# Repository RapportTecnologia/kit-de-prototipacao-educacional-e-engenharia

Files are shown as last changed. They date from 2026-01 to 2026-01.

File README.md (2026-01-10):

# Kit Educacional e Prototipação Rapport


Visits (https://hits.sh/github.com/RapportTecnologia/kit-de-prototipacao-educacional-e-engenharia/)





* **Versão atual:** 0.6

---

## Visão geral

Este repositório contém o projeto do **Kit Educacional e de Prototipação** da Rapport (Kit Educacional e Prototipação Rapport - KEPR), incluindo a documentação do barramento/modularidade (UCE) e os arquivos de CAD eletrônico em KiCad.

O KEPR é um ecossistema de hardware para **prototipação e aprendizagem** em sistemas embarcados e IoT: uma base modular que permite trocar o microcontrolador sem “quebrar” o restante do projeto, além de integrar **módulos de rede e wireless** (WiFi, Bluetooth e outros) quando essas interfaces não estão disponíveis nativamente no módulo principal.

A proposta é reduzir atrito no desenvolvimento (e no estudo) de firmware e hardware, organizando um padrão de conexão e expansão para acelerar testes, validações e iterações. O projeto busca compatibilidade com famílias como **STM32**, **ESP32**, **AVR (ATtiny/ATmega)** e outros fabricantes.

Este projeto nasce inicialmente com fins **educacionais** (estudos e evolução técnica de Carlos Delfino) e **pode vir a se tornar comercial** no futuro. Ainda assim, o projeto permanece sob a mesma licença para que outras pessoas e empresas possam **usar, adaptar e redistribuir** da forma que desejarem.

**Licença:** Creative Commons **CC BY 4.0** (atribuição). Se você quer colaborar, você pode:

- propor melhorias na arquitetura do barramento e dos módulos;
- revisar esquemáticos/footprints e sugerir boas práticas de layout;
- abrir issues com dúvidas, críticas e ideias;
- enviar PRs com correções, melhorias e novos módulos.

---

## Documentação

- **UCE (placa / barramento):** `UCE_BOARD.md`
- **Changelog:** `CHANGELOG.md`

---

## Projeto KiCad

O projeto principal atualmente está em:

- `kicad/KEPR/`

---

## Repositório Git (origem)

- `git@github.com:RapportTecnologia/kit-de-prototipacao-educacional-e-engenharia.git`

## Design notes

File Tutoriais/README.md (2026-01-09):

# Tutoriais


Visits (https://hits.sh/github.com/RapportTecnologia/kit-de-prototipacao-educacional-e-engenharia_Tutoriais_README)

 Esta pasta reúne tutoriais e anotações técnicas para **relembrar** (e padronizar) conceitos de eletrônica usados no desenvolvimento do projeto.
 Como o objetivo do KEPR é educacional, estes textos também servem como material de apoio para quem estiver estudando, montando, depurando ou evoluindo o hardware/firmware.

## Como usar estes tutoriais

- Leia os arquivos na ordem sugerida quando fizer sentido (ex.: alimentação antes de instrumentação).
- Sempre que um tutorial citar referências do repositório (ex.: esquemático, `.ioc` do CubeMX, firmware), use-o como ponto de partida para encontrar a “fonte de verdade” das configurações.
- Quando algo for alterado no hardware/firmware, atualize também o tutorial correspondente para manter a documentação coerente.

## Índice de conteúdos

- **Alimentação e barramentos (Power Rails)**
  - [`POWER.md`](./POWER.md): visão geral dos rails do KEPR, função de cada tensão e boas práticas de uso externo.
- **Medição de corrente com shunt + OPAMP + ADC no STM32G4**
  - [`OPAMPS.md`](./OPAMPS.md): mapeamento de pinos, relação ADC→tensão→corrente, parâmetros de calibração e exemplo numérico.
- **Proteção elétrica (tensão reversa e sobretensão)**
  - [`PROTECAO_TENSAO_REVERSA_E_SOBRETENSAO.md`](./PROTECAO_TENSAO_REVERSA_E_SOBRETENSAO.md): topologias de proteção para rails expostos ao usuário (incluindo bloqueio de backfeed e OVP).

## Objetivo do material

- **Didático**: explicar “por que” e “como” cada bloco do sistema funciona.
- **Prático**: registrar decisões de projeto e facilitar manutenção (debug, troca de componentes, mudanças no CubeMX, etc.).
- **Reutilizável**: permitir que partes do projeto (power, proteção, instrumentação) sejam reaproveitadas em outros designs.

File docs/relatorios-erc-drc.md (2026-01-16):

---
layout: page
title: "Relatórios ERC e DRC"
subtitle: "Saídas do KiCad (ERC/DRC)"
permalink: /relatorios-erc-drc/
---

Esta página é gerada automaticamente pelo CI a partir dos relatórios do KiCad.

## Resumo

### ERC (Electrical Rules Check)

- Gerado em: `2026-01-16T01:00:54+0000`
- Erros: **118**
- Avisos: **153**

### DRC (Design Rules Check)

- Gerado em: `2026-01-16T01:00:56+0000`
- Violações DRC: **177**
- Pads desconectados: **117**
- Erros: **126**
- Avisos: **173**

## Relatórios completos

- [Abrir `erc.rpt`](https://github.com/RapportTecnologia/kit-de-prototipacao-educacional-e-engenharia/blob/main/kicad/KEPR/reports/erc.rpt)
- [Abrir `drc.rpt`](https://github.com/RapportTecnologia/kit-de-prototipacao-educacional-e-engenharia/blob/main/kicad/KEPR/reports/drc.rpt)

## Principais ocorrências (amostra)

### ERC

- `[lib_symbol_issues]: The current configuration does not include the symbol library '10141995-005RLF'`
- `[global_label_dangling]: Global label not connected anywhere else in the schematic`
- `[lib_symbol_issues]: The current configuration does not include the symbol library 'Connector_Generic'`
- `[unconnected_wire_endpoint]: Unconnected wire endpoint`
- `[lib_symbol_issues]: The current configuration does not include the symbol library 'Connector_Generic'`
- `[lib_symbol_issues]: The current configuration does not include the symbol library 'power'`
- `[lib_symbol_issues]: The current configuration does not include the symbol library 'power'`
- `[lib_symbol_issues]: The current configuration does not include the symbol library 'Connector_Generic'`
- `[lib_symbol_issues]: The current configuration does not include the symbol library 'PCM_SL_Pin_Headers'`
- `[lib_symbol_issues]: The current configuration does not include the symbol library 'power'`

### DRC

- `[track_dangling]: Track has unconnected end`
- `[track_dangling]: Track has unconnected end`
- `[track_dangling]: Track has unconnected end`
- `[track_dangling]: Track has unconnected end`
- `[track_dangling]: Track has unconnected end`
- `[track_dangling]: Track has unconnected end`
- `[via_dangling]: Via is not connected or connected on only one layer`
- `[via_dangling]: Via is not connected or connected on only one layer`
- `[via_dangling]: Via is not connected or connected on only one layer`
- `[via_dangling]: Via is not connected or connected on only one layer`

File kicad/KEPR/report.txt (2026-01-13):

Informação: Processando o símbolo 'J24:Connector_PinHeader_2.54mm:PinHeader_2x02_P2.54mm_Vertical'.
Informação: Processando o símbolo 'J8:'.
Informação: Processando o símbolo 'Brd1:SSD1306:128x64OLED'.
Informação: Processando o símbolo 'J10:Connector_PinHeader_2.54mm:PinHeader_2x40_P2.54mm_Vertical'.
Informação: Processando o símbolo 'J11:Connector_PCBEdge:SODIMM-260_DDR4_H4.0-5.2_OrientationStd_Socket'.
Informação: Processando o símbolo 'J12:Connector_PinHeader_2.54mm:PinHeader_1x20_P2.54mm_Vertical'.
Informação: Processando o símbolo 'J13:Connector_PinHeader_2.54mm:PinHeader_2x02_P2.54mm_Vertical'.
Informação: Processando o símbolo 'J16:Connector_PinHeader_2.54mm:PinHeader_1x10_P2.54mm_Vertical'.
Informação: Processando o símbolo 'J17:Connector_PinHeader_2.54mm:PinHeader_1x20_P2.54mm_Vertical'.
Informação: Processando o símbolo 'J19:Connector_PinHeader_2.54mm:PinHeader_1x20_P2.54mm_Vertical'.
Informação: Processando o símbolo 'J22:Barrel Jack:BarrelJack_Horizontal'.
Informação: Processando o símbolo 'J23:Connector_PinHeader_2.54mm:PinHeader_1x10_P2.54mm_Vertical'.
Informação: Processando o símbolo 'J9:Connector_PinHeader_2.54mm:PinHeader_2x40_P2.54mm_Vertical'.
Informação: Processando o símbolo 'J26:Connector_PinHeader_2.54mm:PinHeader_2x03_P2.54mm_Vertical'.
Informação: Processando o símbolo 'J30:Connector_PinHeader_2.54mm:PinHeader_2x02_P2.54mm_Vertical'.
Informação: Processando o símbolo 'PS1:TDN 5WISM Series, 5 Watt:CONV_TDN5-2411WISM'.
Informação: Processando o símbolo 'PS2:TDN 5WISM Series, 5 Watt:CONV_TDN5-2411WISM'.
Informação: Processando o símbolo 'PS3:TDN 5WISM Series, 5 Watt:CONV_TDN5-2411WISM'.
Informação: Processando o símbolo 'U1:REF193:SOIC127P600X175-8N'.
Informação: Processando o símbolo 'U2:Package_QFP:LQFP-48_7x7mm_P0.5mm'.
Informação: Processando o símbolo 'U3:Package_TO_SOT_SMD:SOT-223-3_TabPin2'.
Informação: Processando o símbolo 'U4:Package_TO_SOT_SMD:SOT-223-3_TabPin2'.
Informação: Total de avisos: 5, erros: 2.
Informação: Processando o símbolo 'J4:Connector_IDC:IDC-Header_2x15-1MP_P2.54mm_Latch_Vertical'.
Informação: Processando o símbolo 'IC1:APS12628LLHALTBAP'.
Informação: Processando o símbolo 'IC2:APS12628LLHALTBAP'.
Informação: Processando o símbolo 'C5:Capacitor:C_0805_2012Metric'.
Informação: Processando o símbolo 'IC3:APS12628LLHALTBAP'.
Informação: Processando o símbolo 'C4:Capacitor:C_0805_2012Metric'.
Informação: Processando o símbolo 'C3:Capacitor:C_0805_2012Metric'.
Informação: Processando o símbolo 'J1:Connector_PinHeader_2.54mm:PinHeader_1x20_P2.54mm_Vertical'.
Informação: Processando o símbolo 'J3:Connector_IDC:IDC-Header_2x12_P2.54mm_Latch9.5mm_Vertical'.
Informação: Processando o símbolo 'C2:Capacitor:C_0805_2012Metric'.
Informação: Processando o símbolo 'C1:Capacitor:C_0805_2012Metric'.
Informação: Processando o símbolo 'BT1:Battery:BatteryHolder_Multicomp_BC-2001_1x2032'.
Informação: Processando o símbolo 'J5:Connector_IDC:IDC-Header_2x08_P2.54mm_Latch12.0mm_Vertical'.
Informação: Processando o símbolo 'J6:Connector_PinHeader_2.54mm:PinHeader_2x20_P2.54mm_Vertical'.
Informação: Processando o símbolo 'J7:'.
Adiciona Brd1 (footprint 'SSD1306:128x64OLED').

Troca o footprint IC1 de 'ACS37041:APS12628LLHALTBAP' para 'APS12628LLHALTBAP'.
Troca o footprint IC2 de 'ACS37041:APS12628LLHALTBAP' para 'APS12628LLHALTBAP'.
Troca o footprint IC3 de 'ACS37041:APS12628LLHALTBAP' para 'APS12628LLHALTBAP'.
Atenção: Nenhuma rede foi encontrada para o componente J22 ilha 3 (nenhum pino 3 no símbolo).
Atenção: Nenhuma rede foi encontrada para o componente J4 ilha MP (nenhum pino MP no símbolo).
Atenção: Nenhuma rede foi encontrada para o componente J4 ilha MP (nenhum pino MP no símbolo).
Atenção: Nenhuma rede foi encontrada para o componente J11 ilha MP (nenhum pino MP no símbolo).
Atenção: Nenhuma rede foi encontrada para o componente J11 ilha MP (nenhum pino MP no símbolo).
Erro: Não é possível adicionar J8 (nenhum footprint associado).
Erro: Não é possível adicionar J7 (nenhum footprint associado).

Informação: Total de avisos: 5, erros: 2.

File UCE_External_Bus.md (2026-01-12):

# UCE – External Bus (UCE_External_Bus)

* **Versão:** 0.6
* **Fonte:** `kicad/KEPR/UCE_External_Bus.kicad_sch` e `UCE_BOARD.md`

---

## 1. Objetivo

Este documento descreve o **barramento externo** da arquitetura **UCE (Universal Carrier Ecosystem)**, isto é, o conjunto de sinais expostos pela Carrier/Baseboard para conexão com:

- Periféricos externos (sensores, atuadores, módulos)
- Placas de expansão
- Cabeamento/painel/IO externo

A intenção é padronizar um **contrato elétrico e funcional** para que diferentes módulos MCU/SoC possam ser trocados sem alterar a base, conforme definido em `UCE_BOARD.md`.

---

## 2. Convenções e Domínios Elétricos

### 2.1 Domínios de alimentação

Os seguintes domínios aparecem na especificação do UCE e são utilizados/propagados no barramento:

- `VCC_12V`
- `VCC_5V`
- `VCC_3V3`
- `VCC_1V8`
- `GND`

### 2.2 Referência e níveis lógicos

- `VREF_IO`: referência de IO (associada ao domínio lógico exposto).
- `PWR_GOOD`: sinal de “power good” do sistema.

### 2.3 Direção dos sinais

Neste documento:

- **`MCU → EXT`** significa sinal dirigido do módulo MCU para o conector externo.
- **`EXT → MCU`** significa sinal dirigido do conector externo para o módulo MCU.
- **`Bidirecional`** significa que a direção depende da aplicação (ex.: I²C) ou é intrinsecamente bidirecional.

> Observação: no esquemático KiCad, os `global_label` não carregam semântica de direção; portanto, as direções abaixo seguem a convenção típica de cada barramento.

---

## 3. Conectores presentes no esquemático

No `UCE_External_Bus.kicad_sch` aparecem, no mínimo, os seguintes conectores:

- **J1**: `Conn_02x20_Odd_Even` (2x20)
- **J3**: `Conn_02x40_Odd_Even` (2x40)
- **J4**: `Conn_02x40_Odd_Even` (2x40)

> Importante: a **pinagem (pino ↔ sinal)** não fica diretamente disponível como texto simples no `.kicad_sch` (a conectividade é definida por geometrias/UUIDs). Para gerar uma tabela 100% fiel automaticamente, o caminho mais robusto é exportar **netlist/BOM** via KiCad ou gerar um relatório de conectividade. Se você quiser, eu consigo completar a pinagem com base em um export (ex.: netlist IPC-2581/CSV/pos/relatório do KiCad) que você me fornecer.

---

## 4. Catálogo de sinais do Barramento Externo

Abaixo está o catálogo dos sinais observados no esquemático (principalmente via `global_label`) e alinhados à nomenclatura da UCE.

### 4.1 Alimentação e controle

| Sinal | Tipo | Direção  | Observação |
| --- | --- | --- | --- |
| `VCC_12V` | Power | — | Alimentação 12 V |
| `VCC_5V` | Power | — | Alimentação 5 V |
| `VCC_3V3` | Power | — | Alimentação 3,3 V |
| `VCC_1V8` | Power | — | Alimentação 1,8 V |
| `GND` | Power | — | Terra |
| `VREF_IO` | Referência  | — | Referência para IO/level shifting |
| `PWR_GOOD`  | Status | MCU → EXT | Indica tensões estáveis (ou habilitação do domínio) |

### 4.2 Sinais de boot/reset/enable

| Sinal | Tipo | Direção  | Observação |
| --- | --- | --- | --- |
| `MCU_EN` | Controle | EXT → MCU | Enable do módulo/MCU (conforme arquitetura) |
| `MCU_BOOT0` | Controle | EXT → MCU | Seleção de boot/perfil (dependente do MCU) |

### 4.3 I²C

| Sinal | Tipo | Direção | Observação |
| --- | ---- | --- | --- |
| `I2C0_SDA` | I²C | Bidirecional (open-drain) | Data I²C0  |
| `I2C0_SCL` | I²C | Bidirecional (open-drain) | Clock I²C0  |
| `I2C1_SDA` | I²C | Bidirecional (open-drain) | Data I²C1  |
| `I2C1_SCL` | I²C | Bidirecional (open-drain) | Clock I²C1  |
| `I2C2_SDA` | I²C | Bidirecional (open-drain) | Data I²C2 |
| `I2C2_SCL` | I²C | Bidirecional (open-drain) | Clock I²C2  |

> Nota: o esquemático listado aqui inclui alguns sinais I²C pontuais; a UCE prevê pares `SCL/SDA` por barramento.

### 4.4 SPI

#### SPI0

| Sinal | Tipo | Direção  | Observação |
| --- | ---- | --- | --- |
| `SPI0_SCK`  | SPI  | MCU → EXT | Clock |
| `SPI0_MOSI` | SPI  | MCU → EXT | Master Out / Slave In |
| `SPI0_MISO` | SPI  | EXT → MCU | Master In / Slave Out |
| `SPI0_CS0`  | SPI  | MCU → EXT | Chip Select 0 |
| `SPI0_CS1`  | SPI  | MCU → EXT | Chip Select 1 |

#### SPI1

| Sinal | Tipo | Direção  | Observação  |
| --- | ---- | --- | --- |
| `SPI1_CS0` | SPI  | MCU → EXT | Chip Select 0 |
| `SPI1_SCK` | SPI  | MCU → EXT | Clock |
| `SPI1_MOSI` | SPI  | MCU → EXT | Master Out / Slave In |
| `SPI1_MISO` | SPI  | EXT → MCU | Master In / Slave Out |

### 4.5 UART

| Sinal | Tipo | Direção  | Observação |
| --- | ---- | --- | --- |
| `UART0_TX` | UART | MCU → EXT | Transmit |
| `UART0_RX` | UART | EXT → MCU | Receive |
| `UART1_TX` | UART | MCU → EXT | Transmit |
| `UART1_RX` | UART | EXT → MCU | Receive |
| `UART2_TX` | UART | MCU → EXT | Transmit |
| `UART2_RX` | UART | EXT → MCU | Receive |

> Nota: a UCE define `UART0..UART3` e, no caso da `UART0`, sinais de controle adicionais. Nem todos aparecem explicitamente neste sheet do barramento externo.

### 4.6 GPIO e PWM

| Sinal | Tipo | Direção | Observação |
| --- | ---- | --- | --- |
| `GPIO1` | GPIO | Bidirecional | Uso geral |
| `GPIO3` | GPIO | Bidirecional | Uso geral |
| `GPIO6` | GPIO | Bidirecional | Uso geral |
| `GPIO7` | GPIO | Bidirecional | Uso geral |
| `GPIO8` | GPIO | Bidirecional | Uso geral |
| `GPIO9` | GPIO | Bidirecional | Uso geral |
| `PWM1`  | PWM  | MCU → EXT | Saída PWM |
| `PWM3`  | PWM  | MCU → EXT | Saída PWM |
| `PWM6`  | PWM  | MCU → EXT | Saída PWM |

### 4.7 IR

| Sinal | Tipo | Direção  | Observação |
| --- | ---- | --- | --- |
| `IR_TX_OUT` | IR | MCU → EXT | Transmissão IR |

### 4.8 Analógicos (ADC/DAC)

| Sinal | Tipo | Direção  | Observação |
| --- | --- | --- | --- |
| `AIN3`  | Analógico | EXT → MCU | Entrada analógica |
| `AOUT1` | Analógico | MCU → EXT | Saída analógica  |

### 4.9 Áudio (I²S)

| Sinal | Tipo | Direção  | Observação |
| --- | ---- | --- | --- |
| `I2S_BCLK` | I²S | MCU → EXT | Bit clock |
| `I2S_LRC` | I²S | MCU → EXT | Left/Right clock |
| `I2S_SD` | I²S | MCU → EXT | Serial data |

### 4.10 SDIO

| Sinal | Tipo | Direção | Observação |
| --- | ---- | --- | --- |
| `SDIO_D0` | SDIO | Bidirecional | Data 0 |
| `SDIO_D2` | SDIO | Bidirecional | Data 2 |

### 4.11 Debug

| Sinal | Tipo | Direção | Observação |
| --- | --- | --- | --- |
| `DBG_VREF` | Debug ref | — | Referência do domínio de debug |

### 4.12 Reservados

O esquemático contém múltiplos sinais rotulados como `RESERVED`. Estes pinos/sinais estão reservados para expansão futura, uso específico de variantes, ou compatibilidade.

---

## 5. Recomendações de uso

- **Respeite `VIO_BANKx`**: ao conectar periféricos, considere o banco de IO associado e o nível lógico esperado (3V3/5V/1V8).
- **I²C (open-drain)**: use pull-ups coerentes com `VIO_BANKx`/`VREF_IO` e com o perfil do módulo.
- **SPI**: mantenha `SCK/MOSI/MISO/CSx` curtos em cabo/placa de expansão, e considere GND adjacente quando disponível.
- **Analógico**: trate `AINx/AOUTx` como sinais sensíveis (roteamento/filtragem/impedância de fonte).

---

## 6. Como completar a pinagem (pino ↔ sinal)

Se você quiser que eu gere tabelas de pinagem do tipo “J3 pino 1 = …”, preciso de uma fonte de conectividade exportada pelo KiCad, por exemplo:

- Export de netlist/relatório de conectividade
- Print/CSV de “Pin assignments” do conector
- Ou um PDF do esquemático (para leitura visual)

Com isso, eu atualizo este arquivo adicionando:

- Tabela por conector (J1/J3/J4)
- Mapa por função (Power/IO/Bus) indicando exatamente onde cada sinal está.

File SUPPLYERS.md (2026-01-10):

Neste arquivo reuno sites que são referência em componentes, distribuidores e fontes de Simbolos, Footprints e modelos 3D (principalmente para KiCad), além de fabricantes de PCBs.

## Fornecedores (componentes eletrônicos)

### Distribuidores globais

* <https://www.mouser.com/>
* <https://www.digikey.com/>
* <https://www.arrow.com/>
* <https://www.farnell.com/> (element14 / Newark)
* <https://www.rs-online.com/>
* <https://www.tme.eu/>
* <https://lcsc.com/> (muito usado junto ao ecossistema JLCPCB)

### Marketplaces / varejo

* <https://www.aliexpress.com/>
* <https://www.amazon.com/> (varia por região)
* <https://www.ebay.com/>

### Brasil (exemplos)

* <https://www.baudaeletronica.com.br/>
* <https://www.filipeflop.com/>
* <https://www.usinainfo.com.br/>
* <https://www.multcomercial.com.br/> (Multi Comercial)
* <https://www.mercadolivre.com.br/>

## Símbolos / Footprints / Modelos 3D (KiCad)

### Bibliotecas oficiais / base

* <https://www.kicad.org/libraries/> (bibliotecas oficiais do KiCad)
* <https://gitlab.com/kicad/libraries> (repositórios oficiais: símbolos, footprints e 3D)
* <https://gitlab.com/kicad/libraries/kicad-footprints>

### Bibliotecas e geradores comunitários

* <https://www.snapeda.com/> (símbolos/footprints e alguns modelos 3D)
* <https://www.samacsys.com/> (Library Loader; exporta para KiCad)
* <https://www.ultralibrarian.com/> (CAD + símbolos/footprints)
* <https://componentsearchengine.com/>

### Modelos 3D (STEP/WRL)

* <https://grabcad.com/library>
* <https://www.traceparts.com/>
* <https://www.3dcontentcentral.com/>
* <https://www.partcommunity.com/>

### Plugins / ferramentas úteis (KiCad)

* <https://www.kicad.org/external-tools/> (ecossistema de ferramentas e integrações)
* <https://github.com/easyw/kicad-stepup> (KiCad <-> FreeCAD: STEP, posicionamento e ajustes 3D)

## Fabricantes de PCB / PCBA

* <https://jlcpcb.com/> (PCB e montagem/PCBA)
* <https://www.pcbway.com/> (PCB e montagem/PCBA)
* <https://www.seeedstudio.com/fusion_pcb.html> (Seeed Fusion)
* <https://www.elecrow.com/pcb-manufacturing.html> (Elecrow)
* <https://oshpark.com/> (ótimo para protótipos pequenos; foco EUA)
* <https://aisler.net/> (foco UE; boa experiência para prototipagem)
* <https://www.allpcb.com/>

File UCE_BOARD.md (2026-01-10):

# UCE – Universal Carrier Ecosystem

* **Versão:** 0.6
  **Status:** Draft de Arquitetura
  **Autor:** Carlos Delfino
  **Objetivo:** Plataforma universal modular para microcontroladores e SoCs para prototipação e aprendizado IoT e Embarcado

---

## 1. Visão Geral

O **UCE – Universal Carrier Ecosystem** é uma arquitetura modular de hardware projetada para permitir a substituição transparente de:

- Microcontroladores (ATtiny, ATmega, ESP32, STM32, NXP, etc.)
- SoCs com maior capacidade (ex.: Cortex-A)
- Módulos de rede (SPI Ethernet, RMII, RGMII/Switch)
- Módulos de gravação e depuração (J-Link, J-ICE, CMSIS-DAP, AVR-ISP, etc.)

sem a necessidade de alterar a **placa base (Carrier)**.

A proposta é criar um **contrato elétrico e funcional** entre módulos, inspirado em padrões industriais como SMARC e COM Express, porém adaptado ao universo de MCUs.

---

## 2. Arquitetura do Sistema

O ecossistema é composto por quatro blocos principais:

- **Carrier/Baseboard (fixa)**Fornece alimentação, conectores externos, level shifting por bancos, proteção e roteamento.
- **MCU Module (trocável)**Contém o microcontrolador/SoC, clock, boot, debug e opcionalmente ADC/DAC externos acoplados.
- **Network Module (trocável)**Implementa Ethernet conforme capacidade do MCU:

  - SPI: W5500 / ENC28J60
  - RMII: PHY dedicado
  - RGMII: Switch KSZ9893 ou similar
- **Debug/Program Module (trocável)**
  Implementa SWD, JTAG, ISP, UPDI, Serial Boot, USB-Debug, etc.

---

## 3. Princípios de Projeto

- A **base não conhece o MCU**, apenas o contrato UCE
- ADC e DAC pertencem ao **MCU Module**
- Ethernet é **sempre modular**
- Debug/Gravação é **sempre modular**
- Todos os sinais externos passam por **level shifting por bancos**
- O **módulo informa suas capacidades e níveis elétricos**

---

## 4. Domínios de Tensão e Level Shifting

- Domínio externo padrão: **3,3 V**
- Suporte a módulos **5 V** e **1,8 V**
- Bancos independentes com seleção:
  - OFF / 3V3 / 5V
- O módulo MCU informa:
  - VIO por banco
  - Capacidades elétricas
- A base protege contra seleções inválidas
- Pinos de alimentação e referência são disponibilizados em três regiões do conector (bordas e miolo), incluindo **VCC_5V**, **VCC_3V3**, **VCC_1V8**, **VREF_IO**, **VIO_BANKx** e **PWR_GOOD**, com múltiplos **GND** adjacentes para facilitar roteamento e level shifting

---

## 5. Clock

- O módulo MCU fornece o clock principal
- Pinos CLOCK_0 e CLOCK_1 disponíveis para a UCE como referência
- Suporte a múltiplos cristais e osciladores definidos pelo módulo
- Frequências variáveis conforme necessidade do módulo
- Pinos CLOCK_0 e CLOCK_1 podem ser usados para sincronização entre módulos
- A UCE pode configurar o clock conforme necessário
- Informações sobre o Clock podem ser obtidas na eeprom de identificação.

## 5. ADC, DAC e Áudio (I²S)

### ADC / DAC

- Entradas analógicas (`AINx`) e saídas (`AOUTx`) são roteadas até o MCU Module
- O módulo pode:
  - Usar ADC/DAC internos do MCU
  - Implementar ADC/DAC externos via SPI, I²C ou I²S
- A base apenas condiciona e externaliza os sinais

### I²S

Externalização direta para uso com:

- Microfones digitais
- Codecs de áudio
- DACs I²S

Sinais reservados:

- BCLK, LRCLK, DIN, DOUT, MCLK (opcional)

---

## 6. Identificação do Módulo (ID)

Cada MCU Module deve possuir um dispositivo de identificação (EEPROM I²C), informando:

- Família do MCU
- Níveis elétricos por banco
- Presença de ADC, DAC, I²S
- Perfil de debug
- Perfil de rede suportado

Isso permite:

- Uso assistido da plataforma
- Redução de erros elétricos
- Escalabilidade do ecossistema

---

## 7. Mapa de Pinos – Conector MCU Module (SO-DIMM 200 pinos)

### Convenção

- **Coluna 1:** Pinos ímpares (1 → 199) — lado esquerdo
- **Coluna 2:** Descrição pinos ímpares
- **Coluna 3:** Descrição pinos pares
- **Coluna 4:** Pinos pares (2 → 200) — lado direito

---

### Tabela de Pinagem (Resumo Funcional)

| Ímpar | Descrição (Ímpar) | Descrição (Par) | Par |
| -----: | --- | --- | :--- |
| 1 | GND | GND | 2 |
| 3 | GND | GND | 4 |
| 5 | VCC_5V | VCC_5V | 6 |
| 7 | VCC_3V3 | VCC_3V3 | 8 |
| 9 | VCC_1V8 | VCC_1V8 | 10  |
| 11 | VREF_IO | VREF_IO | 12  |
| 13 | VIO_BANK0 | VIO_BANK1 | 14  |
| 15 | VIO_BANK2 | VIO_BANK3 | 16  |
| 17 | PWR_GOOD | PWR_GOOD | 18  |
| 19 | GND | GND | 20  |
| 21 | GND | GND | 22  |
| 23 | VCC_IN | GND | 24  |
| 25 | MCU_RESET_N | MCU_EN | 26  |
| 27 | MCU_BOOT0 | MCU_BOOT1 | 28  |
| 29 | I2C0_SCL | I2C0_SDA | 30  |
| 31 | I2C1_SCL | I2C1_SDA | 32  |
| 33 | I2C2_SCL | I2C2_SDA | 34  |
| 35 | UART0_TX | UART0_RX | 36  |
| 37 | UART1_TX | UART1_RX | 38  |
| 39 | UART2_TX | UART2_RX | 40  |
| 41 | UART3_TX | UART3_RX | 42  |
| 43 | UART0_CTS | UART0_RTS | 44  |
| 45 | UART0_DSR | UART0_DCD | 46  |
| 47 | UART0_RI | GND | 48  |
| 49 | SPI0_SCK | SPI0_MOSI | 50  |
| 51 | SPI0_MISO | SPI0_CS0 | 52  |
| 53 | SPI0_CS1 | SPI0_CS2 | 54  |
| 55 | SPI1_SCK | SPI1_MOSI | 56  |
| 57 | SPI1_MISO | SPI1_CS0 | 58  |
| 59 | SPI1_CS1 | SPI1_CS2 | 60  |
| 61 | GPIO0 | GPIO8 | 62  |
| 63 | GPIO1 | GPIO9 | 64  |
| 65 | GPIO2 | GPIO10 | 66  |
| 67 | GPIO3 | GPIO11 | 68  |
| 69 | GPIO4 | GPIO12 | 70  |
| 71 | GPIO5 | GPIO13 | 72  |
| 73 | GPIO6 | GPIO14 | 74  |
| 75 | GPIO7 | GPIO15 | 76  |
| 77 | PWM0 | PWM4 | 78  |
| 79 | PWM1 | PWM5 | 80  |
| 81 | PWM2 | PWM6 | 82  |
| 83 | PWM3 | PWM7 | 84  |
| 85 | IR_RX_IN | IR_TX_OUT | 86  |
| 87 | AIN0 | AIN4 | 88  |
| 89 | AIN1 | AIN5 | 90  |
| 91 | AIN2 | AIN6 | 92  |
| 93 | AIN3 | AIN7 | 94  |
| 95 | AOUT0 | AOUT1 | 96  |
| 97 | I2S_BCLK | I2S_LRCLK | 98  |
| 99 | I2S_DOUT | I2S_DIN | 100 |
| 101 | I2S_MCLK | GND | 102 |
| 103 | NET_SPI_SCK | NET_SPI_MOSI | 104 |
| 105 | NET_SPI_MISO | NET_SPI_CS | 106 |
| 107 | NET_INT_N | NET_RST_N | 108 |
| 109 | RMII_TXD0 | RMII_TXD1 | 110 |
| 111 | RMII_RXD0 | RMII_RXD1 | 112 |
| 113 | RMII_TXEN | RMII_CRS_DV | 114 |
| 115 | RMII_REFCLK | sMDC | 116 |
| 117 | MDIO | PHY_RST_N | 118 |
| 119 | SDIO_CLK | SDIO_CMD | 120 |
| 121 | SDIO_D0 | SDIO_D1 | 122 |
| 123 | SDIO_D2 | SDIO_D3 | 124 |
| 125 | Reservado / Futuro | Reservado / Futuro | 126 |
| 127 | GND | GND | 128 |
| 129 | GND | GND | 130 |
| 131 | VCC_5V | VCC_5V | 132 |
| 133 | VCC_3V3 | VCC_3V3 | 134 |
| 135 | VCC_1V8 | VCC_1V8 | 136 |
| 137 | VREF_IO | VREF_IO | 138 |
| 139 | VIO_BANK0 | VIO_BANK1 | 140 |
| 141 | VIO_BANK2 | VIO_BANK3 | 142 |
| 143 | PWR_GOOD | PWR_GOOD | 144 |
| 145 | GND | GND | 146 |
| 147 | GND | GND | 148 |
| 149 | CLOCK_0 | CLOCK_1 | 150 |
| 151–163 | Reservado / Futuro | Reservado / Futuro | 150–164 |
| 165 | DBG_SWDIO | DBG_SWCLK | 166 |
| 167 | DBG_TCK | DBG_TMS | 168 |
| 169 | DBG_TDI | DBG_TDO | 170 |
| 171 | DBG_RESET_N | DBG_VREF | 172 |
| 173 | DBG_UART_TX | DBG_UART_RX | 174 |
| 175 | MOD_PRESENT_N | MOD_TYPE0 | 176 |
| 177 | MOD_TYPE1 | MOD_TYPE2 | 178 |
| 179 | GND | GND | 180 |
| 181 | GND | GND | 182 |
| 183 | VCC_5V | VCC_5V | 184 |
| 185 | VCC_3V3 | VCC_3V3 | 186 |
| 187 | VCC_1V8 | VCC_1V8 | 188 |
| 189 | VREF_IO | VREF_IO | 190 |
| 191 | VIO_BANK0 | VIO_BANK1 | 192 |
| 193 | VIO_BANK2 | VIO_BANK3 | 194 |
| 195 | PWR_GOOD | PWR_GOOD | 196 |
| 197 | GND | GND | 198 |
| 199 | GND | GND | 200 |

---

### UART/USART (Portas Seriais)

- **UART0 (Serial0)** é a porta serial principal e inclui sinais de modem/controle além de `TX/RX`:
  - `UART0_TX`, `UART0_RX`, `UART0_CTS`, `UART0_RTS`, `UART0_DSR`, `UART0_DCD`, `UART0_RI`
- **UART1–UART3 (Serial1–Serial3)** expõem apenas `TX/RX`.
- **Compartilhamento de sinais de controle**: se a aplicação não utilizar os sinais de controle da `UART0` (ex.: `CTS/RTS/DSR/DCD/RI`), estes pinos podem ser reaproveitados como sinais auxiliares/controle para as demais UARTs na Carrier, desde que o firmware e o roteamento definam claramente essa multiplexação.

## 8. Conclusão

O **UCE** cria um ecossistema coerente, escalável e didático, permitindo:

- Desenvolvimento educacional
- Prototipagem rápida
- Produtos semi-industriais
- Evolução contínua sem obsolescência da base

A arquitetura separa claramente:

- **processamento**
- **conectividade**
- **depuração**
- **interfaces externas**

tornando o sistema sustentável a longo prazo.

---

## 9. Próximos Passos (v0.4)

- Diagrama de blocos completo
- Especificação elétrica por banco
- Regras de roteamento PCB
- Exemplos de módulos (AVR, STM32, ESP32)
- Guia de firmware de inicialização por perfil

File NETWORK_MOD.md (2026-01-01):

# NETWORK_MOD – Módulo de Rede Cabeada (Header genérico 2x10)

## 1. Objetivo

O **NETWORK_MOD** é um módulo encaixável na Carrier cuja função é prover **conectividade Ethernet cabeada** sem alterar a placa base.

A arquitetura do UCE prevê que Ethernet seja sempre modular, suportando diferentes perfis conforme capacidade do MCU/SoC, por exemplo:

- SPI Ethernet (ex.: W5500 / ENC28J60)
- RMII (PHY dedicado)
- RGMII (switch/PHYs) *(fora do escopo deste conector 2x10; ver seção 6)*

## 2. Conector do módulo

- **Tipo:** Header genérico **2x10 (fêmea)**
- **Total de vias:** 20

### 2.1 Numeração física (padrão 2xN)

- Pino **1** no canto com a marcação (chanfro/triângulo) do conector
- **Ímpares** em uma coluna (1,3,5,7,9,11,13,15)
- **Pares** na outra coluna (2,4,6,8,10,12,14,16)

## 3. Perfis suportados pelo NETWORK_MOD

Este conector suporta dois perfis principais. A Carrier e o MCU Module devem selecionar **um perfil por vez**:

- **Perfil A (RMII + MDIO/MDC)**: indicado quando o MCU expõe RMII.
- **Perfil B (SPI Ethernet)**: indicado para MCUs sem MAC Ethernet, usando controladores SPI.

Os pinos do conector são nomeados de forma a permitir reutilização por perfil.

## 4. Pinagem do NETWORK_MOD

| Pino | Nome canônico no conector | Perfil A (RMII) | PINO | Perfil B (SPI Ethernet) |
| ---: | --- | --- | --- | ---|
|  1 | `GND` | `GND` |  2 | GND |
|  3 | `VCC_3V3` | `VCC_3V3` |  4 | VCC_3V3 |
|  5 | `NET_CLK` | `RMII_REFCLK` |  6 | NET_SPI_CLK  |
|  7 | `NET_CMD` | `MDIO` |  8 | RESERVADO |
|  9 | `NET_D0` | `RMII_TXD0` | 10 | NET_SPI_MOSI |
| 11 | `NET_D1` | `RMII_TXD1` | 12 | RESERVADO |
| 13 | `NET_D2` | `RMII_RXD0` | 14 | NET_SPI_MISO |
| 15 | `NET_D3` | `RMII_RXD1` | 16 | RESERVADO |
| 17 | `NET_CTL0`  | `RMII_TXEN` | 18 | NET_SPI_CS |
| 19 | `NET_CTL1`  | `RMII_CRS_DV` | 20 | NET_INT_N |
| 21 | `NET_CTL2`  | `sMDC` | 22 | RESERVADO |
| 23 | `NET_RST_N` | `PHY_RST_N` | 24 | NET_RST_N |

## 5. Regras elétricas e de integração

- O módulo deve operar em **3,3 V** no lado lógico do barramento do UCE, salvo quando explicitamente definido pela Carrier.
- Para **RMII**, manter atenção ao **clock** (`RMII_REFCLK`) e retorno de corrente: preferir planos de GND e pares adjacentes onde possível.
- Para **MDIO/MDC**, observar pull-ups e nível lógico; idealmente o módulo deve ser tolerante ao nível informado pelo sistema (quando aplicável).
- Sinais `*_RST_N` e `*_INT_N` são **ativos em nível baixo**.

## 6. Observações sobre RGMII/Switch

RGMII e/ou switch Ethernet tipicamente exige mais sinais do que cabem neste conector 2x8 (ex.: múltiplos TX/RX data, clocks adicionais e controles). Para estes casos, recomenda-se:

- Um conector dedicado com mais vias, ou
- Um perfil alternativo que utilize outro barramento/slot na Carrier.

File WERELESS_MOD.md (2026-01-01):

# WIRELESS_MOD – Módulo Wireless para WiFI e Bluetooth Classico e LE (Header genérico 2x8)

## 1. Objetivo

O **WIRELESS_MOD** é um módulo encaixável na Carrier cuja função é prover **conectividade Wi‑Fi e Blueetoh** por meio de módulos baseados em:

- ESP32 (ex.: ESP32-WROOM / ESP32-C3/S3 em variantes com interface externa)
- NRF (ex.: nRF7002 para Wi‑Fi, ou módulos combo conforme fornecedor)
- STM (ex.: módulos/solutions com Wi‑Fi controlado por host)

O objetivo é permitir trocar o “módulo de rádio” sem alterar a placa base, mantendo um contrato de sinais estável.

## 2. Conector do módulo

- **Tipo:** Header genérico **2x8**
- **Total de vias:** 16

### 2.1 Numeração física (padrão 2xN)

- Pino **1** no canto com a marcação (chanfro/triângulo) do conector
- **Ímpares** em uma coluna (1,3,5,7,9,11,13,15)
- **Pares** na outra coluna (2,4,6,8,10,12,14,16)

## 3. Barramentos suportados

O WIFI_MOD pode ser implementado com diferentes interfaces de host, dependendo do módulo adotado:

- **SDIO (recomendado quando disponível)**: maior throughput, adequado para Wi‑Fi.
- **SPI**: comum em módulos mais simples ou em bridges.
- **UART**: útil para AT firmware/bridge, provisioning e debug; throughput limitado para tráfego.

Este documento padroniza o conector com foco em **SDIO**, mas prevendo fallback.

## 4. Pinagem do WIRELESS_MOD

Os pinos são nomeados para suportar **SDIO** como perfil principal. Quando um módulo não suportar SDIO, os pinos podem ser reinterpretados conforme a seção 5.

| Pino | Nome canônico no conector | Função principal (SDIO) |
| ---: | --- | --- |
| 1 | `GND` | `GND` |
| 2 | `VCC_3V3` | `VCC_3V3` |
| 3 | `SDIO_CLK` | `SDIO_CLK` |
| 4 | `SDIO_CMD` | `SDIO_CMD` |
| 5 | `SDIO_D0` | `SDIO_D0` |
| 6 | `SDIO_D1` | `SDIO_D1` |
| 7 | `SDIO_D2` | `SDIO_D2` |
| 8 | `SDIO_D3` | `SDIO_D3` |
| 9 | `WIFI_EN` | Enable do módulo (se aplicável) |
| 10 | `WIFI_RST_N` | Reset do módulo (ativo baixo) |
| 11 | `WIFI_INT_N` | Interrupt/Host wake (ativo baixo) |
| 12 | `UART0_TX` | Canal UART auxiliar (TX do host)  |
| 13 | `RESERVADO` | `RESERVADO` |
| 14 | `UART0_RX` | Canal UART auxiliar (RX do host)  |
| 15 | `RESERVADO` | `RESERVADO` |
| 16 | GND | GND |

## 5. Mapeamentos alternativos (quando não houver SDIO)

Quando o módulo adotado **não** suportar SDIO, recomenda-se um destes perfis alternativos:

### 5.1 Perfil SPI (módulo Wireless via SPI)

Reaproveitar as linhas SDIO como SPI:

- `SDIO_CLK`  -> `SPI_SCK`
- `SDIO_CMD`  -> `SPI_MOSI`
- `SDIO_D0`   -> `SPI_MISO`
- `SDIO_D1`   -> `SPI_CS`
- `SDIO_D2`   -> `RESERVADO` (ou `SPI_CS2` se necessário)
- `SDIO_D3`   -> `RESERVADO`

E manter:

- `WIFI_INT_N`, `WIFI_RST_N`, `WIFI_EN` conforme disponível.

### 5.2 Perfil UART (módulo/bridge AT)

Usar:

- `UART0_TX`, `UART0_RX` como interface principal
- `WIFI_EN` / `WIFI_RST_N` para controle

As linhas `SDIO_*` permanecem `RESERVADO`.

## 6. Regras elétricas e de integração

- **Alimentação:** o conector fornece `VCC_3V3`.
- **Nível lógico:** idealmente 3,3 V, mas o módulo deve ser escolhido de forma compatível com o domínio de IO do host/Carrier.
- **Sinais ativos baixo:** `WIFI_RST_N` e `WIFI_INT_N`.
- **RF:** antena (U.FL/IPEX ou PCB) e keep-out são responsabilidade do WIFI_MOD; a Carrier não deve rotear RF.

## 7. Observações por família de módulos

- **ESP32:** muitas variações expõem SPI/UART; SDIO depende do módulo/solução. Quando o ESP32 for o “host” (MCU+Wi‑Fi no mesmo chip), este documento serve mais para módulos “coprocessor”/bridge.
- **NRF:** para Wi‑Fi, considerar soluções como nRF7002 (tipicamente SDIO/SPI conforme integração).
- **STM:** soluções de Wi‑Fi podem usar SDIO/SPI/UART dependendo do módulo e stack.

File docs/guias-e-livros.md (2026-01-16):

---
layout: page
title: "Guias e Livros"
subtitle: "Materiais de referência usados no projeto"
permalink: /guias-e-livros/
is_category: true
---

Os materiais de referência ficam na pasta `Guias e Livros/` no repositório.

## Geral

| Capa | Título | Autor | Idioma | Data | Assunto | Arquivo |
| --- | --- | --- | --- | --- | --- | --- |
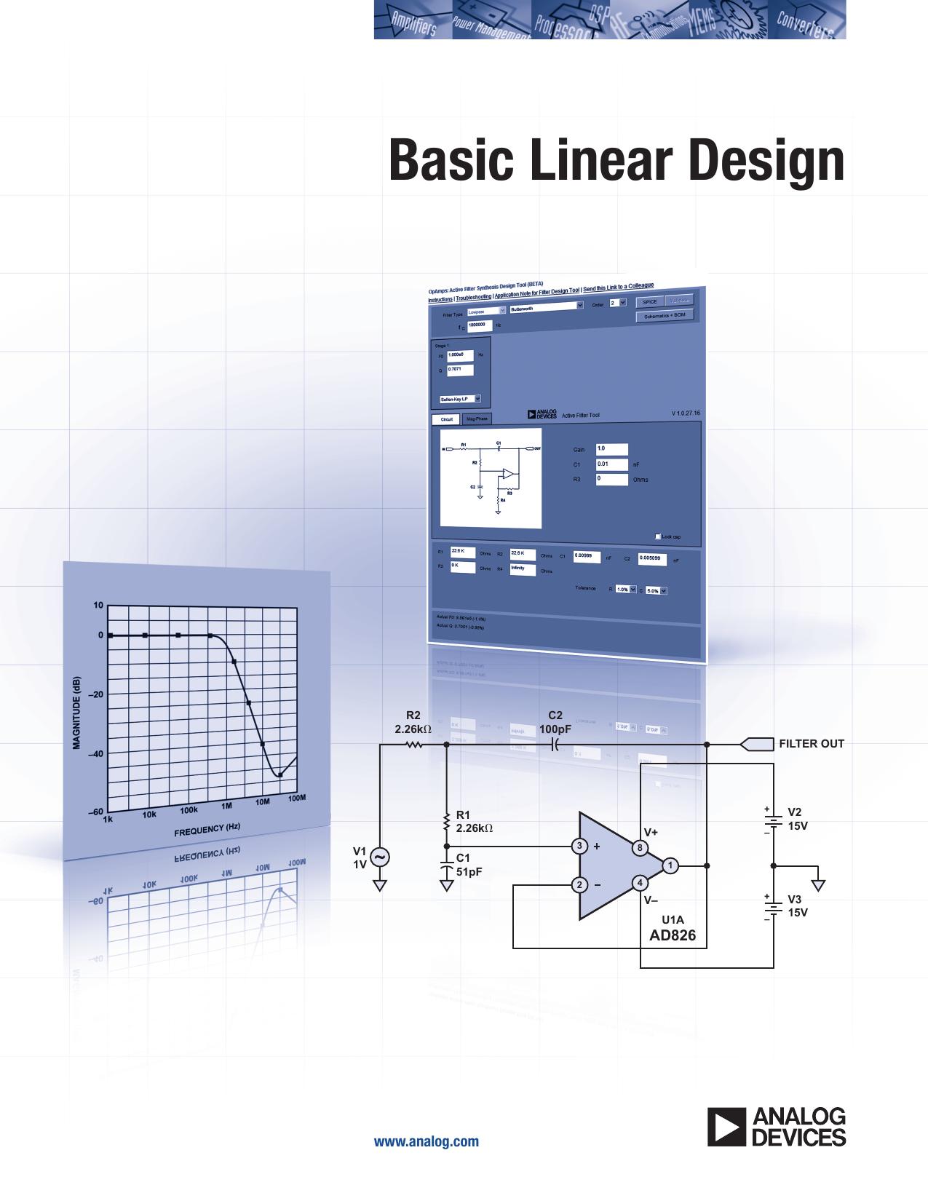
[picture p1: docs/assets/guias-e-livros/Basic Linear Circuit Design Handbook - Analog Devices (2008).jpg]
|  | [Basic Linear Circuit Design Handbook](https://github.com/RapportTecnologia/kit-de-prototipacao-educacional-e-engenharia/blob/main/Guias%20e%20Livros/Basic%20Linear%20Circuit%20Design%20Handbook%20-%20Ana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) | Analog Devices (2008) | pt | 2021-07-22 | pcb | [PDF](https://github.com/RapportTecnologia/kit-de-prototipacao-educacional-e-engenharia/blob/main/Guias%20e%20Livros/Basic%20Linear%20Circuit%20Design%20Handbook%20-%20Ana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) |
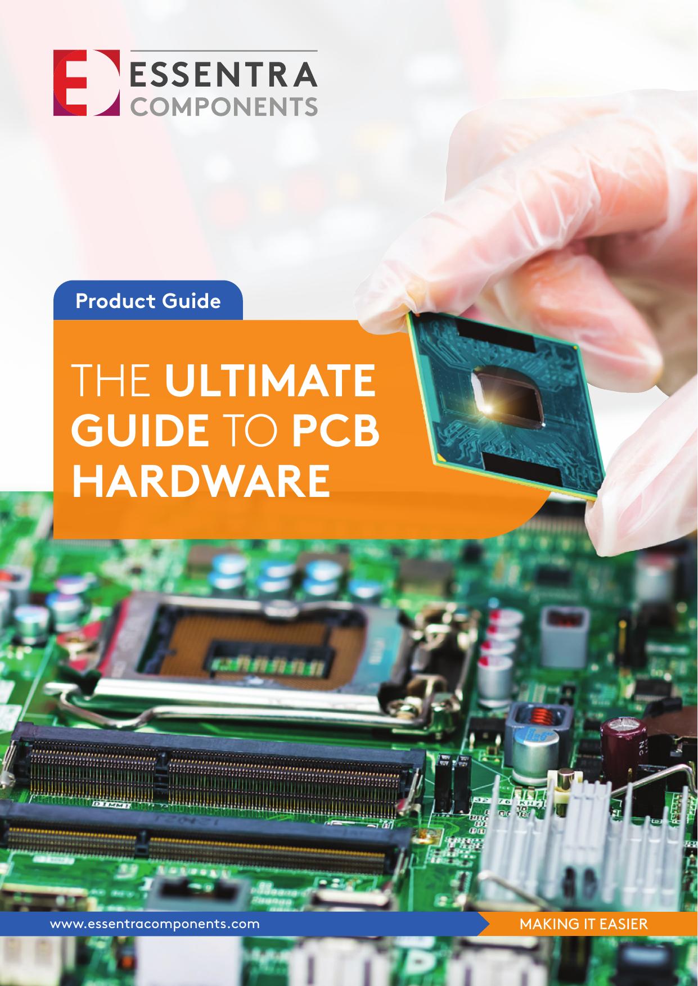
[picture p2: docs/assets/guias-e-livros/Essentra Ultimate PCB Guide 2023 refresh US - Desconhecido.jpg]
|  | [Essentra Ultimate PCB Guide 2023 refresh US](https://github.com/RapportTecnologia/kit-de-prototipacao-educacional-e-engenharia/blob/main/Guias%20e%20Livros/Essentra%20Ultimate%20PCB%20Guide%202023%20refresh%20U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) | Desconhecido | pt | 2020-03-11 | pcb | [PDF](https://github.com/RapportTecnologia/kit-de-prototipacao-educacional-e-engenharia/blob/main/Guias%20e%20Livros/Essentra%20Ultimate%20PCB%20Guide%202023%20refresh%20U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) |
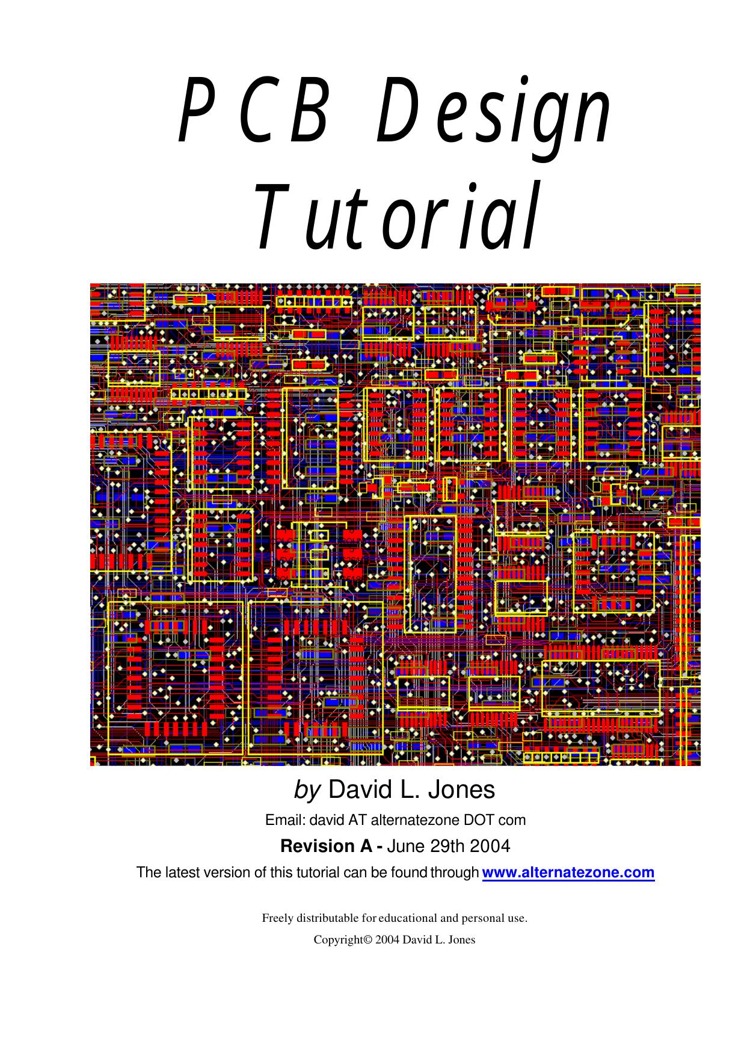
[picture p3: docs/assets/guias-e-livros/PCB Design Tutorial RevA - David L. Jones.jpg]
|  | [PCB Design Tutorial RevA](https://github.com/RapportTecnologia/kit-de-prototipacao-educacional-e-engenharia/blob/main/Guias%20e%20Livros/PCB%20Design%20Tutorial%20RevA%20-%20David%20L.%20Jone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) | David L. Jones | pt |  | pcb | [PDF](https://github.com/RapportTecnologia/kit-de-prototipacao-educacional-e-engenharia/blob/main/Guias%20e%20Livros/PCB%20Design%20Tutorial%20RevA%20-%20David%20L.%20Jone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) |

## IPC

| Capa | Título | Autor | Idioma | Data | Assunto | Arquivo |
| --- | --- | --- | --- | --- | --- | --- |
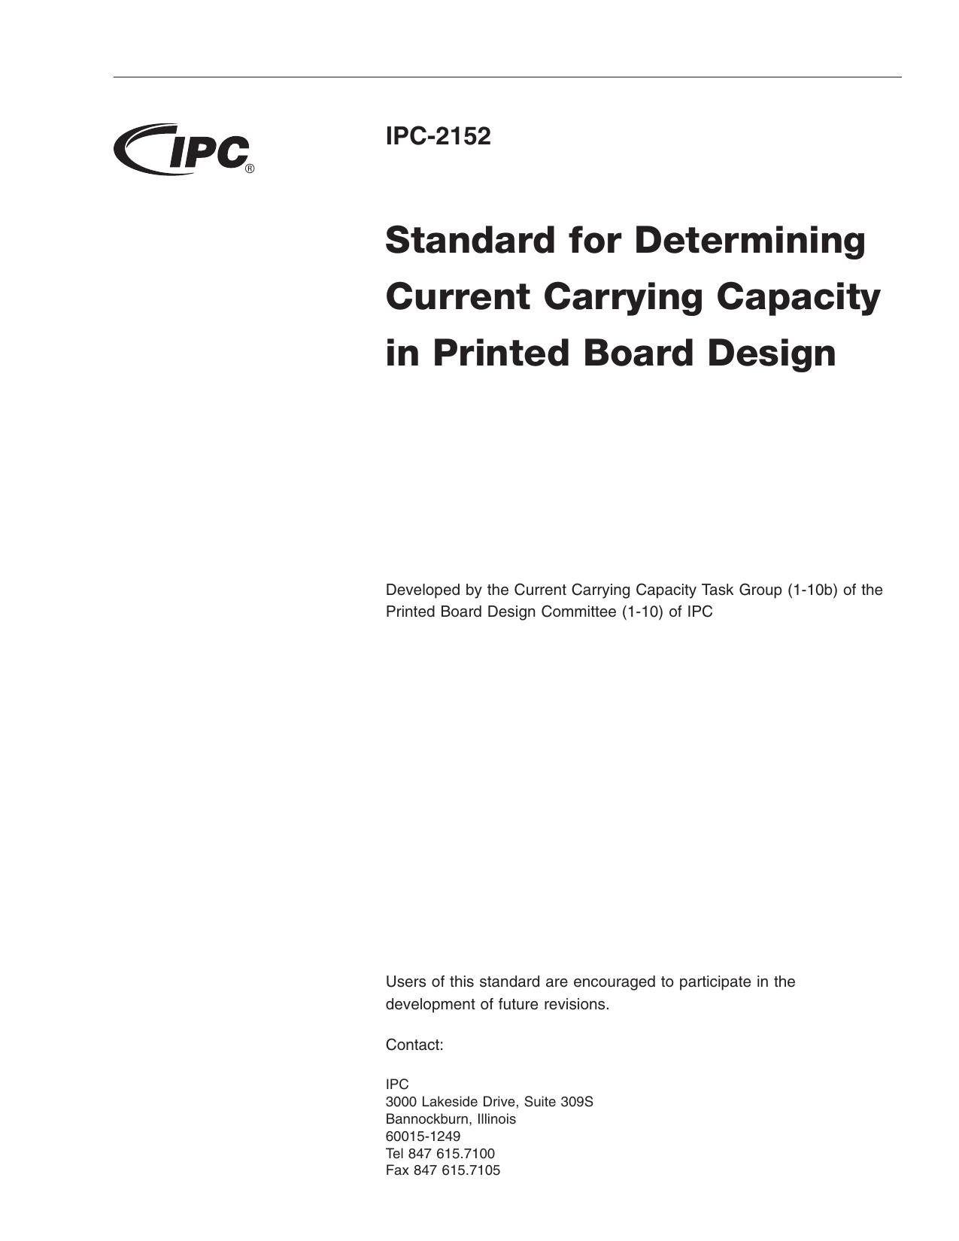
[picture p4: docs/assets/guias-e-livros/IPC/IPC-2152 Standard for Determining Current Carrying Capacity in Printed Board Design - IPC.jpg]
capa
|  | [IPC-2152 Standard for Determining Current Carrying Capacity in Printed Board Design](https://github.com/RapportTecnologia/kit-de-prototipacao-educacional-e-engenharia/blob/main/Guias%20e%20Livros/IPC/IPC-2152%20Standard%20for%20Determining%20Current%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) | IPC | pt | 2009-08-19 | CURRENT CARRYING CAPACITY | [PDF](https://github.com/RapportTecnologia/kit-de-prototipacao-educacional-e-engenharia/blob/main/Guias%20e%20Livros/IPC/IPC-2152%20Standard%20for%20Determining%20Current%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) |
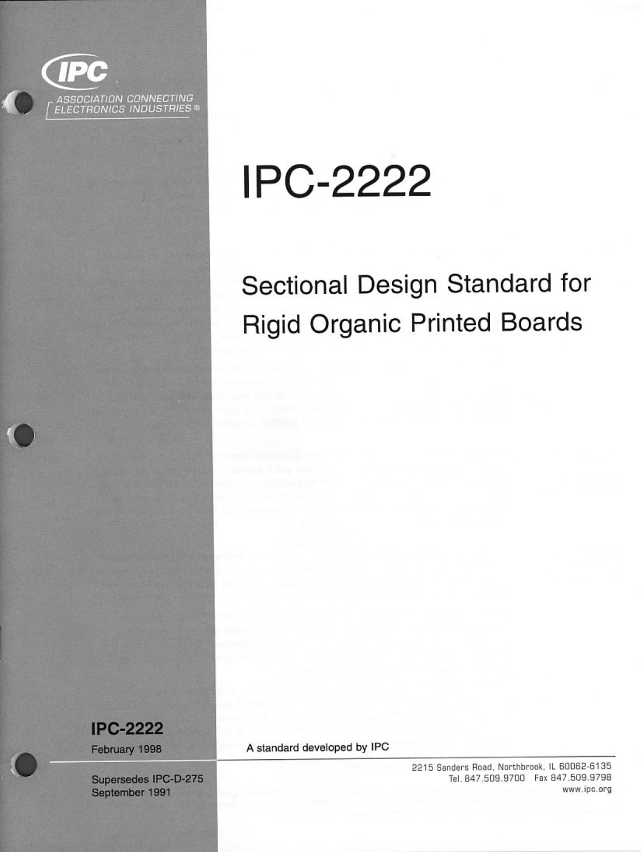
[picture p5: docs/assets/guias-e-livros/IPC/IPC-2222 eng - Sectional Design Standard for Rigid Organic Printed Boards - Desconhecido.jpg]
|  | [IPC-2222 eng - Sectional Design Standard for Rigid Organic Printed Boards](https://github.com/RapportTecnologia/kit-de-prototipacao-educacional-e-engenharia/blob/main/Guias%20e%20Livros/IPC/IPC-2222%20eng%20-%20Sectional%20Design%20Standard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) | Desconhecido | pt | 2011-09-10 | PCI | [PDF](https://github.com/RapportTecnologia/kit-de-prototipacao-educacional-e-engenharia/blob/main/Guias%20e%20Livros/IPC/IPC-2222%20eng%20-%20Sectional%20Design%20Standard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) |
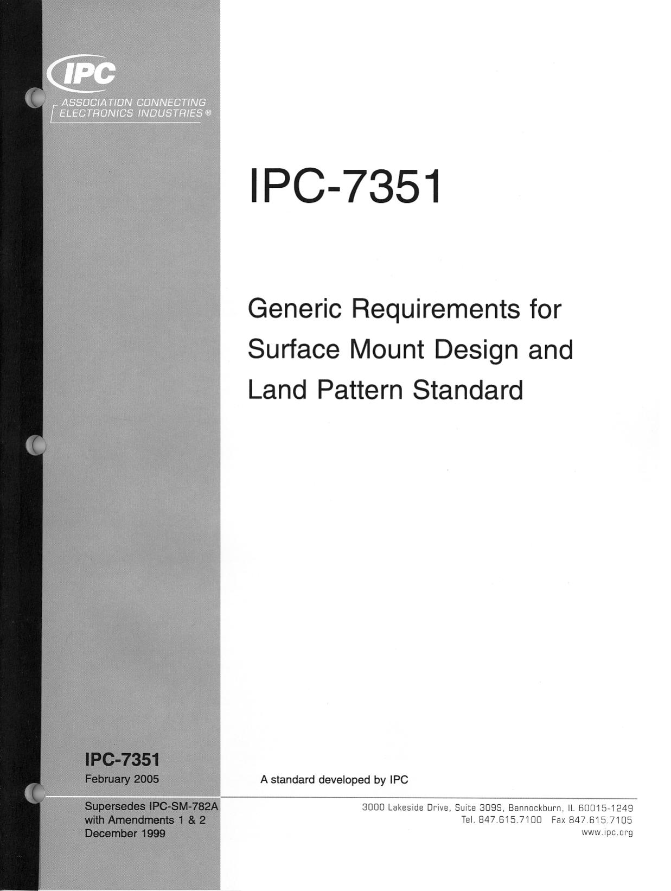
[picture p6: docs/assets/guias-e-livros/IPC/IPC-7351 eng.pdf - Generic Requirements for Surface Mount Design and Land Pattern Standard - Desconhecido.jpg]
|  | [IPC-7351 eng.pdf - Generic Requirements for Surface Mount Design and Land Pattern Standard](https://github.com/RapportTecnologia/kit-de-prototipacao-educacional-e-engenharia/blob/main/Guias%20e%20Livros/IPC/IPC-7351%20eng.pdf%20-%20Generic%20Requirements%20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) | Desconhecido | pt | 2011-09-10 | PCI | [PDF](https://github.com/RapportTecnologia/kit-de-prototipacao-educacional-e-engenharia/blob/main/Guias%20e%20Livros/IPC/IPC-7351%20eng.pdf%20-%20Generic%20Requirements%20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) |
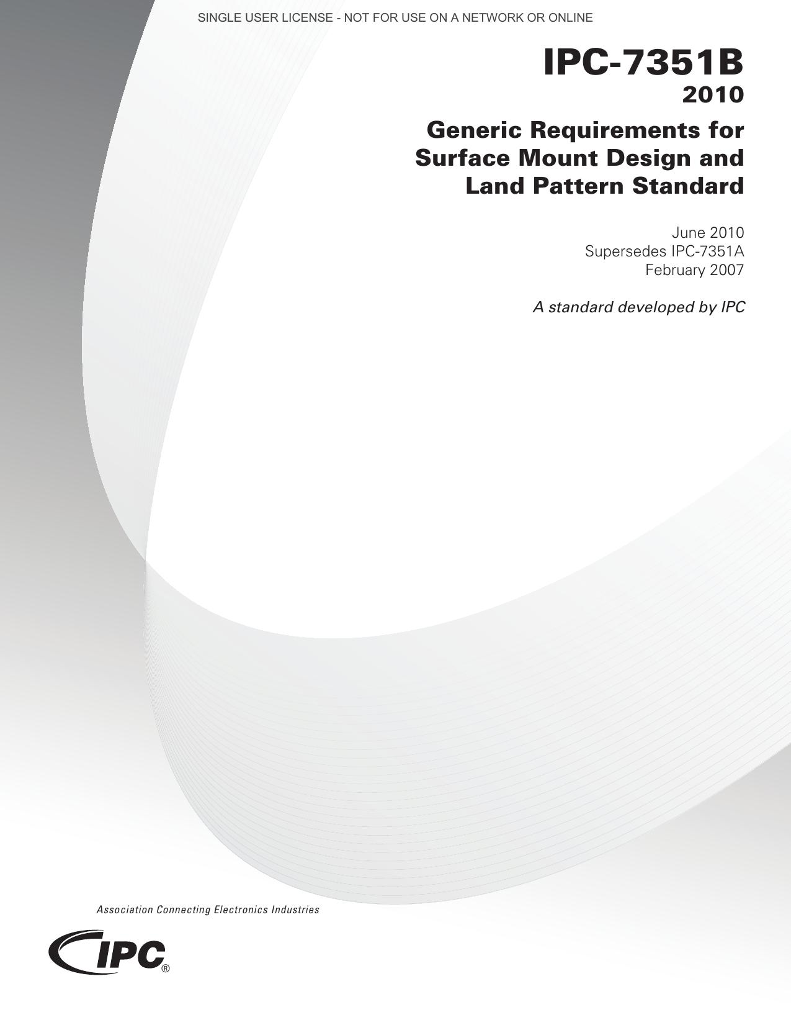
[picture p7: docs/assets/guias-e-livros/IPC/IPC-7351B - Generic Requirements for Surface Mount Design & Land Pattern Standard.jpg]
|  | [IPC-7351B](https://github.com/RapportTecnologia/kit-de-prototipacao-educacional-e-engenharia/blob/main/Guias%20e%20Livros/IPC/IPC-7351B%20-%20Generic%20Requirements%20for%20Sur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) | Generic Requirements for Surface Mount Design, Land Pattern Standard | pt | 2010-06-17 |  | [PDF](https://github.com/RapportTecnologia/kit-de-prototipacao-educacional-e-engenharia/blob/main/Guias%20e%20Livros/IPC/IPC-7351B%20-%20Generic%20Requirements%20for%20Sur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) |
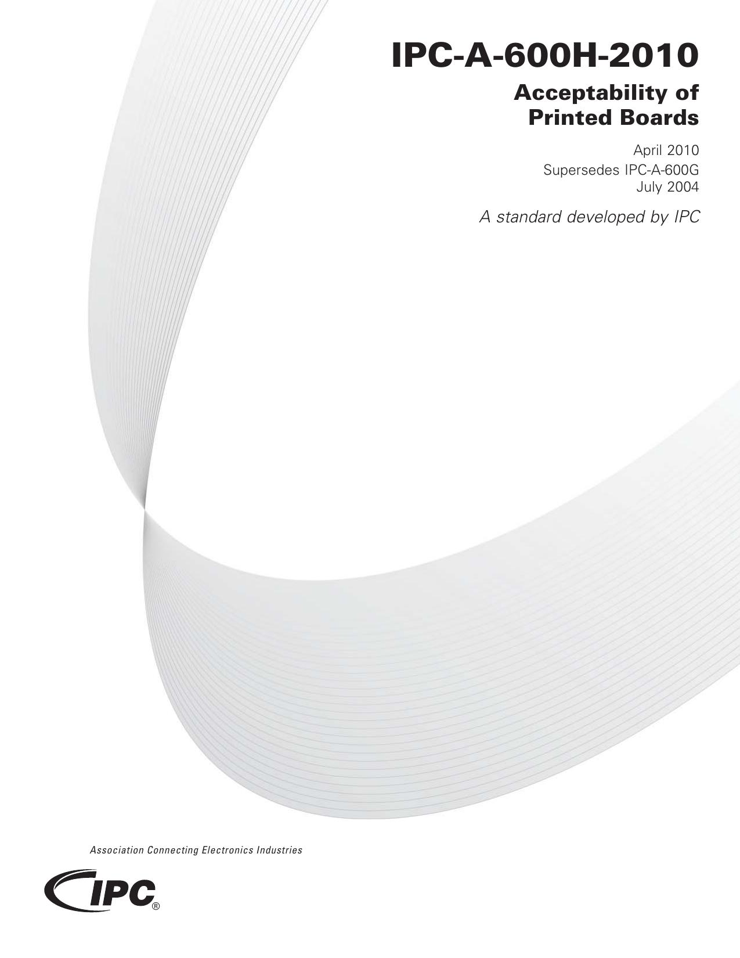
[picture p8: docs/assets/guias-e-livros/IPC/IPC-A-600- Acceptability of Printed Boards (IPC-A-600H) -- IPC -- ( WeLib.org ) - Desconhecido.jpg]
|  | [IPC-A-600- Acceptability of Printed Boards (IPC-A-600H) -- IPC -- ( WeLib.org )](https://github.com/RapportTecnologia/kit-de-prototipacao-educacional-e-engenharia/blob/main/Guias%20e%20Livros/IPC/IPC-A-600-%20Acceptability%20of%20Printed%20Boards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) | Desconhecido | pt |  | PCI | [PDF](https://github.com/RapportTecnologia/kit-de-prototipacao-educacional-e-engenharia/blob/main/Guias%20e%20Livros/IPC/IPC-A-600-%20Acceptability%20of%20Printed%20Boards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) |
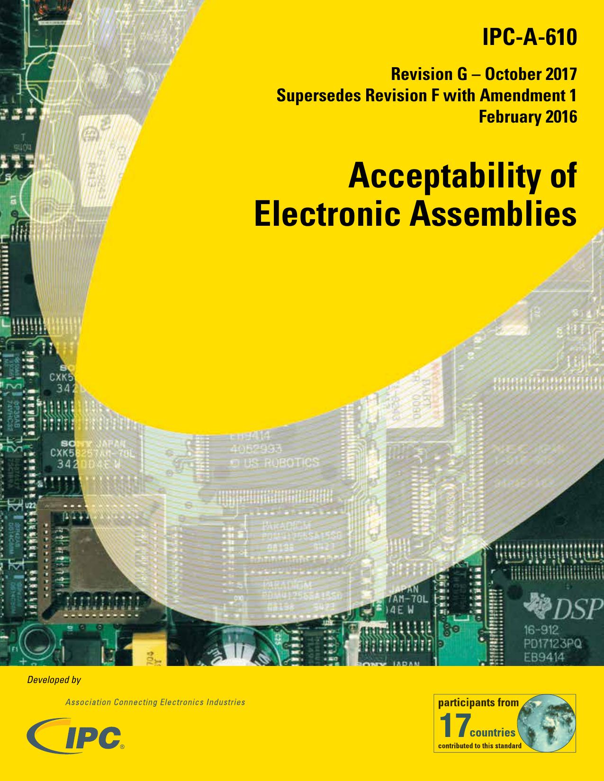
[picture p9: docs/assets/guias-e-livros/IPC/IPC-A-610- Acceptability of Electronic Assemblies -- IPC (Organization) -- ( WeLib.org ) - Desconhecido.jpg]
|  | [IPC-A-610- Acceptability of Electronic Assemblies -- IPC (Organization) -- ( WeLib.org )](https://github.com/RapportTecnologia/kit-de-prototipacao-educacional-e-engenharia/blob/main/Guias%20e%20Livros/IPC/IPC-A-610-%20Acceptability%20of%20Electronic%20Ass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) | Desconhecido | pt |  | PCI | [PDF](https://github.com/RapportTecnologia/kit-de-prototipacao-educacional-e-engenharia/blob/main/Guias%20e%20Livros/IPC/IPC-A-610-%20Acceptability%20of%20Electronic%20Ass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) |

## KiCAD

| Capa | Título | Autor | Idioma | Data | Assunto | Arquivo |
| --- | --- | --- | --- | --- | --- | --- |
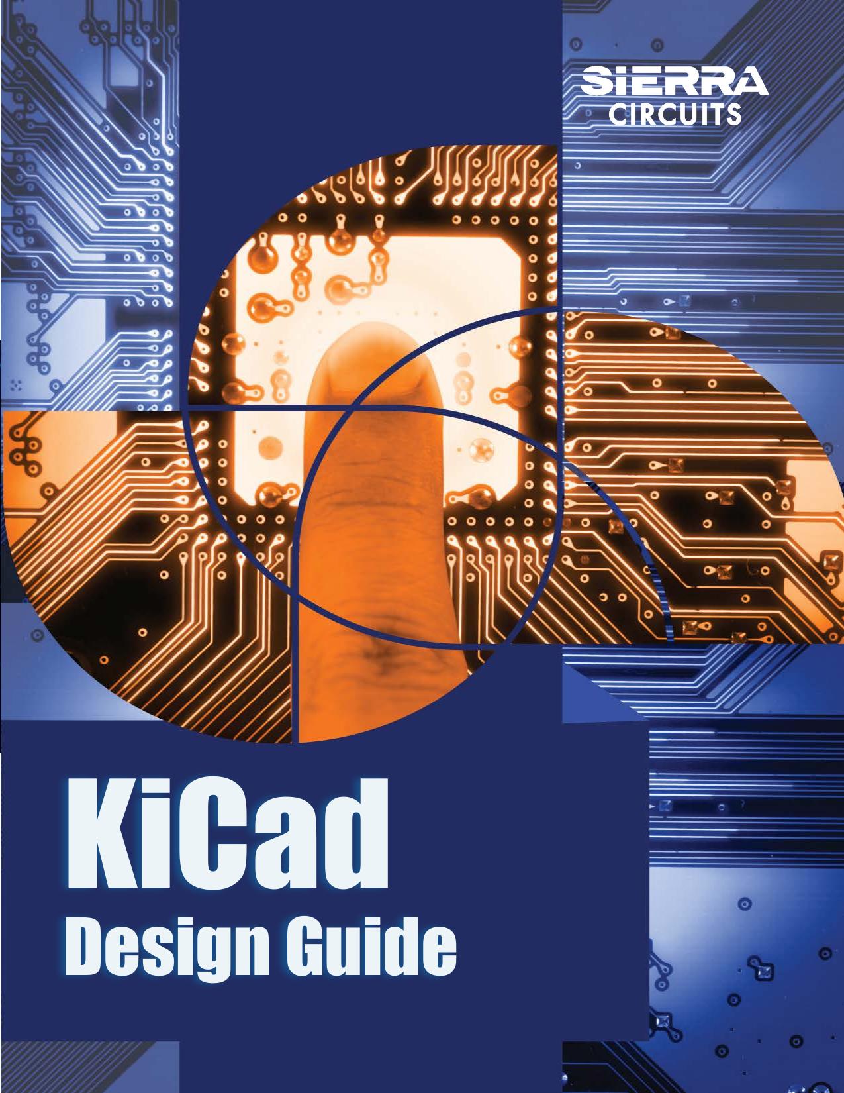
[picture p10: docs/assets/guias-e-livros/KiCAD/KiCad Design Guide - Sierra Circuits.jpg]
|  | [KiCad Design Guide](https://github.com/RapportTecnologia/kit-de-prototipacao-educacional-e-engenharia/blob/main/Guias%20e%20Livros/KiCAD/KiCad%20Design%20Guide%20-%20Sierra%20Circuits.p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) | Sierra Circuits | pt | 2024-09-11 | pcb | [PDF](https://github.com/RapportTecnologia/kit-de-prototipacao-educacional-e-engenharia/blob/main/Guias%20e%20Livros/KiCAD/KiCad%20Design%20Guide%20-%20Sierra%20Circuits.p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) |
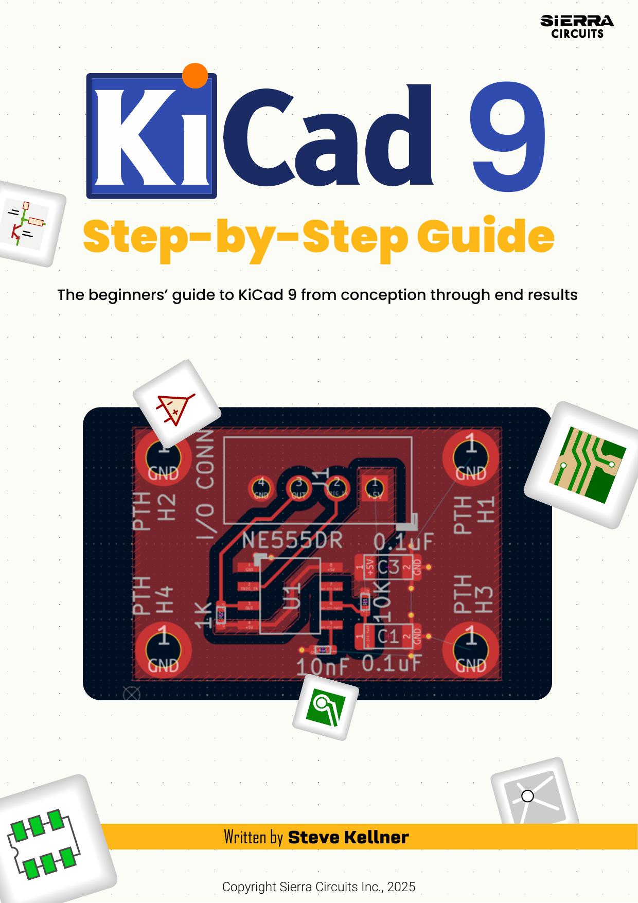
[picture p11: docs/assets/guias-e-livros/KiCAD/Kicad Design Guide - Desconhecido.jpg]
|  | [Kicad Design Guide](https://github.com/RapportTecnologia/kit-de-prototipacao-educacional-e-engenharia/blob/main/Guias%20e%20Livros/KiCAD/Kicad%20Design%20Guide%20-%20Desconhecido.pdf) | Desconhecido | pt | 2025-07-04 | pcb | [PDF](https://github.com/RapportTecnologia/kit-de-prototipacao-educacional-e-engenharia/blob/main/Guias%20e%20Livros/KiCAD/Kicad%20Design%20Guide%20-%20Desconhecido.pdf) |

## Sierra Circuits

| Capa | Título | Autor | Idioma | Data | Assunto | Arquivo |
| --- | --- | --- | --- | --- | --- | --- |
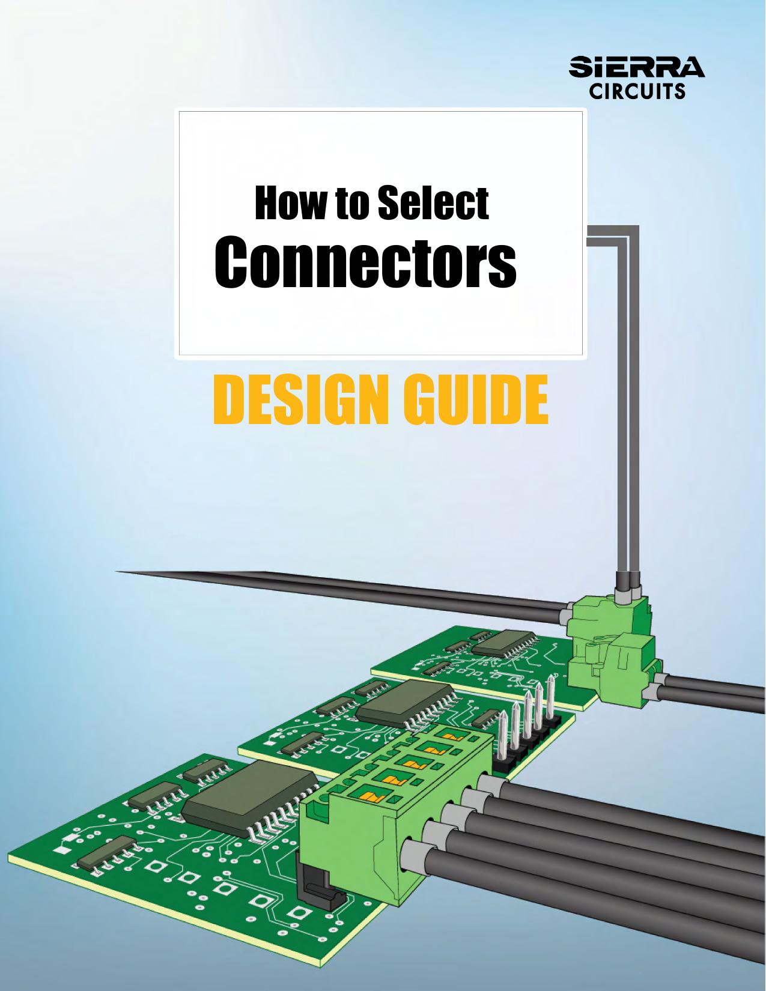
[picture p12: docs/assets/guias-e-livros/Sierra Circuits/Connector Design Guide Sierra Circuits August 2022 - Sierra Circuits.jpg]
|  | [Connector Design Guide Sierra Circuits August 2022](https://github.com/RapportTecnologia/kit-de-prototipacao-educacional-e-engenharia/blob/main/Guias%20e%20Livros/Sierra%20Circuits/Connector%20Design%20Guide%20Sierra%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) | Sierra Circuits | pt | 2021-08-26 | PCB | [PDF](https://github.com/RapportTecnologia/kit-de-prototipacao-educacional-e-engenharia/blob/main/Guias%20e%20Livros/Sierra%20Circuits/Connector%20Design%20Guide%20Sierra%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) |
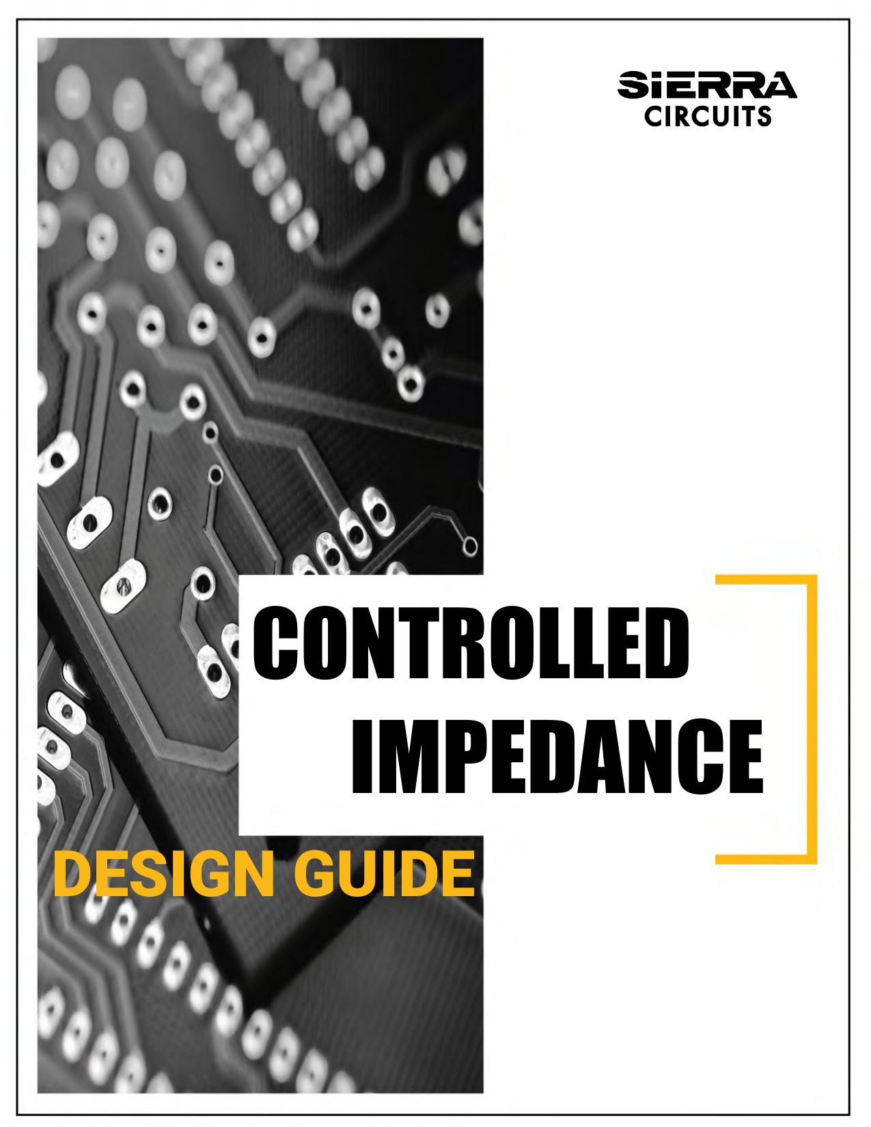
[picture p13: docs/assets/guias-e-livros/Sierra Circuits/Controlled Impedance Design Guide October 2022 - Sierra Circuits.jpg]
|  | [Controlled Impedance Design Guide October 2022](https://github.com/RapportTecnologia/kit-de-prototipacao-educacional-e-engenharia/blob/main/Guias%20e%20Livros/Sierra%20Circuits/Controlled%20Impedance%20Design%20Gu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) | Sierra Circuits | pt | 2021-04-01 | PCB | [PDF](https://github.com/RapportTecnologia/kit-de-prototipacao-educacional-e-engenharia/blob/main/Guias%20e%20Livros/Sierra%20Circuits/Controlled%20Impedance%20Design%20Gu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) |
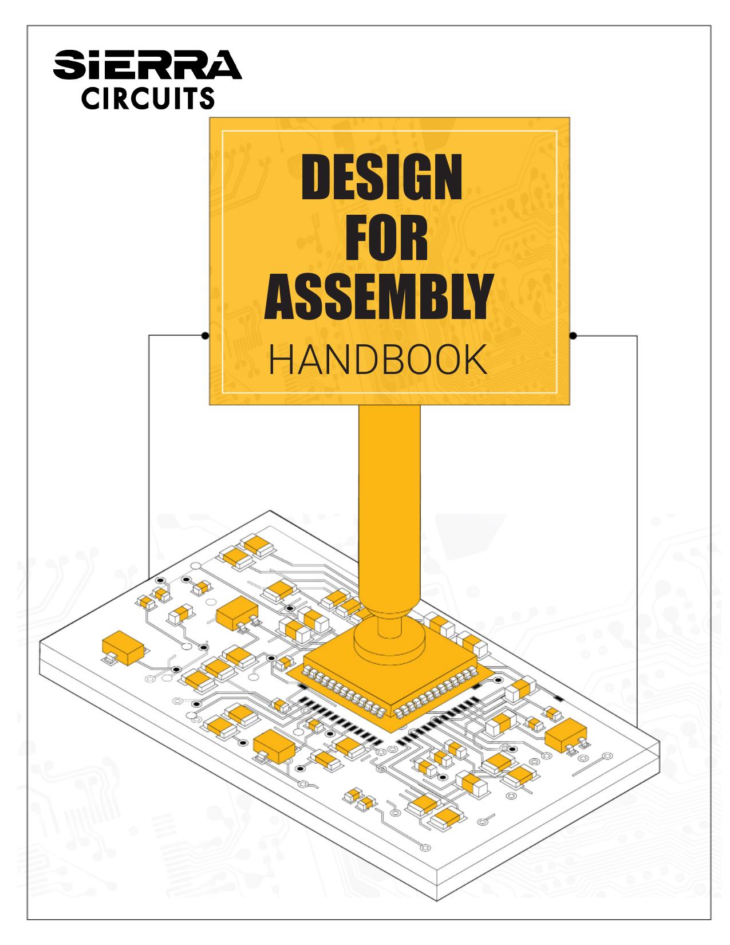
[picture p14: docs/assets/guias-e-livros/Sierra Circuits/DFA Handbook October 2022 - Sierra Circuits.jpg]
|  | [DFA Handbook October 2022](https://github.com/RapportTecnologia/kit-de-prototipacao-educacional-e-engenharia/blob/main/Guias%20e%20Livros/Sierra%20Circuits/DFA%20Handbook%20October%202022%20-%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) | Sierra Circuits | pt | 2022-09-08 | PCB | [PDF](https://github.com/RapportTecnologia/kit-de-prototipacao-educacional-e-engenharia/blob/main/Guias%20e%20Livros/Sierra%20Circuits/DFA%20Handbook%20October%202022%20-%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) |
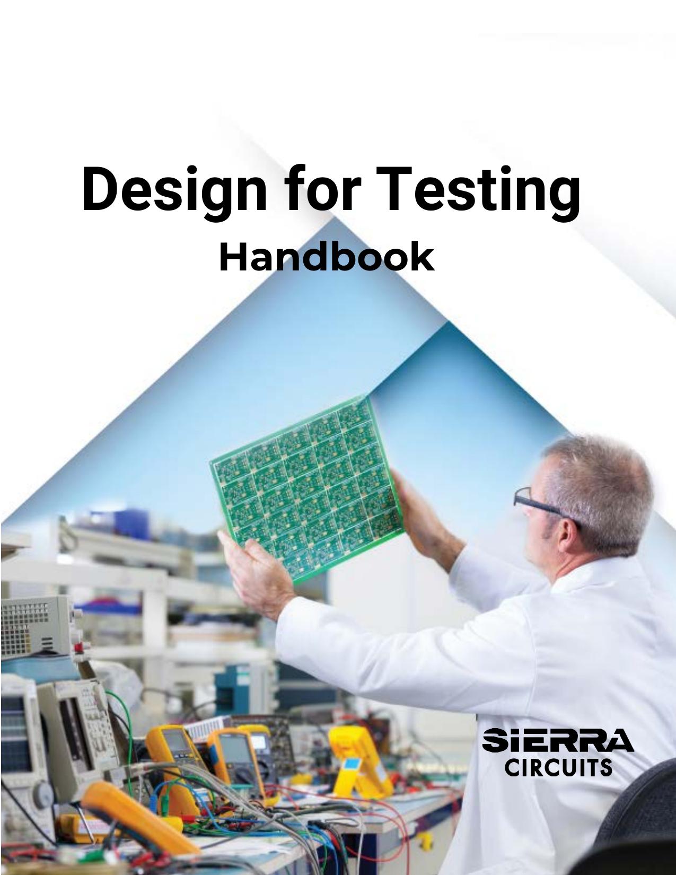
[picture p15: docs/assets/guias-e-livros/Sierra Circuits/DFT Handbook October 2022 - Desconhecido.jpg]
|  | [DFT Handbook October 2022](https://github.com/RapportTecnologia/kit-de-prototipacao-educacional-e-engenharia/blob/main/Guias%20e%20Livros/Sierra%20Circuits/DFT%20Handbook%20October%202022%20-%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) | Desconhecido | pt | 2022-12-30 | pcb | [PDF](https://github.com/RapportTecnologia/kit-de-prototipacao-educacional-e-engenharia/blob/main/Guias%20e%20Livros/Sierra%20Circuits/DFT%20Handbook%20October%202022%20-%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) |
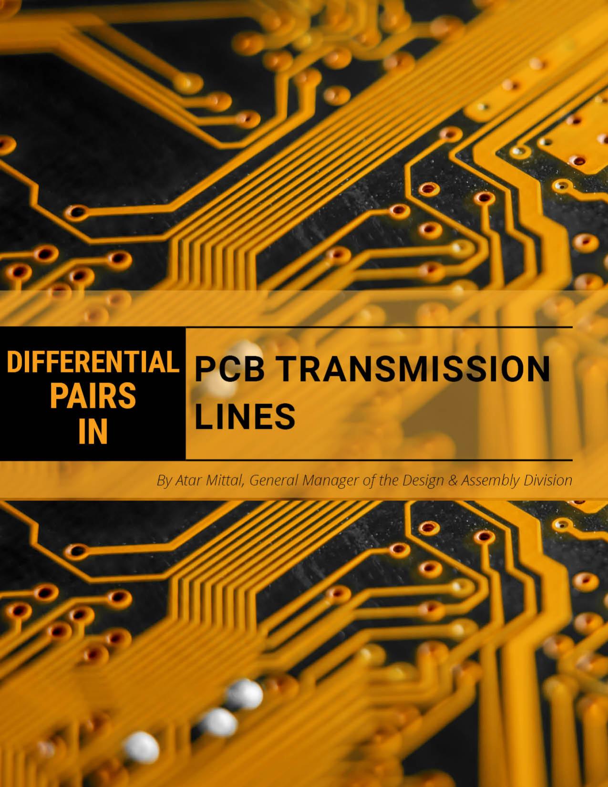
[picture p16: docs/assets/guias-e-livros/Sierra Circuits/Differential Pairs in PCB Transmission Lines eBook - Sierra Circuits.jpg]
|  | [Differential Pairs in PCB Transmission Lines eBook](https://github.com/RapportTecnologia/kit-de-prototipacao-educacional-e-engenharia/blob/main/Guias%20e%20Livros/Sierra%20Circuits/Differential%20Pairs%20in%20PCB%20Tr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) | Sierra Circuits | pt | 2019-11-13 | PCB | [PDF](https://github.com/RapportTecnologia/kit-de-prototipacao-educacional-e-engenharia/blob/main/Guias%20e%20Livros/Sierra%20Circuits/Differential%20Pairs%20in%20PCB%20Tr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) |
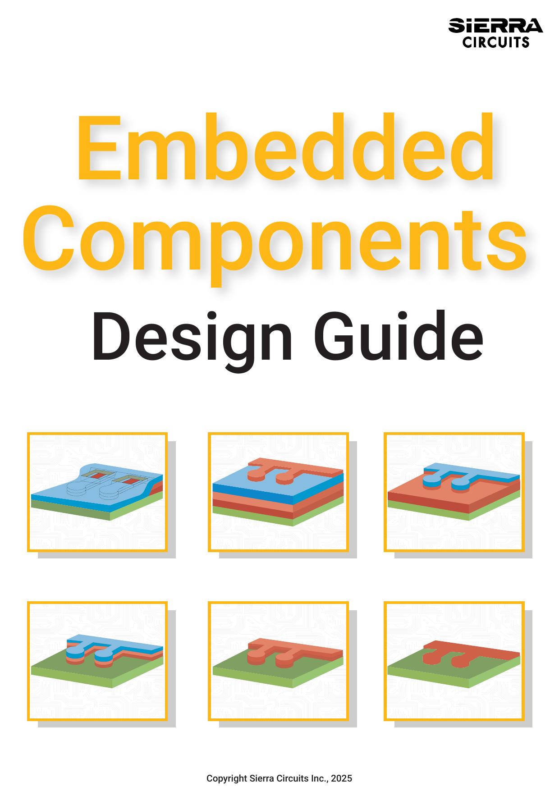
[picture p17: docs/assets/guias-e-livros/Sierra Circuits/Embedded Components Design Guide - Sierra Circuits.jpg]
|  | [Embedded Components Design Guide](https://github.com/RapportTecnologia/kit-de-prototipacao-educacional-e-engenharia/blob/main/Guias%20e%20Livros/Sierra%20Circuits/Embedded%20Components%20Design%20Gui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) | Sierra Circuits | pt | 2025-10-27 | PCB | [PDF](https://github.com/RapportTecnologia/kit-de-prototipacao-educacional-e-engenharia/blob/main/Guias%20e%20Livros/Sierra%20Circuits/Embedded%20Components%20Design%20Gui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) |
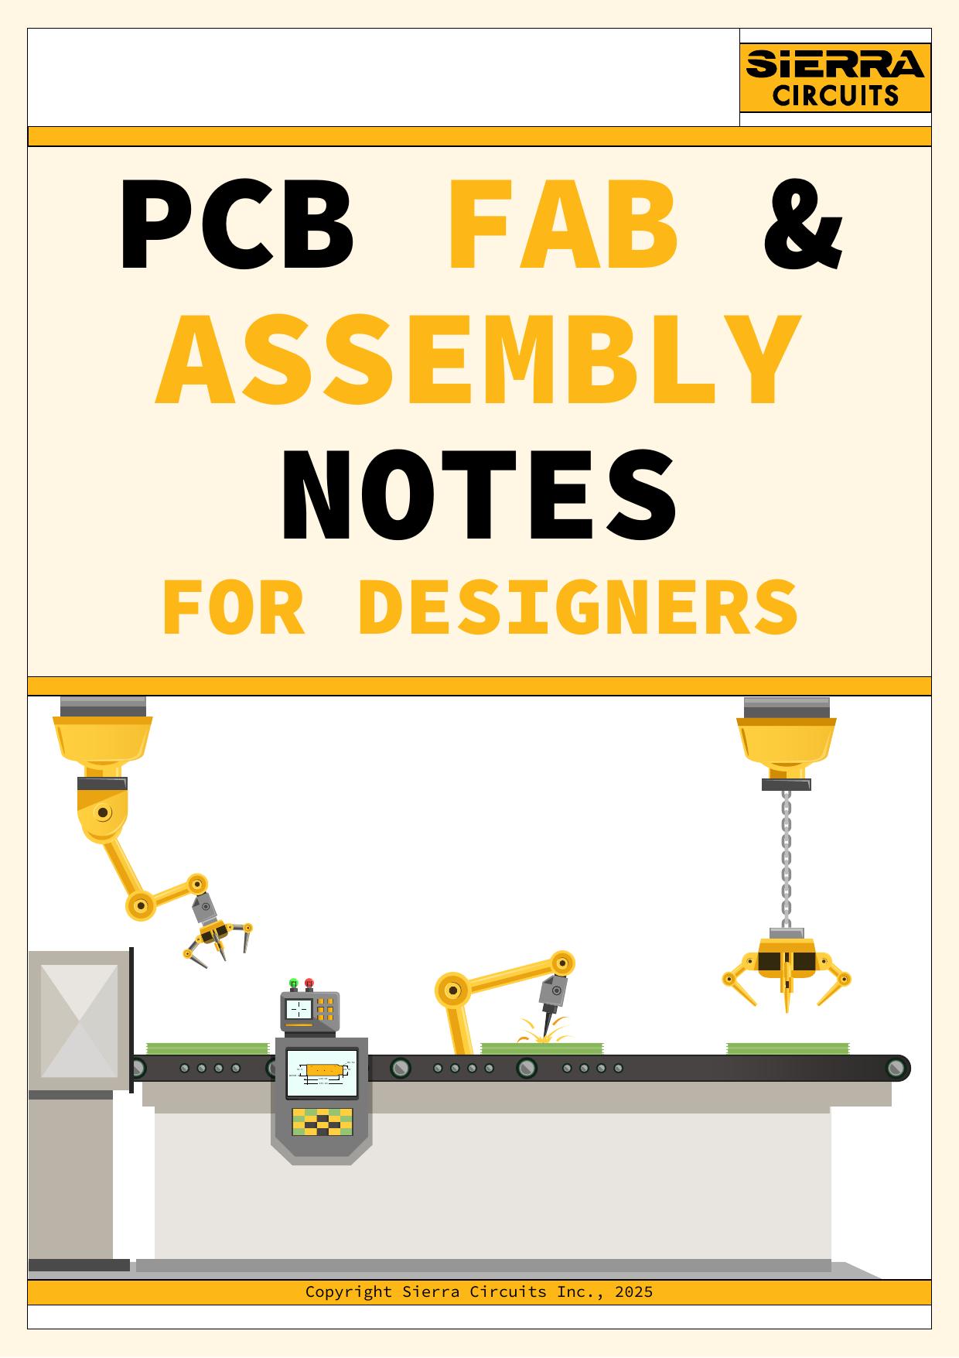
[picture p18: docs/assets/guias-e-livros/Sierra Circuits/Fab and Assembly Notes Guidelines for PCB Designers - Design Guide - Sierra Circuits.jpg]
|  | [Fab and Assembly Notes Guidelines for PCB Designers - Design Guide](https://github.com/RapportTecnologia/kit-de-prototipacao-educacional-e-engenharia/blob/main/Guias%20e%20Livros/Sierra%20Circuits/Fab%20and%20Assembly%20Notes%20Guide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) | Sierra Circuits | pt | 2025-08-13 | PCB | [PDF](https://github.com/RapportTecnologia/kit-de-prototipacao-educacional-e-engenharia/blob/main/Guias%20e%20Livros/Sierra%20Circuits/Fab%20and%20Assembly%20Notes%20Guide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) |
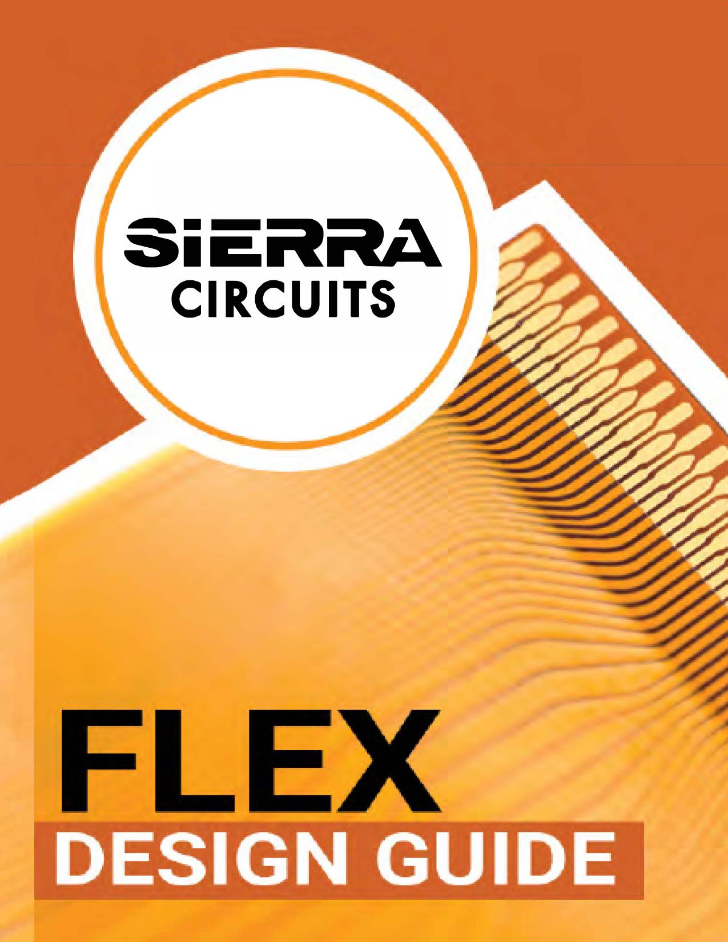
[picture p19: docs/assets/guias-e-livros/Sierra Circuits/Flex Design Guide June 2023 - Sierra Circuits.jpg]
|  | [Flex Design Guide June 2023](https://github.com/RapportTecnologia/kit-de-prototipacao-educacional-e-engenharia/blob/main/Guias%20e%20Livros/Sierra%20Circuits/Flex%20Design%20Guide%20June%202023%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) | Sierra Circuits | pt | 2021-06-25 | PCB | [PDF](https://github.com/RapportTecnologia/kit-de-prototipacao-educacional-e-engenharia/blob/main/Guias%20e%20Livros/Sierra%20Circuits/Flex%20Design%20Guide%20June%202023%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) |
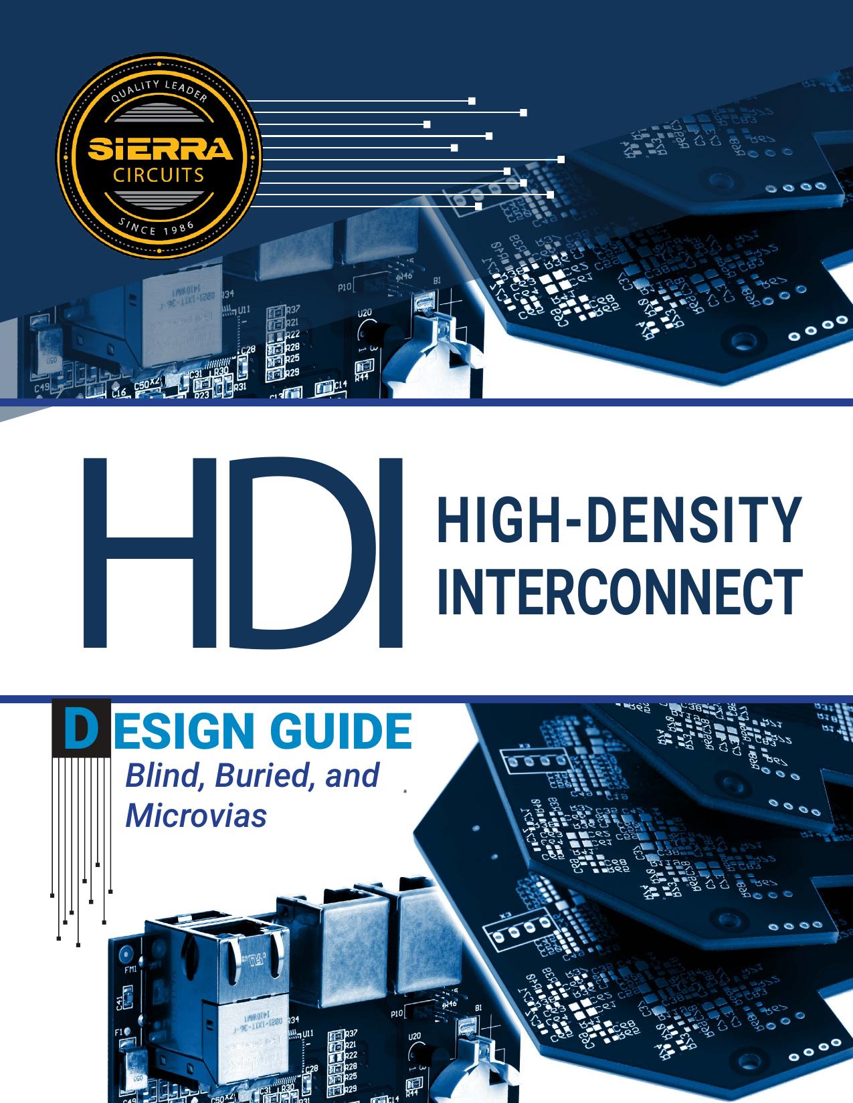
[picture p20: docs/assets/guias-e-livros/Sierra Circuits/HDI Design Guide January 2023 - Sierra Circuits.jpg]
|  | [HDI Design Guide January 2023](https://github.com/RapportTecnologia/kit-de-prototipacao-educacional-e-engenharia/blob/main/Guias%20e%20Livros/Sierra%20Circuits/HDI%20Design%20Guide%20January%20202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) | Sierra Circuits | pt | 2022-11-21 | PCB | [PDF](https://github.com/RapportTecnologia/kit-de-prototipacao-educacional-e-engenharia/blob/main/Guias%20e%20Livros/Sierra%20Circuits/HDI%20Design%20Guide%20January%20202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) |
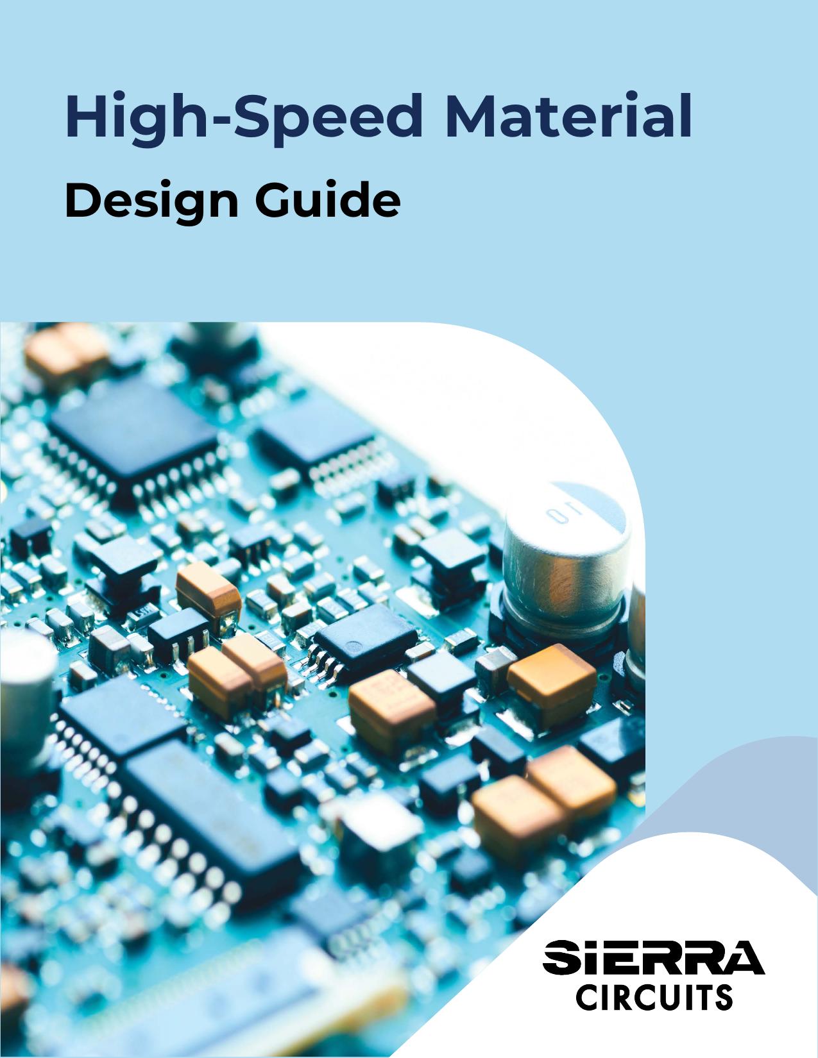
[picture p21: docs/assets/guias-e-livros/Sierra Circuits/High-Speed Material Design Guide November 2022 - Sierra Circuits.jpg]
|  | [High-Speed Material Design Guide November 2022](https://github.com/RapportTecnologia/kit-de-prototipacao-educacional-e-engenharia/blob/main/Guias%20e%20Livros/Sierra%20Circuits/High-Speed%20Material%20Design%20Gui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) | Sierra Circuits | pt | 2022-11-01 | PCB | [PDF](https://github.com/RapportTecnologia/kit-de-prototipacao-educacional-e-engenharia/blob/main/Guias%20e%20Livros/Sierra%20Circuits/High-Speed%20Material%20Design%20Gui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) |
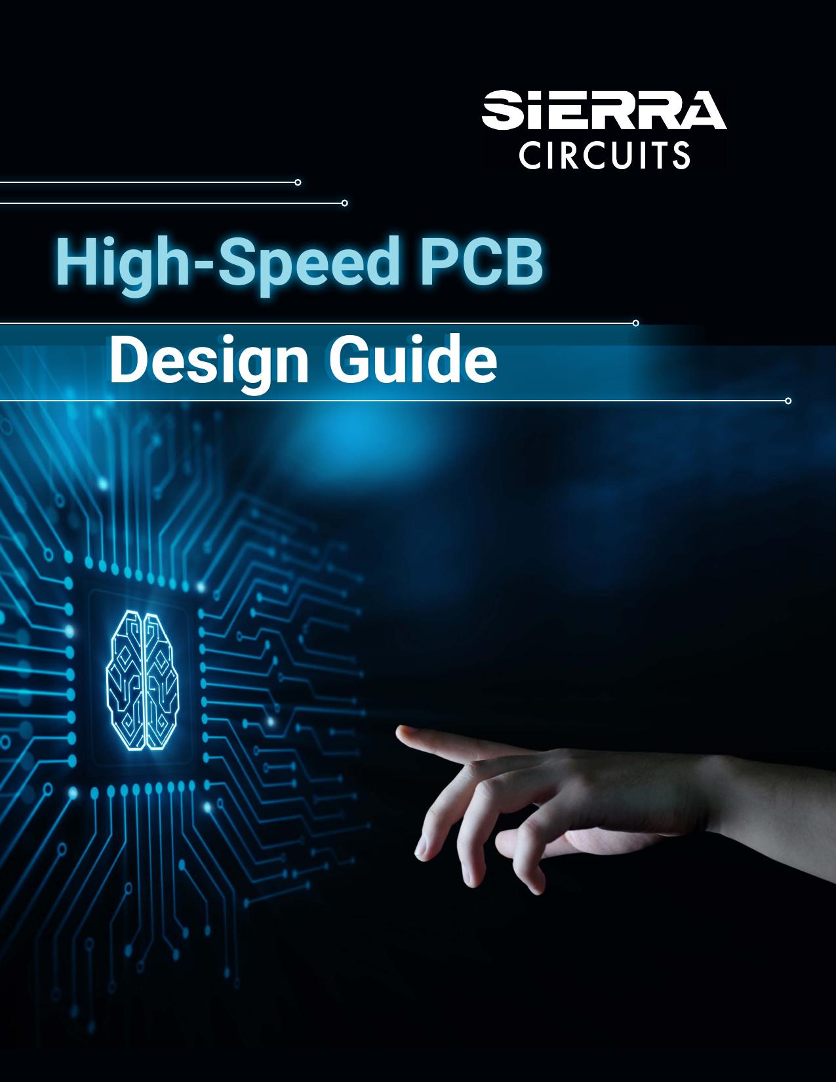
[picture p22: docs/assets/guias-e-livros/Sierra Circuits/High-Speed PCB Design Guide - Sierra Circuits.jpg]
|  | [High-Speed PCB Design Guide](https://github.com/RapportTecnologia/kit-de-prototipacao-educacional-e-engenharia/blob/main/Guias%20e%20Livros/Sierra%20Circuits/High-Speed%20PCB%20Design%20Guide%20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) | Sierra Circuits | pt | 2020-11-03 |  | [PDF](https://github.com/RapportTecnologia/kit-de-prototipacao-educacional-e-engenharia/blob/main/Guias%20e%20Livros/Sierra%20Circuits/High-Speed%20PCB%20Design%20Guide%20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) |
| capa | [High-Speed PCB Design Guide January 2023](https://github.com/RapportTecnologia/kit-de-prototipacao-educacional-e-engenharia/blob/main/Guias%20e%20Livros/Sierra%20Circuits/High-Speed%20PCB%20Design%20Guide%20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) | Sierra Circuits | pt | 2020-11-03 | PCB | [PDF](https://github.com/RapportTecnologia/kit-de-prototipacao-educacional-e-engenharia/blob/main/Guias%20e%20Livros/Sierra%20Circuits/High-Speed%20PCB%20Design%20Guide%20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) |
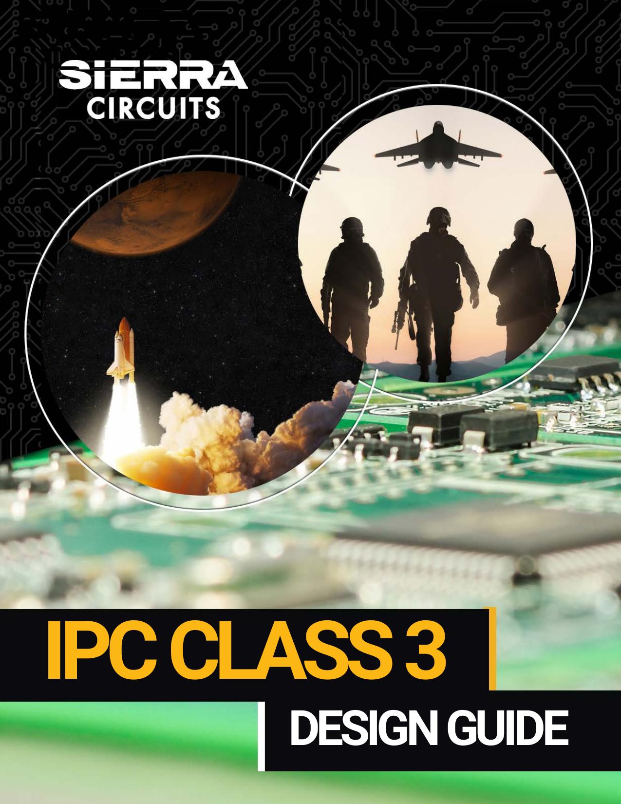
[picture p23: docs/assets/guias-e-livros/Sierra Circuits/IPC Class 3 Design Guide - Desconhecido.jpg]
|  | [IPC Class 3 Design Guide](https://github.com/RapportTecnologia/kit-de-prototipacao-educacional-e-engenharia/blob/main/Guias%20e%20Livros/Sierra%20Circuits/IPC%20Class%203%20Design%20Guide%20-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) | Desconhecido | pt | 2020-07-15 | pcb | [PDF](https://github.com/RapportTecnologia/kit-de-prototipacao-educacional-e-engenharia/blob/main/Guias%20e%20Livros/Sierra%20Circuits/IPC%20Class%203%20Design%20Guide%20-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) |
| capa | [IPC Class 3 Design Guide](https://github.com/RapportTecnologia/kit-de-prototipacao-educacional-e-engenharia/blob/main/Guias%20e%20Livros/Sierra%20Circuits/IPC%20Class%203%20Design%20Guide%20-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) | Sierra Circuits | pt | 2020-07-15 | PCB | [PDF](https://github.com/RapportTecnologia/kit-de-prototipacao-educacional-e-engenharia/blob/main/Guias%20e%20Livros/Sierra%20Circuits/IPC%20Class%203%20Design%20Guide%20-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) |
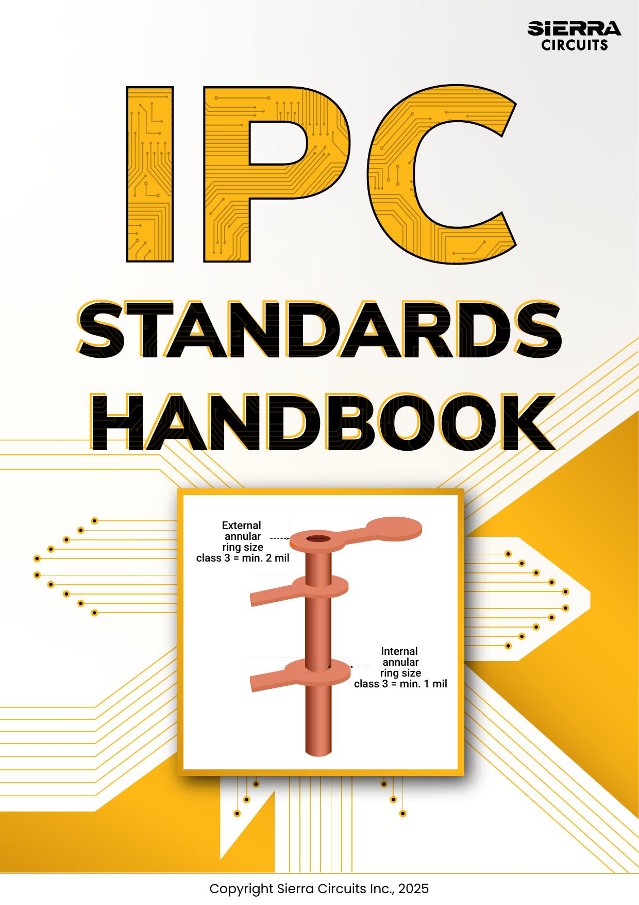
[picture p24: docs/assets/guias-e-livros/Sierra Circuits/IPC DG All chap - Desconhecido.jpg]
|  | [IPC DG All chap](https://github.com/RapportTecnologia/kit-de-prototipacao-educacional-e-engenharia/blob/main/Guias%20e%20Livros/Sierra%20Circuits/IPC%20DG%20All%20chap%20-%20Desconhe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) | Desconhecido | pt | 2025-07-25 | pcb | [PDF](https://github.com/RapportTecnologia/kit-de-prototipacao-educacional-e-engenharia/blob/main/Guias%20e%20Livros/Sierra%20Circuits/IPC%20DG%20All%20chap%20-%20Desconhe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) |
| capa | [IPC DG All chap](https://github.com/RapportTecnologia/kit-de-prototipacao-educacional-e-engenharia/blob/main/Guias%20e%20Livros/Sierra%20Circuits/IPC%20DG%20All%20chap%20-%20Sierra%2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) | Sierra Circuits | pt | 2025-07-25 | PCB | [PDF](https://github.com/RapportTecnologia/kit-de-prototipacao-educacional-e-engenharia/blob/main/Guias%20e%20Livros/Sierra%20Circuits/IPC%20DG%20All%20chap%20-%20Sierra%2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) |
| capa | [KiCad Design Guide](https://github.com/RapportTecnologia/kit-de-prototipacao-educacional-e-engenharia/blob/main/Guias%20e%20Livros/Sierra%20Circuits/KiCad%20Design%20Guide%20-%20Sierra%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) | Sierra Circuits | pt | 2024-09-11 | PCB | [PDF](https://github.com/RapportTecnologia/kit-de-prototipacao-educacional-e-engenharia/blob/main/Guias%20e%20Livros/Sierra%20Circuits/KiCad%20Design%20Guide%20-%20Sierra%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) |
| capa | [PCB Interfaces & Communication Protocols Handbook Sierra Circuits](https://github.com/RapportTecnologia/kit-de-prototipacao-educacional-e-engenharia/blob/main/Guias%20e%20Livros/Sierra%20Circuits/PCB%20Interfaces%20%26%20Communicati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) | Sierra Circuits | pt | 2025-07-30 | PCB | [PDF](https://github.com/RapportTecnologia/kit-de-prototipacao-educacional-e-engenharia/blob/main/Guias%20e%20Livros/Sierra%20Circuits/PCB%20Interfaces%20%26%20Communicati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) |
| capa | [PCB Material Design Guide Sierra Circuits January 2021](https://github.com/RapportTecnologia/kit-de-prototipacao-educacional-e-engenharia/blob/main/Guias%20e%20Livros/Sierra%20Circuits/PCB%20Material%20Design%20Guide%20Si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) | Sierra Circuits | pt | 2021-01-29 | PCB | [PDF](https://github.com/RapportTecnologia/kit-de-prototipacao-educacional-e-engenharia/blob/main/Guias%20e%20Livros/Sierra%20Circuits/PCB%20Material%20Design%20Guide%20Si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) |
| capa | [PCB Trace and Space Handbook](https://github.com/RapportTecnologia/kit-de-prototipacao-educacional-e-engenharia/blob/main/Guias%20e%20Livros/Sierra%20Circuits/PCB%20Trace%20and%20Space%20Handbook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) | Sierra Circuits | pt | 2025-10-27 | PCB | [PDF](https://github.com/RapportTecnologia/kit-de-prototipacao-educacional-e-engenharia/blob/main/Guias%20e%20Livros/Sierra%20Circuits/PCB%20Trace%20and%20Space%20Handbook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) |
| capa | [PCB Transmission Line eBook](https://github.com/RapportTecnologia/kit-de-prototipacao-educacional-e-engenharia/blob/main/Guias%20e%20Livros/Sierra%20Circuits/PCB%20Transmission%20Line%20eBook%20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) | Sierra Circuits | pt | 2019-03-26 | PCB | [PDF](https://github.com/RapportTecnologia/kit-de-prototipacao-educacional-e-engenharia/blob/main/Guias%20e%20Livros/Sierra%20Circuits/PCB%20Transmission%20Line%20eBook%20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) |
| capa | [PCB Via Design Guide Sierra Circuits](https://github.com/RapportTecnologia/kit-de-prototipacao-educacional-e-engenharia/blob/main/Guias%20e%20Livros/Sierra%20Circuits/PCB%20Via%20Design%20Guide%20Sierra%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) | Sierra Circuits | pt | 2025-07-18 | PCB | [PDF](https://github.com/RapportTecnologia/kit-de-prototipacao-educacional-e-engenharia/blob/main/Guias%20e%20Livros/Sierra%20Circuits/PCB%20Via%20Design%20Guide%20Sierra%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) |
| capa | [RF & Microwave Design Guide Sierra Circuits](https://github.com/RapportTecnologia/kit-de-prototipacao-educacional-e-engenharia/blob/main/Guias%20e%20Livros/Sierra%20Circuits/RF%20%26%20Microwave%20Design%20Guid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) | Sierra Circuits | pt | 2021-10-28 | PCB | [PDF](https://github.com/RapportTecnologia/kit-de-prototipacao-educacional-e-engenharia/blob/main/Guias%20e%20Livros/Sierra%20Circuits/RF%20%26%20Microwave%20Design%20Guid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) |
| capa | [Signal Integrity eBook April 2023](https://github.com/RapportTecnologia/kit-de-prototipacao-educacional-e-engenharia/blob/main/Guias%20e%20Livros/Sierra%20Circuits/Signal%20Integrity%20eBook%20April%2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) | Sierra Circuits | pt | 2023-03-19 | PCB | [PDF](https://github.com/RapportTecnologia/kit-de-prototipacao-educacional-e-engenharia/blob/main/Guias%20e%20Livros/Sierra%20Circuits/Signal%20Integrity%20eBook%20April%2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) |
| capa | [Soldering Flux eBook by Jim Smith December 2022](https://github.com/RapportTecnologia/kit-de-prototipacao-educacional-e-engenharia/blob/main/Guias%20e%20Livros/Sierra%20Circuits/Soldering%20Flux%20eBook%20by%20Jim%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) | Sierra Circuits | pt | 2022-12-20 | PCB | [PDF](https://github.com/RapportTecnologia/kit-de-prototipacao-educacional-e-engenharia/blob/main/Guias%20e%20Livros/Sierra%20Circuits/Soldering%20Flux%20eBook%20by%20Jim%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) |
| capa | [The Designer's HANDBOOK for DFM](https://github.com/RapportTecnologia/kit-de-prototipacao-educacional-e-engenharia/blob/main/Guias%20e%20Livros/Sierra%20Circuits/The%20Designer%27s%20HANDBOOK%20for%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) | Sierra Circuits | pt |  | PCB | [PDF](https://github.com/RapportTecnologia/kit-de-prototipacao-educacional-e-engenharia/blob/main/Guias%20e%20Livros/Sierra%20Circuits/The%20Designer%27s%20HANDBOOK%20for%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) |

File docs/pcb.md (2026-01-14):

---
layout: page
title: "PCB"
subtitle: "Imagens geradas automaticamente a partir do KiCad"
permalink: /pcb/
is_category: true
---

## Lista de PCBs

- <a href="#pcb-kepr">KEPR</a>
- <a href="#pcb-mcu-board-stm32n6">MCU_Board_STM32N6</a>

## KEPR

### Visão 2D (SVG)

<div style="max-width: 1100px; margin: 0 auto;">
  KEPR (SVG)
</div>

### Render 3D (PNG)

<div style="max-width: 1100px; margin: 0 auto;">
  KEPR Top (3D)
</div>

<div style="max-width: 1100px; margin: 0 auto;">
  KEPR Bottom (3D)
</div>

## MCU_Board_STM32N6

### Visão 2D (SVG)

<div style="max-width: 1100px; margin: 0 auto;">
  MCU_Board_STM32N6 (SVG)
</div>

### Render 3D (PNG)

<div style="max-width: 1100px; margin: 0 auto;">
  MCU_Board_STM32N6 Top (3D)
</div>

<div style="max-width: 1100px; margin: 0 auto;">
  MCU_Board_STM32N6 Bottom (3D)
</div>

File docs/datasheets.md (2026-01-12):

---
layout: page
title: "Datasheets"
subtitle: "Documentos técnicos por componente/categoria"
permalink: /datasheets/
is_category: true
---

Os datasheets ficam na pasta `datasheets/` no repositório.

## Connectors

- [DDR4 SODIMM 260pin SMT, 8.0H, STANDARD VERSION, Right  Angle](https://github.com/RapportTecnologia/kit-de-prototipacao-educacional-e-engenharia/blob/main/datasheets/Connectors/DDR4%20SODIMM%20260pin%20SMT%2C%208.0H%2C%20STANDAR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)

## Current Sensors

- [01332b](https://github.com/RapportTecnologia/kit-de-prototipacao-educacional-e-engenharia/blob/main/datasheets/Current%20Sensors/01332b.pdf)
- [ACS758-Datasheet](https://github.com/RapportTecnologia/kit-de-prototipacao-educacional-e-engenharia/blob/main/datasheets/Current%20Sensors/ACS758-Datasheet.pdf)
- [ACS772-Datasheet](https://github.com/RapportTecnologia/kit-de-prototipacao-educacional-e-engenharia/blob/main/datasheets/Current%20Sensors/ACS772-Datasheet.pdf)
- [ACS773-Datasheet](https://github.com/RapportTecnologia/kit-de-prototipacao-educacional-e-engenharia/blob/main/datasheets/Current%20Sensors/ACS773-Datasheet.pdf)
- [ina219](https://github.com/RapportTecnologia/kit-de-prototipacao-educacional-e-engenharia/blob/main/datasheets/Current%20Sensors/ina219.pdf)
- [slyy154b](https://github.com/RapportTecnologia/kit-de-prototipacao-educacional-e-engenharia/blob/main/datasheets/Current%20Sensors/slyy154b.pdf)

## Geral

- [an5215-how-to-implement-advanced-power-management-on-stm32h747757-mcus-stmicroelectronics](https://github.com/RapportTecnologia/kit-de-prototipacao-educacional-e-engenharia/blob/main/datasheets/an5215-how-to-implement-advanced-power-management-on-stm32h747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)
- [power-management-guide](https://github.com/RapportTecnologia/kit-de-prototipacao-educacional-e-engenharia/blob/main/datasheets/power-management-guide.pdf)
- [System-Level ESD Protection Guide (Rev. E) - Texas Instruments, Incorporated [SSZB130,E](https://github.com/RapportTecnologia/kit-de-prototipacao-educacional-e-engenharia/blob/main/datasheets/System-Level%20ESD%20Protection%20Guide%20%28Rev.%20E%29%20-%2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)
- [TXS0108E 8-Bit Bi-Directional, Level-Shifting, Voltage Translator for Open-Drain and Push-Pull Applications - txs0108e](https://github.com/RapportTecnologia/kit-de-prototipacao-educacional-e-engenharia/blob/main/datasheets/TXS0108E%208-Bit%20Bi-Directional%2C%20Level-Shifting%2C%20Vol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)

## MCU

- [an2629-stm32f101xx-stm32f102xx-and-stm32f103xx-lowpower-modes-stmicroelectronics](https://github.com/RapportTecnologia/kit-de-prototipacao-educacional-e-engenharia/blob/main/datasheets/MCU/STM32F103c8/an2629-stm32f101xx-stm32f102xx-and-stm32f103xx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)
- [an2867-guidelines-for-oscillator-design-on-stm8afals-and-stm32-mcusmpus-stmicroelectronics](https://github.com/RapportTecnologia/kit-de-prototipacao-educacional-e-engenharia/blob/main/datasheets/MCU/an2867-guidelines-for-oscillator-design-on-stm8afals-and-s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)
- [an4488-getting-started-with-stm32f4xxxx-mcu-hardware-development-stmicroelectronics](https://github.com/RapportTecnologia/kit-de-prototipacao-educacional-e-engenharia/blob/main/datasheets/MCU/an4488-getting-started-with-stm32f4xxxx-mcu-hardware-devel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)
- [an4538-power-consumption-optimization-with-stm32f3xx-microcontrollers-stmicroelectronics](https://github.com/RapportTecnologia/kit-de-prototipacao-educacional-e-engenharia/blob/main/datasheets/MCU/an4538-power-consumption-optimization-with-stm32f3xx-micro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)
- [an4938-getting-started-with-stm32h74xig-and-stm32h75xig-mcu-hardware-development-stmicroelectronics](https://github.com/RapportTecnologia/kit-de-prototipacao-educacional-e-engenharia/blob/main/datasheets/MCU/an4938-getting-started-with-stm32h74xig-and-stm32h75xig-mc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)
- [an5306-operational-amplifier-opamp-usage-in-stm32g4-series-stmicroelectronics](https://github.com/RapportTecnologia/kit-de-prototipacao-educacional-e-engenharia/blob/main/datasheets/MCU/an5306-operational-amplifier-opamp-usage-in-stm32g4-series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)
- [an5307-getting-started-with-stm32h7a37b3-line-and-stm32h7b0-value-line-microcontroller-hardware-development-stmicroelectronics](https://github.com/RapportTecnologia/kit-de-prototipacao-educacional-e-engenharia/blob/main/datasheets/MCU/an5307-getting-started-with-stm32h7a37b3-line-and-stm32h7b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)
- [an5612-esd-protection-of-stm32-mcus-and-mpus-stmicroelectronics](https://github.com/RapportTecnologia/kit-de-prototipacao-educacional-e-engenharia/blob/main/datasheets/MCU/an5612-esd-protection-of-stm32-mcus-and-mpus-stmicroelectr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)
- [dm00337873-getting-started-with-stm32h74xig-and-stm32h75xig-hardware-development-stmicroelectronics](https://github.com/RapportTecnologia/kit-de-prototipacao-educacional-e-engenharia/blob/main/datasheets/MCU/dm00337873-getting-started-with-stm32h74xig-and-stm32h75xi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)
- [DS12712](https://github.com/RapportTecnologia/kit-de-prototipacao-educacional-e-engenharia/blob/main/datasheets/MCU/STM32G473xx/DS12712.pdf)
- [DS9895](https://github.com/RapportTecnologia/kit-de-prototipacao-educacional-e-engenharia/blob/main/datasheets/MCU/STM32F301C8T6/DS9895.pdf)
- [stm32f103c8](https://github.com/RapportTecnologia/kit-de-prototipacao-educacional-e-engenharia/blob/main/datasheets/MCU/STM32F103c8/stm32f103c8.pdf)
- [stm32g484ce](https://github.com/RapportTecnologia/kit-de-prototipacao-educacional-e-engenharia/blob/main/datasheets/MCU/STM32G484CxE/stm32g484ce.pdf)

## MosFETs

- [BSS138 - N-Channel Logic Level Enhancement Mode Field Effect Transistor - onsemi](https://github.com/RapportTecnologia/kit-de-prototipacao-educacional-e-engenharia/blob/main/datasheets/MosFETs/BSS138%20-%20N-Channel%20Logic%20Level%20Enhancement%2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)

## Power Rail

- [ADMSS00087-1](https://github.com/RapportTecnologia/kit-de-prototipacao-educacional-e-engenharia/blob/main/datasheets/Power%20Rail/ADMSS00087-1.pdf)
- [lm1117](https://github.com/RapportTecnologia/kit-de-prototipacao-educacional-e-engenharia/blob/main/datasheets/Power%20Rail/lm1117.pdf)
- [REF19xSeries](https://github.com/RapportTecnologia/kit-de-prototipacao-educacional-e-engenharia/blob/main/datasheets/Power%20Rail/REF19xSeries.pdf)
- [tdn1wism datasheet](https://github.com/RapportTecnologia/kit-de-prototipacao-educacional-e-engenharia/blob/main/datasheets/Power%20Rail/tdn1wism_datasheet.pdf)

## Resistors

- [816258685 TE Connectivity](https://github.com/RapportTecnologia/kit-de-prototipacao-educacional-e-engenharia/blob/main/datasheets/Resistors/816258685_TE_Connectivity.pdf)
- [CRCW0805100RFKEAC Vishay Dale](https://github.com/RapportTecnologia/kit-de-prototipacao-educacional-e-engenharia/blob/main/datasheets/Resistors/CRCW0805100RFKEAC_Vishay_Dale.pdf)
- [CRT0805-BY-5001EAS Bourns](https://github.com/RapportTecnologia/kit-de-prototipacao-educacional-e-engenharia/blob/main/datasheets/Resistors/CRT0805-BY-5001EAS_Bourns.pdf)
- [ERA6ARW472V Panasonic](https://github.com/RapportTecnologia/kit-de-prototipacao-educacional-e-engenharia/blob/main/datasheets/Resistors/ERA6ARW472V_Panasonic.pdf)
- [MCU08050C2203FP500 Vishay](https://github.com/RapportTecnologia/kit-de-prototipacao-educacional-e-engenharia/blob/main/datasheets/Resistors/MCU08050C2203FP500_Vishay.pdf)
- [RC0805FR-07330RL Yageo](https://github.com/RapportTecnologia/kit-de-prototipacao-educacional-e-engenharia/blob/main/datasheets/Resistors/RC0805FR-07330RL_Yageo.pdf)

## Shunt

- [gmr-e](https://github.com/RapportTecnologia/kit-de-prototipacao-educacional-e-engenharia/blob/main/datasheets/Shunt/gmr-e.pdf)

## Zener

- [Diodes Inc.-1N4733A-T-datasheet](https://github.com/RapportTecnologia/kit-de-prototipacao-educacional-e-engenharia/blob/main/datasheets/Zener/Diodes_Inc.-1N4733A-T-datasheet.pdf)

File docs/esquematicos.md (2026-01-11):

---
title: "Esquemáticos"
permalink: /esquematicos/
is_category: true
---

<div class="callout">
  <p>Imagens exportadas automaticamente a partir dos esquemáticos do projeto.</p>
</div>

## Mapa

- <a href="#sch-buses">BUSes</a>
- <a href="#sch-debug-mod-bus">DEBUG_MOD_Bus</a>
- <a href="#sch-external-power-rails">External_Power_Rails</a>
- <a href="#sch-kepr">KEPR</a>
- <a href="#sch-mcu-board-stm32n6">MCU_Board_STM32N6</a>
- <a href="#sch-mcu-board-stm32n6-bus">MCU_Board_STM32N6_Bus</a>
- <a href="#sch-mcu-boards">MCU_Boards</a>
- <a href="#sch-network-mod-bus">NETWORK_MOD_Bus</a>
- <a href="#sch-power-rails">POWER_Rails</a>
- <a href="#sch-uce-bus">UCE_Bus</a>
- <a href="#sch-uce-external-bus">UCE_External_Bus</a>
- <a href="#sch-uce-board">UCE_board</a>
- <a href="#sch-wireless-mod-bus">WIRELESS_MOD_Bus</a>

## Esquemáticos

### BUSes

BUSes

### DEBUG_MOD_Bus

DEBUG_MOD_Bus

### External_Power_Rails

External_Power_Rails

### KEPR

<div style="position: relative; width: 100%;">
KEPR

</div>

### MCU_Board_STM32N6

MCU_Board_STM32N6

### MCU_Board_STM32N6_Bus

MCU_Board_STM32N6_Bus

### MCU_Boards

MCU_Boards

### NETWORK_MOD_Bus

NETWORK_MOD_Bus

### POWER_Rails

POWER_Rails

### UCE_Bus

UCE_Bus

### UCE_External_Bus

UCE_External_Bus

### UCE_board

UCE_board

### WIRELESS_MOD_Bus

WIRELESS_MOD_Bus

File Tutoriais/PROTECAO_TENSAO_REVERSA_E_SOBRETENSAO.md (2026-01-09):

# Proteção contra tensão reversa e sobretensão (3.3 V a 12 V)

Este tutorial descreve como projetar um estágio de proteção para um **power rail/barramento DC** na faixa de **3.3 V a 12 V**, para reduzir o risco de dano quando:

- a alimentação é conectada com **polaridade invertida**;
- o usuário aplica uma **tensão maior do que a permitida** no barramento (ex.: injetar 12 V em um rail de 3.3 V);
- existe risco de **injeção de tensão** por outro caminho (ex.: cabo externo, periféricos, pinos de expansão, ESD, etc.).

A ideia geral é separar o problema em 2 funções:

- **1) bloquear corrente no sentido errado** (reverse polarity / backfeed)
- **2) limitar/desconectar em caso de sobretensão** (OVP)

A solução “certa” depende do que você quer proteger:

- **Barramento como entrada de energia** (um conector recebe alimentação externa)
- **Barramento como distribuição interna** (gerado na placa e exposto ao usuário)

Em projetos educacionais (onde o usuário pode errar), normalmente vale a pena usar uma proteção mais robusta, mesmo que custe mais.

## 0) Premissas deste projeto

- Os rails (3.3 V, 5 V, 12 V) são **somente saída**.
- Cada rail deve suportar até **1 A**.

Consequência importante:

- A proteção deve **impedir que o usuário alimente o rail por fora** (backfeed). Ou seja, além de proteger contra polaridade reversa/sobretensão, o estágio deve ter **bloqueio de corrente reversa** (de `VOUT` para `VIN`).

## 1) Cenários de falha típicos

### 1.1) Polaridade reversa

Exemplos:

- fonte DC com conector 2 vias invertido;
- jacaré/banana invertidos;
- cabo de alimentação montado errado.

Efeito:

- sem proteção, componentes podem conduzir pela junção PN e queimar rapidamente.

### 1.2) Sobretensão (o caso “12 V no rail de 3.3 V”)

Exemplos:

- o usuário conecta o rail errado no conector (mistura 3.3 V/5 V/12 V);
- um módulo externo injeta 12 V por engano em um pino que deveria ser 3.3 V.

Efeito:

- 3.3 V é excedido rapidamente, e geralmente o dano ocorre em:
  - MCU/SoC (pinos e VDD)
  - sensores
  - LDOs/bucks (se estiverem “no caminho reverso”)

### 1.3) Backfeed (injeção por carga)

Mesmo se você protege o “input principal”, ainda pode existir injeção por:

- sinais de IO com diodos internos (clamp ESD nos pinos do MCU)
- periféricos conectados
- outra fonte conectada em paralelo

Para esse caso, quase sempre você precisa de **isolamento por caminho de alimentação** (série com MOSFET/eFuse) e de regras de interface (resistores, proteção de IO, etc.).

## 2) Requisitos práticos (o que definir antes)

Defina, para cada rail que será exposto ao usuário (3.3 V, 5 V, 12 V):

- **Vnom**: tensão nominal (3.3/5/12)
- **Imax**: corrente máxima esperada
- **Vrev**: quanto tempo/nível você quer sobreviver com polaridade invertida (idealmente indefinido)
- **Vov_trip**: tensão em que deve desligar (ex.: 3.6–4.0 V para rail 3.3 V)
- **Energia de surtos/ESD**: se o conector for “externo”, você precisa de TVS

Também defina se o rail pode ser **entrada OU saída** (bidirecional). Em rails “educacionais”, muitas vezes o rail é exposto como saída, mas o usuário pode tentar usar como entrada.

- Se você quer **impedir que o rail seja alimentado por fora**, você precisa bloquear backfeed.

Nesta placa, como os rails são **somente saída**, o bloqueio de backfeed não é opcional.

## 3) Topologia A (simples, barata): fusível + MOSFET de polaridade + TVS

Esta topologia é boa para:

- polaridade reversa;
- surtos/ESD;
- curto na saída (dependendo do fusível);

Mas **não é a melhor** para “12 V aplicado em rail 3.3 V”, porque o TVS pode ter que absorver muita energia e o fusível pode demorar a atuar.

### 3.1) Bloco do circuito

```
VIN ---- F1 ---- Q1 (MOSFET ideal diode) ---- VOUT ---- COUT ---- carga
                         |
                         +---- DTVS para GND (opcional, recomendado em conector)
```

- **F1**: polyfuse (PTC) ou fusível normal.
- **Q1**: MOSFET canal P no high-side (ou N com controlador ideal diode). Configurado para atuar como “diodo ideal” (baixa queda) e bloquear reverso.
- **DTVS**: TVS para proteger contra ESD e transientes rápidos (não para “segurar 12 V indefinidamente”).

Notas de dimensionamento (para até 1 A):

- Para não perder muita tensão, você quer **Rds(on) baixo**. Exemplo de ordem de grandeza:
  - alvo `Rds(on) <= 50 mΩ` (em condições realistas de `VGS`)
  - queda a 1 A: `V = I*R = 1A*0.05Ω = 50 mV`
  - dissipação a 1 A: `P = I²*R = 1²*0.05 = 50 mW`
- Se usar PTC como F1, escolha um modelo com:
  - `Ihold` maior que sua corrente nominal contínua (ex.: 1 A)
  - `Itrip` coerente com sua fonte/corrente de curto
  - atenção: PTC pode demorar para atuar e deixa a placa aquecida durante falha.

### 3.2) Como o MOSFET bloqueia reverso (visão rápida)

- Com polaridade correta, você puxa o gate do MOSFET de forma que `VGS` fique negativo e o MOSFET conduza.
- Com polaridade invertida, o diodo de corpo fica reversamente polarizado e o MOSFET desliga, bloqueando corrente.

### 3.3) Limitações desta topologia

- **Sobretensão contínua** (ex.: 12 V em rail 3.3 V) só é “resolvida” se:
  - o TVS entrar em avalanche e o **fusível abrir/limitar** rápido o suficiente;
  - e a energia térmica for aceitável.

Em um produto educacional, isso pode funcionar como “último recurso”, mas não é uma proteção elegante.

## 4) Topologia B (recomendada): eFuse/hot-swap com reverse + OVP cutoff

Para evitar dano quando o usuário aplica a tensão errada, o ideal é **desconectar o rail automaticamente** quando `VOUT` ou `VIN` passar do limite.

A forma mais prática e robusta é usar um **eFuse / load switch com proteção**.

### 4.1) Bloco do circuito

```
VIN ---- (TVS) ---- eFuse/LoadSwitch (reverse + OVP + ILIM) ---- VOUT ---- carga
```

Esse CI geralmente fornece:

- **Reverse input protection** (bloqueia polaridade invertida)
- **Reverse current blocking** (impede backfeed do VOUT para VIN)
- **Overvoltage protection (OVP)**: desliga acima de um threshold
- **Current limit / short protection**: limita corrente em falha
- **Thermal shutdown**

### 4.2) Como aplicar na faixa 3.3 V a 12 V

Em um sistema com múltiplos rails expostos (3.3/5/12), a prática recomendada é:

- Ter **um eFuse por rail exposto**, com limiar de OVP adequado:
  - rail 3.3 V: trip ~3.6–4.0 V
  - rail 5 V: trip ~5.6–6.5 V
  - rail 12 V: trip ~13.0–15 V (dependendo do que seus componentes suportam)

Assim, se o usuário aplicar 12 V no rail 3.3 V, o eFuse do rail 3.3 V **abre** e isola o barramento rapidamente.

Para o requisito de 1 A:

- Selecione eFuse/load switch com `ILIM` programável ou fixo que suporte:
  - corrente contínua >= 1 A
  - eventos de curto (foldback/limite/thermal)
- Verifique a queda de tensão no caminho:
  - `Vdrop ≈ I * Ron` (para load switches com resistência de condução)
  - quanto menor `Ron`, melhor para manter 3.3 V dentro da tolerância com 1 A.

### 4.3) Componentes típicos ao redor do eFuse

- Capacitores de entrada/saída (para estabilidade e resposta a transientes)
- Resistor/programação de limite de corrente (se aplicável)
- Pino `EN` e/ou `FAULT` para o MCU sinalizar e registrar falhas

### 4.4) Vantagens

- Atua rápido e de forma repetível.
- Dissipa menos que uma proteção “crowbar+fusível” em erros comuns.
- Ajuda muito no caso de **injeção** e **backfeed**.

### 4.5) Observações importantes

- Verifique a **faixa de operação do CI** (tensão máxima absoluta e tensão operacional).
- Confirme se ele bloqueia **reverse current** (muitos load switches simples não bloqueiam).

## 5) Alternativa clássica para OVP: “crowbar” + fusível (quando faz sentido)

Outra técnica é forçar um curto controlado quando `VOUT` excede o limite, fazendo o fusível atuar:

- Comparador/referência detecta sobretensão.
- Um SCR/triac/MOSFET é acionado, “derrubando” o rail.

Essa abordagem pode ser útil quando:

- você quer uma proteção de sobretensão muito “agressiva”;
- a fonte que alimenta o rail é limitada;
- você aceita trocar fusível (ou deixar o PTC aquecer e limitar).

Mas em rails educacionais (onde o usuário pode errar várias vezes), eFuse costuma ser melhor UX.

## 6) Checklist de implementação (o que não esquecer)

- **Proteção precisa estar o mais perto possível do conector** onde o erro pode acontecer.
- Use **TVS** em entradas expostas para ESD/transientes.
- Garanta **bloqueio de corrente reversa** (backfeed) quando o rail pode ser alimentado externamente.
- Considere também a **proteção dos sinais (IO)**: se o usuário injeta tensão por um pino de sinal, o rail pode subir via diodos internos.
- Se houver conversores DC-DC/LDO, verifique se precisam de:
  - diodo de bypass (proteção contra corrente reversa)
  - ou se o próprio eFuse resolve o backfeed

## 7) Recomendação direta para este caso (rails somente saída, até 1 A)

- Use **um estágio com bloqueio de corrente reversa + OVP por rail exposto**.
- Para o rail **3.3 V**, priorize uma solução que realmente **desconecte** em sobretensão (Topologia B), porque:
  - “12 V no 3.3 V” não é transiente rápido, é erro de conexão;
  - depender só de TVS/Zener vira dissipação e pode falhar.
- Para os rails **5 V** e **12 V**, a mesma lógica se aplica: OVP + reverse-current blocking melhora muito a sobrevivência do kit.

## 8) Recomendações práticas (para um kit educacional)

- Se o rail **3.3 V** for exposto ao usuário: use **eFuse com OVP ajustada** (Topologia B).
- Se o rail **12 V** for exposto ao usuário: use eFuse com **limite de corrente** e **TVS**.
- Evite depender apenas de Zener/TVS para “aguentar 12 V no 3.3 V”: isso vira dissipação térmica e pode falhar.

Observação sobre TVS:

- TVS é excelente para **ESD/transientes curtos**.
- Para erro contínuo de ligação (ex.: conectar 12 V fixo no conector do rail 3.3 V), o elemento que “resolve” deve ser a **desconexão** (eFuse/load switch) e não o TVS.

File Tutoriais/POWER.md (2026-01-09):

# Alimentação (POWER) e Power Rails do KEPR

## Referências

- https://wiki.st.com/stm32mcu/wiki/Basics_of_power_supply_design_for_MCU
- https://www.youtube.com/watch?v=a64UIK1dFXA

## O que são “Power Rails” no KEPR

 No KEPR, “Power Rails” são os **barramentos de tensão** distribuídos por toda a placa.
 Eles têm duas funções principais:

- **Alimentar os circuitos internos** (microcontrolador, periféricos e blocos de interface).
- **Serem externalizados para o usuário (aluno)**, permitindo alimentar circuitos externos (protoboard, módulos, sensores) com tensões padronizadas.

 Esses rails são gerados a partir de **conversores DC-DC chaveados**, o que permite boa eficiência e disponibilidade de diferentes níveis de tensão.

## Rails principais

### Entrada: `+24V`

- **Papel no sistema:** barramento de entrada/primário.
- **Origem:** alimentação externa (entrada de energia do kit).
- **Uso:** serve como “fonte base” para os conversores que geram as demais tensões.

### Rail: `+12V`

- **Papel no sistema:** barramento para cargas e experimentos que necessitam de 12 V.
- **Origem:** gerado por conversão a partir do rail de entrada.
- **Uso:** pode alimentar circuitos internos específicos e também é disponibilizado externamente.

### Rail: `+5V`

- **Papel no sistema:** barramento de uso geral para periféricos, módulos e experimentos.
- **Origem:** gerado por conversor DC-DC.
- **Uso:** distribuição interna e disponibilização ao aluno para protótipos e módulos 5 V.

### Rail: `+3.3V`

- **Papel no sistema:** principal barramento lógico do sistema (MCU e sensores digitais).
- **Origem:** gerado por conversor DC-DC.
- **Uso:** distribuição interna e disponibilização ao aluno para circuitos 3,3 V.

## Instrumentação (Shunt) e controle de rails

 Em alguns pontos do projeto aparecem nets do tipo:

- `+3v3 Shunt` / `+3.3v Shunt Out`
- `+5v Shunt` / `+5v Shunt Out`
- `+12v Shunt`

 A ideia é que o rail passe por um **shunt (resistor de baixa resistência)** para permitir **medição/monitoramento de corrente** (didático e útil para diagnóstico).
 Em termos práticos:

- **`<rail> Shunt`**: lado “antes” do shunt.
- **`<rail> Shunt Out`**: lado “depois” do shunt, já pronto para distribuição.

## Como o aluno usa os Power Rails externamente

 O KEPR disponibiliza os rails em conectores/headers no conjunto de “External Power Rails”, tipicamente incluindo:

- `GND` (referência comum)
- `+3.3V`
- `+5V`
- `+12V`

 Assim, o aluno pode:

- Alimentar protoboard e módulos diretamente com `+3.3V` ou `+5V`.
- Usar `+12V` quando o experimento exigir (motores/atuadores específicos, drivers, etc.).
- Sempre compartilhar o **mesmo `GND`** entre o KEPR e o circuito externo.

## Boas práticas e segurança

- **Verifique polaridade antes de ligar.** Inversão de polaridade pode danificar conversores e periféricos.
- **Use sempre `GND` comum.** Sinais lógicos e medições só funcionam corretamente com referência comum.
- **Não misture níveis de tensão em GPIO.**
  - GPIOs do MCU são tipicamente `3.3V`.
  - Não aplique `5V` diretamente em pinos do MCU (use conversão de nível quando necessário).
- **Cuidado com curto-circuito.** Um curto em `+5V`/`+3.3V` pode derrubar o rail e aquecer componentes.
- **Não exceda a capacidade de corrente dos rails.** Se o experimento exigir mais corrente (motores grandes, cargas resistivas), use fonte dedicada e apenas compartilhe `GND`.

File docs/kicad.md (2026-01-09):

---
layout: page
title: "KiCad"
subtitle: "Arquivos de CAD eletrônico do projeto"
permalink: /kicad/
is_category: true
---

O projeto KiCad principal está em `kicad/KEPR/` no repositório.

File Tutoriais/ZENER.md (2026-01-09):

# Regulador com diodo Zener para obter 3.3 V
 
 Referência rápida:
 
 * https://www.tmatlantic.com/encyclopedia/index.php?ELEMENT_ID=54204
 
 ## 1) Contexto e ponto crítico: Vin = 3.3 V
 
 Um regulador “Zener + resistor” é um **regulador shunt**:
 
 - **R** em série limita corrente.
 - O **Zener** “puxa” corrente para manter a tensão no nó próximo de `VZ`.
 
 Isso só funciona se houver **folga de tensão** no resistor:
 
 - Se `Vin = 3.3 V` e você quer `Vout = 3.3 V`, então `Vin - Vout ≈ 0 V`.
 - Com `0 V` no resistor, não há corrente “sobrando” para alimentar a carga **e** manter `IZ` no Zener.
 
 Portanto:
 
 - **Com Vin = 3.3 V, Zener NÃO regula**. A saída ficará `<= Vin` e ainda pode cair por causa de resistências e dinâmica de carga.
 - Zener só faz sentido aqui se **Vin for maior que 3.3 V por uma margem** (ex.: 5 V, 12 V, etc.).
 
 Se sua alimentação pode ser `3.3 V` (igual ao alvo), o correto é:
 
 - **não usar Zener como regulador**, e sim garantir uma fonte `3.3 V` estável (LDO/buck) ou aceitar que `Vout ≈ Vin`.
 
 ## 2) Dados de corrente do STM32G484 (ordem de grandeza)
 
 No datasheet do `STM32G484CE` (tabelas de “Typical current consumption in Run and Low-power run modes”), valores típicos indicados incluem:
 
 - **Run ~150 MHz (Range 1, PLL ON)**: `IDD ≈ 17.5 mA` (típico, dependendo do código/atividade).
 - **Run ~26 MHz**: `IDD ≈ 2.65 mA` (típico, dependendo do código/atividade).
 - **Low-power run ~2 MHz**: `IDD ≈ 825 µA` (típico, dependendo do código/atividade).
 
 Importante:
 
 - Esses números variam com clock, periféricos, GPIOs, carga externa, temperatura e VDD.
 - Para dimensionar, você deve usar um `Iload_max` que represente **o pior caso do seu firmware + periféricos alimentados em 3.3 V**.
 
 Para este tutorial, vou assumir um exemplo conservador para o “consumo do nó 3.3 V”:
 
 - `Iload_max = 25 mA` (MCU em alta performance + alguma margem)
 
 Ajuste esse número para a sua realidade.
 
 ## 3) Escolha do Zener (3.3 V)
 
 Escolha um Zener nominal `VZ ≈ 3.3 V` (ex.: `BZX55C3V3`, `BZT52C3V3`, etc.).
 
 Atenção às diferenças:
 
 - **VZ depende da corrente `IZ`** (é especificado em uma corrente de teste `IZT`).
 - **Tolerância** (ex.: 2%, 5%) e **coeficiente de temperatura** importam.
 - Em `IZ` muito baixo, o Zener pode ficar “mole” (regulação ruim).
 
 Para um regulador shunt simples, normalmente você escolhe uma corrente mínima de Zener para manter a regulação aceitável, por exemplo:
 
 - `IZ_min` entre `2 mA` e `5 mA` (depende do diodo escolhido e da qualidade de regulação desejada)
 
 Neste tutorial vou usar:
 
 - `IZ_min = 5 mA`
 
 ## 4) Cálculo do resistor série (R)
 
 ### Fórmula base
 
 A corrente no resistor é:
 
 `IR = (Vin - Vout) / R`
 
 E ela se divide em:
 
 `IR = Iload + IZ`
 
 Para garantir regulação no pior caso (carga máxima), queremos:
 
 `IZ >= IZ_min` quando `Iload = Iload_max`.
 
 Então, no pior caso:
 
 `IR_min_needed = Iload_max + IZ_min`
 
 Logo:
 
 `R_max = (Vin_min - Vout) / (Iload_max + IZ_min)`
 
 Você escolhe `R <= R_max`.
 
 ### Exemplo 1: Vin_min = 5.0 V
 
 Dados:
 
 - `Vin_min = 5.0 V`
 - `Vout ≈ VZ = 3.3 V`
 - `Iload_max = 25 mA`
 - `IZ_min = 5 mA`
 
 Corrente mínima necessária no resistor:
 
 - `IR = 25 mA + 5 mA = 30 mA`
 
 Queda no resistor:
 
 - `Vr = 5.0 - 3.3 = 1.7 V`
 
 Resistência máxima:
 
 - `R_max = 1.7 V / 0.03 A ≈ 56.7 ohms`
 
 Escolha comercial típica:
 
 - `R = 56 ohms` (E24)
 
 Verificação rápida (com `R=56 ohms`):
 
 - `IR = 1.7/56 ≈ 30.4 mA`
 - Com `Iload=25 mA`, sobra `IZ ≈ 5.4 mA` (ok)
 
 ### Exemplo 2: Vin_min = 3.6 V (margem pequena)
 
 Se `Vin_min = 3.6 V`:
 
 - `Vr = 3.6 - 3.3 = 0.3 V`
 - Para `IR=30 mA`: `R_max = 0.3/0.03 = 10 ohms`
 
 Aqui fica claro o problema: com folga pequena, o resistor precisa ser muito baixo, e o circuito passa a ser:
 
 - muito sensível a variações,
 - com dissipação considerável,
 - e com regulação ruim (porque `IZ` fica “no limite”).
 
 ## 5) Checagem de corrente máxima (carga mínima)
 
 O pior caso para o Zener (dissipação) costuma ser quando a carga consome pouco:
 
 - `Iload_min` pequeno (ex.: MCU em reset, sleep, ou desconectado)
 - `Vin_max` alto
 
 Nesse caso:
 
 - `IZ_max ≈ IR` (quase toda corrente vai para o Zener)
 
 Fórmula:
 
 - `IR_max = (Vin_max - Vout) / R`
 - `IZ_max ≈ IR_max - Iload_min`
 
 ## 6) Potência no resistor e no Zener
 
 ### Potência no resistor
 
 - `PR = (Vin - Vout) * IR`  (ou `PR = IR^2 * R`)
 
 ### Potência no Zener
 
 - `PZ = Vout * IZ`
 
 #### Exemplo com Vin = 5.5 V, R = 56 ohms, carga mínima ~0 mA
 
 - `IR = (5.5 - 3.3)/56 = 2.2/56 ≈ 39.3 mA`
 - `IZ ≈ 39.3 mA`
 - `PR = 2.2 V * 39.3 mA ≈ 86 mW`
 - `PZ = 3.3 V * 39.3 mA ≈ 130 mW`
 
 Seleção de componentes:
 
 - Resistor: use pelo menos `1/4 W` para margem térmica confortável.
 - Zener: escolha pelo menos `500 mW` se houver chance de `Vin_max` maior, ambiente quente, ou carga frequentemente baixa.
 
 ## 7) Conclusões e recomendações
 
 - **Se Vin pode ser 3.3 V**, o Zener **não** é regulador: ele não tem “headroom” para funcionar.
 - Para `Vin > 3.3 V`, dá para dimensionar com:
   - `R` garantindo `IZ_min` no pior caso de carga.
   - checagem de `IZ_max` e potências no pior caso de `Vin_max` e carga mínima.
 - Para alimentar um MCU, normalmente é melhor usar:
   - **LDO 3.3 V** (se Vin for 5 V e corrente moderada), ou
   - **buck 3.3 V** (se Vin for bem maior ou eficiência for importante).

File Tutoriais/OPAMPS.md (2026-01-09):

# Medição de corrente com shunt usando OPAMP1..3 + ADC no STM32G484CETx
 
 Este tutorial descreve como usar os OPAMPs internos `OPAMP1`, `OPAMP2`, `OPAMP3` do **STM32G484CETx** para medir a corrente nos resistores shunt do projeto, e como calcular:
 
 - a corrente em cada shunt;
 - a queda de tensão no shunt;
 - a tensão efetiva do barramento após a queda.
 
 A referência principal é a configuração do CubeMX (`firmware_UCE.ioc`) e o esquemático (`UCE_board.kicad_sch`).
 
 ## 1) Visão geral do hardware (shunts e sinais)
 
 No esquemático, os shunts de medição são:
 
 - **R2**: shunt do barramento **3.3V**
 - **R3**: shunt do barramento **5V**
 - **R4**: shunt do barramento **12V**
 
 Cada shunt tem dois pontos de medição (antes/depois do shunt), nomeados no `.ioc` como “in” e “out” (pontos Kelvin/sense).
 
 ### 1.1) Part number / família do shunt
 
 No esquemático, os shunts são da família ROHM **GMR-E** (ex.: `GMR320...`). O símbolo indica a família `GMR320HJAAFD5L00` e o campo `Datasheet` aponta para `gmr-e.pdf`.
 
 Observação prática: no arquivo do esquemático aparecem variações no campo `Value`:
 
 - R2: `GMR320HJAAFM5L00`
 - R3: `GMR320HJAAFS5L00`
 - R4: `GMR320HJAAFE5L00`
 
 O datasheet mostra que esses códigos são usados para identificar variações de resistência/tolerância dentro da mesma série.
 
 #### 1.1.1) Como extrair `Rshunt` pelo código (conforme `gmr-e.pdf`)
 
 O datasheet apresenta a estrutura do código do produto, onde aparecem:
 
 - a **série/tamanho** (ex.: `GMR320` = 7142 / 2817, alta potência)
 - o **código de tolerância** (ex.: `F` = ±1%)
 - um **special code** que define valores típicos de resistência (ex.: `D` = 5mΩ, `E` = 15mΩ/150mΩ, `M` = 33mΩ, `S` = 56mΩ, etc.)
 - um **código de resistência** (no exemplo do datasheet aparecem códigos como `10L0`, `R015`, `R100`)
 
 Como o campo `Value` do esquemático contém apenas o part number completo (sem a tabela ao lado), a forma mais segura é:
 
 - confirmar `Rshunt` no BOM/compra (Mouser/nota fiscal/etiqueta do reel) **ou**
 - decodificar pelo datasheet (usando as tabelas de `special code` e do código de resistência).
 
 **Para cálculo no firmware, defina `Rshunt_3v3`, `Rshunt_5v`, `Rshunt_12v` explicitamente (em ohms) e não “assuma” pelo part number.**
 
 ## 2) Mapeamento de pinos (conforme `firmware_UCE.ioc`)
 
 O CubeMX está configurado para usar os OPAMPs como front-end e ler a saída deles via canais internos do ADC:
 
 ### 2.1) OPAMP1 + ADC1 (shunt 3.3V)
 
 - **OPAMP1_VINP**: `PA1` (label: `shunt_3v3_in`)
 - **OPAMP1_VINM0**: `PA3` (label: `shunt_3v3out`)
 - **ADC1**: canal `ADC_CHANNEL_VOPAMP1`
 
 ### 2.2) OPAMP2 + ADC2 (shunt 5V)
 
 - **OPAMP2_VINP**: `PA7` (label: `shunt_5v_in`)
 - **OPAMP2_VINM0**: `PA5` (label: `shunt_5v_out`)
 - **ADC2**: canal `ADC_CHANNEL_VOPAMP2`
 
 ### 2.3) OPAMP3 + ADC3 (shunt 12V)
 
 - **OPAMP3_VINP**: `PB0` (label: `shunt_12v_in`)
 - **OPAMP3_VINM0**: `PB2` (label: `shunt_12v_out`)
 - **ADC3**: canal `ADC_CHANNEL_VOPAMP3_ADC3`
 
 ## 3) Configuração do ADC (como está no projeto)
 
 No código gerado (`Core/Src/adc.c`), todos os ADCs estão em:
 
 - resolução **12 bits** (`ADC_RESOLUTION_12B`)
 - alinhamento à direita
 - conversão por **software start** (`ADC_SOFTWARE_START`)
 - 1 conversão por sequência (`NbrOfConversion = 1`)
 - amostragem: `ADC_SAMPLETIME_12CYCLES_5`
 
 Importante: o `adc.c` está configurado para ler os canais internos `VOPAMP1`, `VOPAMP2`, `VOPAMP3`.
 
 ## 4) Configuração do OPAMP (como usar no STM32G4)
 
 No estado atual do repositório, `Core/Src/opamp.c` contém apenas as funções `MX_OPAMP1_Init()`, `MX_OPAMP2_Init()`, `MX_OPAMP3_Init()` vazias.
 
 Isso significa que:
 
 - o roteamento dos pinos está definido no `.ioc`;
 - o ADC está pronto para ler `VOPAMPx`;
 - **mas falta inicializar e habilitar os OPAMPs** (seleção de modo, entrada, ganho e start).
 
 Recomendações para configurar no CubeMX (STM32G4 OPAMP):
 
 - **Modo**: para medir shunt normalmente você usa o OPAMP como amplificador (PGA) ou como amplificador não inversor com ganho definido.
 - **Ganho**: selecione um ganho tal que a queda de tensão máxima no shunt, multiplicada pelo ganho, não ultrapasse `VREF` do ADC.
 - **Saída interna para ADC**: habilite a conexão para que o ADC leia `VOPAMPx`.
 
 Como o ganho não está explicitado no `.ioc` atual, os cálculos abaixo são apresentados de forma **parametrizada** por `G` (ganho do OPAMP) e por `Vref` (referência do ADC).
 
 ### 4.1) Calibração de offset (recomendado)
 
 Mesmo em medição unidirecional, offsets podem aparecer (offset do OPAMP/ADC, pequenas diferenças de referência e assimetria dos pontos Kelvin).
 
 Sugestão simples:
 
 - com a carga desligada (corrente ~0A), capture `adc_raw_zero` por canal;
 - converta para `Vopamp_out_zero`;
 - use `Vopamp_out_corrigido = Vopamp_out - Vopamp_out_zero` antes de calcular `Vshunt`.
 
 ## 5) Conversão ADC -> tensão
 
 Para um ADC de 12 bits:
 
 - `ADC_FS = 4095`
 
 A tensão equivalente na entrada do ADC (ou seja, na saída do OPAMP) é:
 
 - `Vopamp_out = (adc_raw / 4095) * Vref`
 
 Onde `Vref` normalmente é ~3.3V (dependendo de como `VREF+` está alimentado no hardware).
 
 ## 6) Cálculo da corrente no shunt
 
 ### 6.1) Relação entre Vopamp_out e a queda no shunt
 
 Em uma medição típica de shunt, você quer estimar:
 
 - `Vshunt = V(in) - V(out)`
 
 Se o OPAMP estiver configurado para produzir na saída um sinal proporcional à queda no shunt com ganho `G`:
 
 - `Vopamp_out = G * Vshunt`
 
 então:
 
 - `Vshunt = Vopamp_out / G`
 
 **Observação**: dependendo do modo escolhido no CubeMX (PGA, follower, etc.) pode existir offset/CM. Se você usar offset (ex.: para permitir correntes bidirecionais), ajuste a equação para subtrair o offset antes de dividir por `G`.
 
 ### 6.2) Corrente
 
 A corrente no shunt é:
 
 - `I = Vshunt / Rshunt`
 
 Substituindo:
 
 - `I = (Vopamp_out / G) / Rshunt`
 - `I = Vopamp_out / (G * Rshunt)`
 
 Com `Rshunt` em ohms.
 
 ## 7) Queda de tensão e tensão efetiva do barramento
 
 Uma vez calculada a corrente `I`:
 
 - **queda no shunt**: `Vdrop = I * Rshunt`
 
 Se `Vbus_in` é a tensão antes do shunt e `Vbus_out` é a tensão após o shunt:
 
 - `Vbus_out = Vbus_in - Vdrop`
 
 Se você considera o barramento nominal como 3.3V/5V/12V e quer estimar a tensão efetiva disponível **depois** do shunt:
 
 - `Vbus_eff_3v3 = 3.3 - Vdrop_3v3`
 - `Vbus_eff_5v  = 5.0 - Vdrop_5v`
 - `Vbus_eff_12v = 12.0 - Vdrop_12v`
 
 Isso é especialmente útil para avaliar perda por consumo elevado.
 
 ## 8) Exemplo numérico (didático)
 
 Suponha:
 
 - `Vref = 3.3 V`
 - `G = 16` (exemplo de ganho)
 - `Rshunt = 5 mΩ = 0.005 Ω` (exemplo)
 - `adc_raw = 620`
 
 1) Tensão na saída do OPAMP:
 
 - `Vopamp_out = (620/4095) * 3.3 ≈ 0.499 V`
 
 2) Queda no shunt:
 
 - `Vshunt = 0.499 / 16 ≈ 0.0312 V`
 
 3) Corrente:
 
 - `I = 0.0312 / 0.005 ≈ 6.24 A`
 
 4) Queda e tensão efetiva (por exemplo no barramento 5V):
 
 - `Vdrop = 6.24 * 0.005 ≈ 0.0312 V`
 - `Vbus_eff = 5.0 - 0.0312 ≈ 4.969 V`
 
 ## 9) Implementação sugerida (estrutura do algoritmo)
 
 Para cada barramento (3.3V, 5V, 12V), faça:
 
 - ler `adc_raw` do ADC correspondente (`ADC1/ADC2/ADC3`);
 - converter para `Vopamp_out`;
 - converter para `Vshunt` dividindo por `G` (e removendo offset, se existir);
 - converter para `I` dividindo por `Rshunt`;
 - calcular `Vdrop = I * Rshunt`;
 - calcular `Vbus_eff = Vbus_nominal - Vdrop`.
 
 Parâmetros que devem ser definidos no firmware:
 
 - `Vref` (em volts)
 - `G1`, `G2`, `G3` (ganhos dos OPAMPs)
 - `Rshunt_3v3`, `Rshunt_5v`, `Rshunt_12v` (ohms)
 
 ## 10) Referência de vídeo
 
 https://www.youtube.com/watch?v=kzecsy9Qnhc

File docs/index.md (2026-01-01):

---
layout: page
title: "Kit Educacional e Prototipação Rapport"
subtitle: "KEPR — Kit Educacional e de Prototipação da Rapport"
---

## Visão geral

Este repositório contém o projeto do **Kit Educacional e de Prototipação** da Rapport (Kit Educacional e Prototipação Rapport - KEPR), incluindo a documentação do barramento/modularidade (UCE) e os arquivos de CAD eletrônico em KiCad.

O KEPR é um ecossistema de hardware para **prototipação e aprendizagem** em sistemas embarcados e IoT: uma base modular que permite trocar o microcontrolador sem “quebrar” o restante do projeto, além de integrar **módulos de rede e wireless** (WiFi, Bluetooth e outros) quando essas interfaces não estão disponíveis nativamente no módulo principal.

A proposta é reduzir atrito no desenvolvimento (e no estudo) de firmware e hardware, organizando um padrão de conexão e expansão para acelerar testes, validações e iterações. O projeto busca compatibilidade com famílias como **STM32**, **ESP32**, **AVR (ATtiny/ATmega)** e outros fabricantes.

Este projeto nasce inicialmente com fins **educacionais** (estudos e evolução técnica de Carlos Delfino) e **pode vir a se tornar comercial** no futuro. Ainda assim, o projeto permanece sob a mesma licença para que outras pessoas e empresas possam **usar, adaptar e redistribuir** da forma que desejarem.

<div class="grid">
  <div class="card">
    <h3>Publicações</h3>
    <p>Notas e publicações relacionadas ao projeto KEPR.</p>
    <a class="btn" href="{{ "/publicacoes/" | relative_url }}">Ver publicações</a>
  </div>
  <div class="card">
    <h3>Documentação</h3>
    <p>Links rápidos para documentos principais do repositório.</p>
    <a class="btn" href="{{ "/sobre/" | relative_url }}">Ver documentação</a>
  </div>
  <div class="card">
    <h3>Licença</h3>
    <p>Projeto licenciado sob Creative Commons CC BY 4.0 (atribuição).</p>
    <a class="btn" href="{{ "/licenca/" | relative_url }}">Ver licença</a>
  </div>
</div>

## Documentação (no repositório)

- **UCE (placa / barramento):** [`UCE_BOARD.md`](https://github.com/RapportTecnologia/kit-de-prototipacao-educacional-e-engenharia/blob/main/UCE_BOARD.md)
- **Changelog:** [`CHANGELOG.md`](https://github.com/RapportTecnologia/kit-de-prototipacao-educacional-e-engenharia/blob/main/CHANGELOG.md)

## Projeto KiCad

O projeto principal atualmente está em:

- [`kicad/KEPR/`](https://github.com/RapportTecnologia/kit-de-prototipacao-educacional-e-engenharia/tree/main/kicad/KEPR)

## Repositório Git (origem)

- [git@github.com:RapportTecnologia/kit-de-prototipacao-educacional-e-engenharia.git](https://github.com/RapportTecnologia/kit-de-prototipacao-educacional-e-engenharia)

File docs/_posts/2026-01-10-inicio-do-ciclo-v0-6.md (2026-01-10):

---
layout: post
title: "Início do ciclo de trabalho v0.6"
date: 2026-01-10 14:15:00 -0300
categories: ["Publicações"]
tags: ["KEPR", "Release", "v0.6"]
description: "Abrimos o ciclo de trabalho da versão v0.6 do KEPR (versão liberada = versão em desenvolvimento)."
---

# Início do ciclo de trabalho v0.6

A partir de agora, o projeto entra oficialmente no ciclo de desenvolvimento da **versão v0.6**.

Nossa política de versão é simples:

- a **versão liberada** é também a **versão em que estamos trabalhando**.
- ou seja, a branch principal passa a refletir o estado atual de trabalho da **v0.6**.

## O que marca o início da v0.6

Conforme definido na tag `v0.6`, este ciclo inicia com:

- Iniciado o trabalho na Versão 0.6.
- Adotado novos conversores de tensão e sensores de corrente.
- Desativado no firmware o uso dos OpAmps e reconfiguração dos ADCs.

## Escopo de trabalho previsto para a v0.6

Além do marco inicial acima, nesta versão iremos aprofundar alguns pontos estruturais do hardware, com foco em robustez elétrica, expansão e padronização:

- Evoluir em mais detalhes o **conector principal do UCE**, adicionando **novos sinais** a serem compartilhados.
- Estudar a adoção de **PCB multilayer** (se já faz sentido adotar nesta fase).
- Estudar **impedância**, **vias** e conceitos relacionados (ex.: caminhos críticos, retorno de corrente, integridade de sinal).
- Estudar o **nivelamento/conversão de nível de sinais** entre o **conector principal do UCE** e o **conector de externalização**.
- Revisar e consolidar a **disponibilidade de tensões para uso externo**, tanto no conjunto de conectores de uso externo quanto no **conector UCE**.
- Adicionar o **circuito de clock** do microcontrolador de controle da UCE.

## Atualizações no repositório

Este marco também inclui a atualização da revisão nos arquivos do KiCad (schematics/projeto/pcb) e a sincronização da documentação para refletir a nova versão.

Para acompanhar as mudanças:

- Consulte o `CHANGELOG.md` no repositório
- Navegue pelos esquemáticos e PCB em `kicad/KEPR/`

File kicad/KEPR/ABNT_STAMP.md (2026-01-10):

# Manual do Carimbo NBR 6492 - Kit Educacional Rapport

Este documento explica como preencher os campos da tela **Configurações da página** do KiCad para que as informações apareçam corretamente no carimbo conforme a norma **NBR 6492**.

---

## Seleção do Template

Na seção **Folha de desenho**, no campo **Arquivo**, selecione um dos templates:

| Template | Uso |
|---|-----|
| `rapport_abnt_with_logo.kicad_wks` | Com logotipo da empresa |
| `rapport_abnt_without_logo.kicad_wks` | Sem logotipo |

---

## Mapeamento dos Campos

A tabela abaixo mostra como cada campo do KiCad é exibido no carimbo NBR 6492:

| Campo KiCad | Campo no Carimbo | Descrição | Exemplo |
|---|---|---|---|
| **Título** | PROJETO | Nome do projeto | `KEPR` |
| **Empresa** | EMPRESA | Nome da empresa responsável | `Rapport Tecnologia` |
| **Revisão** | REVISÃO | Número da revisão atual | `0.6` |
| **Data de Emissão** | DATA | Data de emissão do desenho | `2025-12-31` |
| **Comentário1** | Endereço da Empresa | Endereço, CNPJ e telefone | `Rua Example, 123 - CNPJ: 00.000.000/0001-00` |
| **Comentário2** | CLIENTE | Nome do cliente/contratante | `Cliente XYZ Ltda` |
| **Comentário3** | CONTEÚDO | Descrição do conteúdo da prancha | `Esquemático Principal - Fonte de Alimentação` |
| **Comentário4** | LOCAL | Cidade/Local do projeto | `São Paulo - SP` |
| **Comentário5** | ESCALA | Escala do desenho | `1:1` ou `N/A` |
| **Comentário6** | DESENHO | Nome do desenhista | `João Silva` |
| **Comentário7** | VERIFICAÇÃO | Nome do verificador | `Maria Santos` |
| **Comentário8** | APROVAÇÃO | Nome do aprovador | `Carlos Oliveira` |
| **Comentário9** | (Reservado) | Uso futuro | - |

---

## Campos Automáticos

Os seguintes campos são preenchidos automaticamente pelo KiCad:

| Campo no Carimbo | Origem | Descrição |
|---|---|---|
| **PRANCHA** | Sistema | Número da folha atual / Total de folhas (ex: `1/7`) |
| **FORMATO** | Configuração de papel | Formato do papel selecionado (ex: `A3`, `A4`) |
| **Nome do arquivo** | Sistema | Nome do arquivo `.kicad_sch` ou `.kicad_pcb` |

---

## Estrutura Visual do Carimbo

```
┌─────────────────────────────────────────────────────────────────────────────┐
│ EMPRESA:                                                                     │
│ [Empresa]                                                                    │
│ [Comentário1 - Endereço, CNPJ, Telefone]                                    │
├─────────────────────────────────────────────────────────────────────────────┤
│ CLIENTE:                                                                     │
│ [Comentário2]                                                                │
├─────────────────────────────────────────────────────────────────────────────┤
│ PROJETO:                                                                     │
│ [Título]                                                                     │
├─────────────────────────────────────────────────────────────────────────────┤
│ CONTEÚDO:                                                                    │
│ [Comentário3]                                                                │
├───────────────┬───────────────┬─────────────┬─────────────┬─────────────────┤
│ LOCAL:        │ DATA:         │ ESCALA:     │ PRANCHA:    │ REVISÃO:        │
│ [Comentário4] │ [Data Emissão]│ [Coment.5]  │ [Auto]      │ [Revisão]       │
├───────────────┼───────────────┼─────────────┼─────────────┴─────────────────┤
│ DESENHO:      │ VERIFICAÇÃO:  │ APROVAÇÃO:  │ FORMATO:                      │
│ [Comentário6] │ [Comentário7] │ [Coment.8]  │ [Auto] / [Nome arquivo]       │
└───────────────┴───────────────┴─────────────┴───────────────────────────────┘
```

---

## Passo a Passo

1. **Abra o projeto** no KiCad (Esquemático ou PCB)

2. **Acesse as configurações de página:**
   - Menu: `Arquivo` → `Configurações da página`
   - Ou pressione o atalho correspondente

3. **Selecione o template:**
   - Em **Arquivo**, clique no ícone de pasta
   - Navegue até a pasta `kicad/KEPR/`
   - Selecione `rapport_abnt_with_logo.kicad_wks` ou `rapport_abnt_without_logo.kicad_wks`

4. **Preencha os campos obrigatórios:**
   - **Título:** Nome do projeto
   - **Empresa:** Nome da sua empresa
   - **Revisão:** Versão atual (ex: `1.0`, `Rev.A`)
   - **Data de Emissão:** Data do desenho

5. **Preencha os campos de comentário** conforme a tabela de mapeamento acima

6. **Marque "Copie nas outras folhas"** para os campos que devem se repetir em todas as páginas

7. Clique em **OK** para aplicar

---

## Dicas

- **Comentário1** é ideal para informações complementares da empresa (endereço, CNPJ, telefone, registro CREA/CAU)
- **Comentário3** deve descrever especificamente o que está representado naquela prancha
- Para projetos eletrônicos, **Escala** geralmente é `1:1` ou `N/A`
- Use **Copie nas outras folhas** para campos que são iguais em todo o projeto (empresa, cliente, projeto)
- Campos como **CONTEÚDO** e **PRANCHA** geralmente variam entre folhas

---

## Dimensões do Carimbo

O carimbo segue as especificações da NBR 6492:
- **Largura:** 175 mm
- **Altura:** 55 mm
- **Posição:** Canto inferior direito da folha

---

## Referências

- **NBR 6492** - Representação de projetos de arquitetura
- **NBR 10068** - Folha de desenho - Leiaute e dimensões
- **NBR 10582** - Apresentação da folha para desenho técnico

---

*Template desenvolvido para o Kit Educacional e Prototipação Rapport*

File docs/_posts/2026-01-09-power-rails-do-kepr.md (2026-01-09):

---
layout: post
title: "Alimentação (POWER) e Power Rails do KEPR"
date: 2026-01-09 09:00:00 -0300
categories: ["Tutoriais"]
tags: ["KEPR", "Power", "Alimentação", "Power Rails", "3.3V", "5V", "12V", "24V"]
description: "Visão geral dos power rails do KEPR: +24V, +12V, +5V e +3.3V, como são distribuídos e boas práticas de uso externo."
keywords: ["KEPR", "power rails", "alimentação", "barramentos", "24V", "12V", "5V", "3.3V", "shunt", "segurança elétrica"]
---

# Alimentação (POWER) e Power Rails do KEPR

## Referências

- https://wiki.st.com/stm32mcu/wiki/Basics_of_power_supply_design_for_MCU

## O que são “Power Rails” no KEPR

No KEPR, “Power Rails” são os **barramentos de tensão** distribuídos por toda a placa.
Eles têm duas funções principais:

- **Alimentar os circuitos internos** (microcontrolador, periféricos e blocos de interface).
- **Serem externalizados para o usuário (aluno)**, permitindo alimentar circuitos externos (protoboard, módulos, sensores) com tensões padronizadas.

Esses rails são gerados a partir de **conversores DC-DC chaveados**, o que permite boa eficiência e disponibilidade de diferentes níveis de tensão.

## Rails principais

### Entrada: `+24V`

- **Papel no sistema:** barramento de entrada/primário.
- **Origem:** alimentação externa (entrada de energia do kit).
- **Uso:** serve como “fonte base” para os conversores que geram as demais tensões.

### Rail: `+12V`

- **Papel no sistema:** barramento para cargas e experimentos que necessitam de 12 V.
- **Origem:** gerado por conversão a partir do rail de entrada.
- **Uso:** pode alimentar circuitos internos específicos e também é disponibilizado externamente.

### Rail: `+5V`

- **Papel no sistema:** barramento de uso geral para periféricos, módulos e experimentos.
- **Origem:** gerado por conversor DC-DC.
- **Uso:** distribuição interna e disponibilização ao aluno para protótipos e módulos 5 V.

### Rail: `+3.3V`

- **Papel no sistema:** principal barramento lógico do sistema (MCU e sensores digitais).
- **Origem:** gerado por conversor DC-DC.
- **Uso:** distribuição interna e disponibilização ao aluno para circuitos 3,3 V.

## Instrumentação (Shunt) e controle de rails

Em alguns pontos do projeto aparecem nets do tipo:

- `+3v3 Shunt` / `+3.3v Shunt Out`
- `+5v Shunt` / `+5v Shunt Out`
- `+12v Shunt`

A ideia é que o rail passe por um **shunt (resistor de baixa resistência)** para permitir **medição/monitoramento de corrente** (didático e útil para diagnóstico).
Em termos práticos:

- **`<rail> Shunt`**: lado “antes” do shunt.
- **`<rail> Shunt Out`**: lado “depois” do shunt, já pronto para distribuição.

## Como o aluno usa os Power Rails externamente

O KEPR disponibiliza os rails em conectores/headers no conjunto de “External Power Rails”, tipicamente incluindo:

- `GND` (referência comum)
- `+3.3V`
- `+5V`
- `+12V`

Assim, o aluno pode:

- Alimentar protoboard e módulos diretamente com `+3.3V` ou `+5V`.
- Usar `+12V` quando o experimento exigir (motores/atuadores específicos, drivers, etc.).
- Sempre compartilhar o **mesmo `GND`** entre o KEPR e o circuito externo.

## Boas práticas e segurança

- **Verifique polaridade antes de ligar.** Inversão de polaridade pode danificar conversores e periféricos.
- **Use sempre `GND` comum.** Sinais lógicos e medição só funcionam corretamente com referência comum.
- **Não misture níveis de tensão em GPIO.**
  - GPIOs do MCU são tipicamente `3.3V`.
  - Não aplique `5V` diretamente em pinos do MCU (use conversão de nível quando necessário).
- **Cuidado com curto-circuito.** Um curto em `+5V`/`+3.3V` pode derrubar o rail e aquecer componentes.
- **Não exceda a capacidade de corrente dos rails.** Se o experimento exigir mais corrente (motores grandes, cargas resistivas), use fonte dedicada e apenas compartilhe `GND`.

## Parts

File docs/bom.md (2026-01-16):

---
title: "BOM"
permalink: /bom/
---

<div class="callout">
  <h1>Bill of Materials (BOM)</h1>
  <p>Esta lista BOM é gerada automaticamente pelo CI a partir do projeto KiCad.</p>
</div>

<div class="table-wrap">
<table>
<thead><tr>
<th>Refs</th>
<th>Value</th>
<th>Footprint</th>
<th>Qty</th>
<th>DNP</th>
</tr></thead>
<tbody>
<tr>
<td>KEPR:C5</td>
<td>0.1nF_Ceramic</td>
<td>Capacitor:C_0805_2012Metric</td>
<td>1</td>
<td></td>
</tr>
<tr>
<td>KEPR:J11</td>
<td>10141995-005RLF</td>
<td>Connector_PCBEdge:SODIMM-260_DDR4_H4.0-5.2_OrientationStd_Socket</td>
<td>1</td>
<td></td>
</tr>
<tr>
<td>MCU_Board_STM32N6:J2</td>
<td>10141995-005RLF</td>
<td>SODIMM DDR4 EDGE 260 pins:SODIMM_DDR4_EDGE</td>
<td>1</td>
<td></td>
</tr>
<tr>
<td>KEPR:C1;KEPR:C2;KEPR:C3;KEPR:C4</td>
<td>4.7nF_Ceramic</td>
<td>Capacitor:C_0805_2012Metric</td>
<td>4</td>
<td></td>
</tr>
<tr>
<td>KEPR:IC1;KEPR:IC2;KEPR:IC3</td>
<td>ACS37041KLHBLT-010B3</td>
<td>APS12628LLHALTBAP</td>
<td>3</td>
<td></td>
</tr>
<tr>
<td>KEPR:U4</td>
<td>AMS1117-1.8</td>
<td>Package_TO_SOT_SMD:SOT-223-3_TabPin2</td>
<td>1</td>
<td></td>
</tr>
<tr>
<td>KEPR:U3</td>
<td>AMS1117-3.3</td>
<td>Package_TO_SOT_SMD:SOT-223-3_TabPin2</td>
<td>1</td>
<td></td>
</tr>
<tr>
<td>KEPR:J22</td>
<td>Barrel_Jack</td>
<td>Barrel Jack:BarrelJack_Horizontal</td>
<td>1</td>
<td></td>
</tr>
<tr>
<td>KEPR:BT1</td>
<td>Battery_Cell</td>
<td>Battery:BatteryHolder_Multicomp_BC-2001_1x2032</td>
<td>1</td>
<td></td>
</tr>
<tr>
<td>KEPR:J8</td>
<td>Conn_01x08_Pin</td>
<td>Connector_PinHeader_2.00mm:PinHeader_1x08_P2.00mm_Vertical</td>
<td>1</td>
<td></td>
</tr>
<tr>
<td>KEPR:J5</td>
<td>Conn_02x08_Odd_Even</td>
<td>Connector_IDC:IDC-Header_2x08_P2.54mm_Latch12.0mm_Vertical</td>
<td>1</td>
<td></td>
</tr>
<tr>
<td>KEPR:J7</td>
<td>Conn_02x08_Odd_Even</td>
<td>Connector_PinHeader_2.00mm:PinHeader_2x08_P2.00mm_Vertical</td>
<td>1</td>
<td></td>
</tr>
<tr>
<td>KEPR:J3</td>
<td>Conn_02x12_Odd_Even</td>
<td>Connector_IDC:IDC-Header_2x12_P2.54mm_Latch9.5mm_Vertical</td>
<td>1</td>
<td></td>
</tr>
<tr>
<td>KEPR:J4</td>
<td>Conn_02x15_Odd_Even</td>
<td>Connector_IDC:IDC-Header_2x15-1MP_P2.54mm_Latch_Vertical</td>
<td>1</td>
<td></td>
</tr>
<tr>
<td>KEPR:J6</td>
<td>Conn_02x20_Odd_Even</td>
<td>Connector_PinHeader_2.54mm:PinHeader_2x20_P2.54mm_Vertical</td>
<td>1</td>
<td></td>
</tr>
<tr>
<td>KEPR:J9;KEPR:J10</td>
<td>Conn_02x40_Odd_Even</td>
<td>Connector_PinHeader_2.54mm:PinHeader_2x40_P2.54mm_Vertical</td>
<td>2</td>
<td></td>
</tr>
<tr>
<td>KEPR:J16;KEPR:J23</td>
<td>PINHD_1x10_Male</td>
<td>Connector_PinHeader_2.54mm:PinHeader_1x10_P2.54mm_Vertical</td>
<td>2</td>
<td></td>
</tr>
<tr>
<td>KEPR:J1;KEPR:J12;KEPR:J17;KEPR:J19</td>
<td>PINHD_1x20_Male</td>
<td>Connector_PinHeader_2.54mm:PinHeader_1x20_P2.54mm_Vertical</td>
<td>4</td>
<td></td>
</tr>
<tr>
<td>KEPR:J13;KEPR:J24;KEPR:J30</td>
<td>PINHD_2x2_Male</td>
<td>Connector_PinHeader_2.54mm:PinHeader_2x02_P2.54mm_Vertical</td>
<td>3</td>
<td></td>
</tr>
<tr>
<td>KEPR:J26</td>
<td>PINHD_2x3_Male</td>
<td>Connector_PinHeader_2.54mm:PinHeader_2x03_P2.54mm_Vertical</td>
<td>1</td>
<td></td>
</tr>
<tr>
<td>KEPR:U1</td>
<td>REF193</td>
<td>REF193:SOIC127P600X175-8N</td>
<td>1</td>
<td></td>
</tr>
<tr>
<td>KEPR:Brd1</td>
<td>SSD1306</td>
<td>SSD1306:128x64OLED</td>
<td>1</td>
<td></td>
</tr>
<tr>
<td>KEPR:U2</td>
<td>STM32G484CETx</td>
<td>Package_QFP:LQFP-48_7x7mm_P0.5mm</td>
<td>1</td>
<td></td>
</tr>
<tr>
<td>KEPR:PS1</td>
<td>TDN5-2410WISM</td>
<td>TDN 5WISM Series, 5 Watt:CONV_TDN5-2411WISM</td>
<td>1</td>
<td></td>
</tr>
<tr>
<td>KEPR:PS2</td>
<td>TDN5-2411WISM</td>
<td>TDN 5WISM Series, 5 Watt:CONV_TDN5-2411WISM</td>
<td>1</td>
<td></td>
</tr>
<tr>
<td>KEPR:PS3</td>
<td>TDN_5-2412WISM</td>
<td>TDN 5WISM Series, 5 Watt:CONV_TDN5-2411WISM</td>
<td>1</td>
<td></td>
</tr>
</tbody>
</table>
</div>

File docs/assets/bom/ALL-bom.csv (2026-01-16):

Refs | Value | Footprint | Qty | DNP
KEPR:C5 | 0.1nF_Ceramic | Capacitor:C_0805_2012Metric | 1
KEPR:J11 | 10141995-005RLF | Connector_PCBEdge:SODIMM-260_DDR4_H4.0-5.2_OrientationStd_Socket | 1
MCU_Board_STM32N6:J2 | 10141995-005RLF | SODIMM DDR4 EDGE 260 pins:SODIMM_DDR4_EDGE | 1
KEPR:C1;KEPR:C2;KEPR:C3;KEPR:C4 | 4.7nF_Ceramic | Capacitor:C_0805_2012Metric | 4
KEPR:IC1;KEPR:IC2;KEPR:IC3 | ACS37041KLHBLT-010B3 | APS12628LLHALTBAP | 3
KEPR:U4 | AMS1117-1.8 | Package_TO_SOT_SMD:SOT-223-3_TabPin2 | 1
KEPR:U3 | AMS1117-3.3 | Package_TO_SOT_SMD:SOT-223-3_TabPin2 | 1
KEPR:J22 | Barrel_Jack | Barrel Jack:BarrelJack_Horizontal | 1
KEPR:BT1 | Battery_Cell | Battery:BatteryHolder_Multicomp_BC-2001_1x2032 | 1
KEPR:J8 | Conn_01x08_Pin | Connector_PinHeader_2.00mm:PinHeader_1x08_P2.00mm_Vertical | 1
KEPR:J5 | Conn_02x08_Odd_Even | Connector_IDC:IDC-Header_2x08_P2.54mm_Latch12.0mm_Vertical | 1
KEPR:J7 | Conn_02x08_Odd_Even | Connector_PinHeader_2.00mm:PinHeader_2x08_P2.00mm_Vertical | 1
KEPR:J3 | Conn_02x12_Odd_Even | Connector_IDC:IDC-Header_2x12_P2.54mm_Latch9.5mm_Vertical | 1
KEPR:J4 | Conn_02x15_Odd_Even | Connector_IDC:IDC-Header_2x15-1MP_P2.54mm_Latch_Vertical | 1
KEPR:J6 | Conn_02x20_Odd_Even | Connector_PinHeader_2.54mm:PinHeader_2x20_P2.54mm_Vertical | 1
KEPR:J9;KEPR:J10 | Conn_02x40_Odd_Even | Connector_PinHeader_2.54mm:PinHeader_2x40_P2.54mm_Vertical | 2
KEPR:J16;KEPR:J23 | PINHD_1x10_Male | Connector_PinHeader_2.54mm:PinHeader_1x10_P2.54mm_Vertical | 2
KEPR:J1;KEPR:J12;KEPR:J17;KEPR:J19 | PINHD_1x20_Male | Connector_PinHeader_2.54mm:PinHeader_1x20_P2.54mm_Vertical | 4
KEPR:J13;KEPR:J24;KEPR:J30 | PINHD_2x2_Male | Connector_PinHeader_2.54mm:PinHeader_2x02_P2.54mm_Vertical | 3
KEPR:J26 | PINHD_2x3_Male | Connector_PinHeader_2.54mm:PinHeader_2x03_P2.54mm_Vertical | 1
KEPR:U1 | REF193 | REF193:SOIC127P600X175-8N | 1
KEPR:Brd1 | SSD1306 | SSD1306:128x64OLED | 1
KEPR:U2 | STM32G484CETx | Package_QFP:LQFP-48_7x7mm_P0.5mm | 1
KEPR:PS1 | TDN5-2410WISM | TDN 5WISM Series, 5 Watt:CONV_TDN5-2411WISM | 1
KEPR:PS2 | TDN5-2411WISM | TDN 5WISM Series, 5 Watt:CONV_TDN5-2411WISM | 1
KEPR:PS3 | TDN_5-2412WISM | TDN 5WISM Series, 5 Watt:CONV_TDN5-2411WISM | 1

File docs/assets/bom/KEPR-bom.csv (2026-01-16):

Refs | Value | Footprint | Qty | DNP
Brd1 | SSD1306 | SSD1306:128x64OLED | 1
BT1 | Battery_Cell | Battery:BatteryHolder_Multicomp_BC-2001_1x2032 | 1
C1 | 4.7nF_Ceramic | Capacitor:C_0805_2012Metric | 1
C2 | 4.7nF_Ceramic | Capacitor:C_0805_2012Metric | 1
C3 | 4.7nF_Ceramic | Capacitor:C_0805_2012Metric | 1
C4 | 4.7nF_Ceramic | Capacitor:C_0805_2012Metric | 1
C5 | 0.1nF_Ceramic | Capacitor:C_0805_2012Metric | 1
IC1 | ACS37041KLHBLT-010B3 | APS12628LLHALTBAP | 1
IC2 | ACS37041KLHBLT-010B3 | APS12628LLHALTBAP | 1
IC3 | ACS37041KLHBLT-010B3 | APS12628LLHALTBAP | 1
J1 | PINHD_1x20_Male | Connector_PinHeader_2.54mm:PinHeader_1x20_P2.54mm_Vertical | 1
J3 | Conn_02x12_Odd_Even | Connector_IDC:IDC-Header_2x12_P2.54mm_Latch9.5mm_Vertical | 1
J4 | Conn_02x15_Odd_Even | Connector_IDC:IDC-Header_2x15-1MP_P2.54mm_Latch_Vertical | 1
J5 | Conn_02x08_Odd_Even | Connector_IDC:IDC-Header_2x08_P2.54mm_Latch12.0mm_Vertical | 1
J6 | Conn_02x20_Odd_Even | Connector_PinHeader_2.54mm:PinHeader_2x20_P2.54mm_Vertical | 1
J7 | Conn_02x08_Odd_Even | Connector_PinHeader_2.00mm:PinHeader_2x08_P2.00mm_Vertical | 1
J8 | Conn_01x08_Pin | Connector_PinHeader_2.00mm:PinHeader_1x08_P2.00mm_Vertical | 1
J9 | Conn_02x40_Odd_Even | Connector_PinHeader_2.54mm:PinHeader_2x40_P2.54mm_Vertical | 1
J10 | Conn_02x40_Odd_Even | Connector_PinHeader_2.54mm:PinHeader_2x40_P2.54mm_Vertical | 1
J11 | 10141995-005RLF | Connector_PCBEdge:SODIMM-260_DDR4_H4.0-5.2_OrientationStd_Socket | 1
J12 | PINHD_1x20_Male | Connector_PinHeader_2.54mm:PinHeader_1x20_P2.54mm_Vertical | 1
J13 | PINHD_2x2_Male | Connector_PinHeader_2.54mm:PinHeader_2x02_P2.54mm_Vertical | 1
J16 | PINHD_1x10_Male | Connector_PinHeader_2.54mm:PinHeader_1x10_P2.54mm_Vertical | 1
J17 | PINHD_1x20_Male | Connector_PinHeader_2.54mm:PinHeader_1x20_P2.54mm_Vertical | 1
J19 | PINHD_1x20_Male | Connector_PinHeader_2.54mm:PinHeader_1x20_P2.54mm_Vertical | 1
J22 | Barrel_Jack | Barrel Jack:BarrelJack_Horizontal | 1
J23 | PINHD_1x10_Male | Connector_PinHeader_2.54mm:PinHeader_1x10_P2.54mm_Vertical | 1
J24 | PINHD_2x2_Male | Connector_PinHeader_2.54mm:PinHeader_2x02_P2.54mm_Vertical | 1
J26 | PINHD_2x3_Male | Connector_PinHeader_2.54mm:PinHeader_2x03_P2.54mm_Vertical | 1
J30 | PINHD_2x2_Male | Connector_PinHeader_2.54mm:PinHeader_2x02_P2.54mm_Vertical | 1
PS1 | TDN5-2410WISM | TDN 5WISM Series, 5 Watt:CONV_TDN5-2411WISM | 1
PS2 | TDN5-2411WISM | TDN 5WISM Series, 5 Watt:CONV_TDN5-2411WISM | 1
PS3 | TDN_5-2412WISM | TDN 5WISM Series, 5 Watt:CONV_TDN5-2411WISM | 1
U1 | REF193 | REF193:SOIC127P600X175-8N | 1
U2 | STM32G484CETx | Package_QFP:LQFP-48_7x7mm_P0.5mm | 1
U3 | AMS1117-3.3 | Package_TO_SOT_SMD:SOT-223-3_TabPin2 | 1
U4 | AMS1117-1.8 | Package_TO_SOT_SMD:SOT-223-3_TabPin2 | 1

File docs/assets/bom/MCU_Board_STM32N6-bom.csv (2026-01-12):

Refs | Value | Footprint | Qty | DNP
J2 | 10141995-005RLF | SODIMM DDR4 EDGE 260 pins:SODIMM_DDR4_EDGE | 1

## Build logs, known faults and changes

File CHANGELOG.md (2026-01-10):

# Changelog

## 0.6

* Iniciado o trabalho na Versão 0.6.
* Adotado novos conversores de tensão e sensores de corrente.
* Desativado no firmware o uso dos OpAmps e reconfiguração dos ADCs.
* Em andamento: detalhamento do conector principal do UCE, com adição de novos sinais a serem compartilhados.
* Em andamento: estudo sobre adoção de PCB multilayer.
* Em andamento: estudo sobre impedância, vias e conceitos relacionados (integridade de sinal, retorno de corrente, etc.).
* Em andamento: estudo sobre nivelamento/conversão de nível de sinais entre o conector principal do UCE e o conector de externalização.
* Em andamento: revisão da disponibilidade de tensões para uso externo (incluindo no conector UCE).
* Em andamento: adição do circuito de clock do microcontrolador de controle da UCE.

## 0.5

* Organização hierárquica das folhas de esquema, com `KEPR.kicad_sch` como folha raiz e as demais como filhas.
* Ajustado os conectores para barramento de Depuração, Networking e Wireless.
* Criado folha para padronizar as folhas dos esquemas, adicionado uma marca d'agua.
* Criado o Barramento que externaliza os sinais obtidos no barramento do módulo do processador

## 0.4

Reorganização da documentação: a especificação da UCE foi movida para `UCE_BOARD.md` e o `README.md` passou a apresentar o projeto e pontos de entrada. Adição de badges (licença CC-BY-4.0, visitas, KiCad, issues, stars e forks) e atualização das referências do repositório para `git@github.com:RapportTecnologia/kit-de-prototipacao-educacional-e-engenharia.git`. Atualização da revisão do projeto KiCad `UCE_Bus` para 0.4.

## 0.3

* foi adotado o Windsurf para finalizar o barramento inserindo os pinos de GND e tensões extras, além de pinos reservados para expanção futura.
* Gestão e melhoria da documentação

## 0.2

Nesta versão fizemos uma revisão inserindo os pinos para Debug, ADC/DAC e identificação do módulo através de um eeprom de 2k. Ficando definido um módulo extra para Network e outro para Debug.

## 0.1

primeira versão decidi usar o modelo propriedde, porém aberto a comunidade, usando um conector SO-DIMM de 200 pinos.

## 0.0

conceito debatido no chatgpt, discutimos sobre os padrões de conectores e barramentos entre eles SO-DIMM, SMARC E QSEVEM, Além de outros

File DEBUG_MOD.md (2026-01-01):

# DEBUG_MOD – Módulo de Depuração (Header genérico 2x15)

## 1. Objetivo

O **DEBUG_MOD** é um módulo encaixável na Carrier via **conector header genérico 2x15 (macho)**, com espaçamento maior para facilitar uso com jumpers, cuja função é dar acesso ao **Barramento Universal de Depuração** do UCE.

Ele existe para permitir a troca do “método de debug/programação” (ex.: CMSIS-DAP, J-Link, AVR-ISP/UPDI, bridge USB-UART, etc.) sem alterar a placa base.

## 2. Sinais do Barramento Universal de Depuração (referência)

Conforme o `README.md`, o barramento de depuração do UCE disponibiliza os seguintes sinais lógicos (nomes canônicos):

- `DBG_SWDIO`
- `DBG_SWCLK`
- `DBG_TCK`
- `DBG_TMS`
- `DBG_TDI`
- `DBG_TDO`
- `DBG_RESET_N`
- `DBG_VREF`
- `DBG_UART_TX`
- `DBG_UART_RX`

Além dos sinais auxiliares de presença/tipo de módulo:

- `MOD_PRESENT_N`
- `MOD_TYPE0`
- `MOD_TYPE1`
- `MOD_TYPE2`

E referências elétricas:

- `GND`

### 2.1 Referência de pinagem no conector UCE (SO-DIMM J1)

No conector UCE SO-DIMM 200 pinos (J1), a região de depuração está definida no `README.md` como:

| Pino (Sup) | Sinal | Pino (Inf) | Sinal |
| ---: | --- | ---: | --- |
| 83 | `DBG_SWDIO` | 118 | `DBG_SWCLK` |
| 84 | `DBG_TCK` | 117 | `DBG_TMS` |
| 85 | `DBG_TDI` | 116 | `DBG_TDO` |
| 86 | `DBG_RESET_N` | 115 | `DBG_VREF` |
| 87 | `DBG_UART_TX` | 114 | `DBG_UART_RX` |
| 88 | `MOD_PRESENT_N` | 113 | `MOD_TYPE0` |
| 89 | `MOD_TYPE1` | 112 | `MOD_TYPE2` |

## 3. Convenção de pinagem “bordas → miolo”

Este documento descreve a pinagem do conector do módulo **das bordas para o miolo**, isto é:

- Atribuir primeiro os sinais nos **pinos mais externos** do conector.
- Os pinos que sobrarem na região **central (miolo)** devem ser marcados como **RESERVADO**.

> Observação importante
>
> O projeto KiCad neste repositório atualmente descreve o barramento UCE no conector SO-DIMM (J1). A pinagem abaixo fixa a **distribuição funcional** e o conjunto de sinais do DEBUG_MOD no conector **header genérico 2x15**.

Além disso, em versões futuras haverá um **segundo conector** com passo **0.05"** para compatibilidade ainda maior com padrões de cabos/ICE.

## 4. Pinagem do DEBUG_MOD (Header 2x15)

- Total: **30 vias** (pinos **1..30**)
- Numeração: padrão 2xN (ímpares em uma coluna e pares na outra)

### 4.1 Tabela de pinagem

| Pino | Sinal | Pino | Sinal |
| ---: | --- | ---: | --- |
| 1 | `DBG_VREF` *(VTref)* | 2 | `GND` |
| 3 | `DBG_TMS` *(JTAG TMS / SWDIO)*  | 4 | `GND` |
| 5 | `DBG_TCK` *(JTAG TCK / SWCLK)*  | 6 | `GND` |
| 7 | `DBG_TDO` | 8 | `GND` |
| 9 | `DBG_TDI` | 10 | `GND` |
| 11 | `DBG_RESET_N` *(nRESET)* | 12 | `GND` |
| 13 | `DBG_SWDIO` *(alternativo / uso dedicado quando aplicável)* | 14 | `DBG_SWCLK` *(alternativo / uso dedicado quando aplicável)* |
| 15 | `DBG_UART_TX` | 16 | `DBG_UART_RX` |
| 17 | `MOD_PRESENT_N` | 18 | `MOD_TYPE0` |
| 19 | `MOD_TYPE1` | 20 | `MOD_TYPE2` |
| 21 | `GND` | 22 | `GND` |
| 23 | `RESERVADO` | 24 | `RESERVADO` |
| 25 | `RESERVADO` | 26 | `RESERVADO` |
| 27 | `RESERVADO` | 28 | `RESERVADO` |
| 29 | `GND` | 30 | `GND` |

## 5. Regras elétricas e de integração

- `DBG_VREF` deve ser tratado como **referência do nível lógico** do alvo (MCU Module). O DEBUG_MOD deve **medir** este nível e adaptar seus buffers/transceptores conforme necessário.
- Manter `GND` adjacente aos sinais de clock (ex.: `DBG_SWCLK`, `DBG_TCK`) ajuda no retorno de corrente e integridade de sinal.
- `DBG_RESET_N` é ativo em nível baixo.
- `DBG_UART_TX/RX` são para console/boot/debug e não substituem SWD/JTAG.

## 6. Pontos em aberto

- Definir se o DEBUG_MOD deve receber alimentação exclusivamente por `DBG_VREF` (apenas detecção de nível) ou se também haverá necessidade de `VCC_3V3` dedicado em revisões futuras.

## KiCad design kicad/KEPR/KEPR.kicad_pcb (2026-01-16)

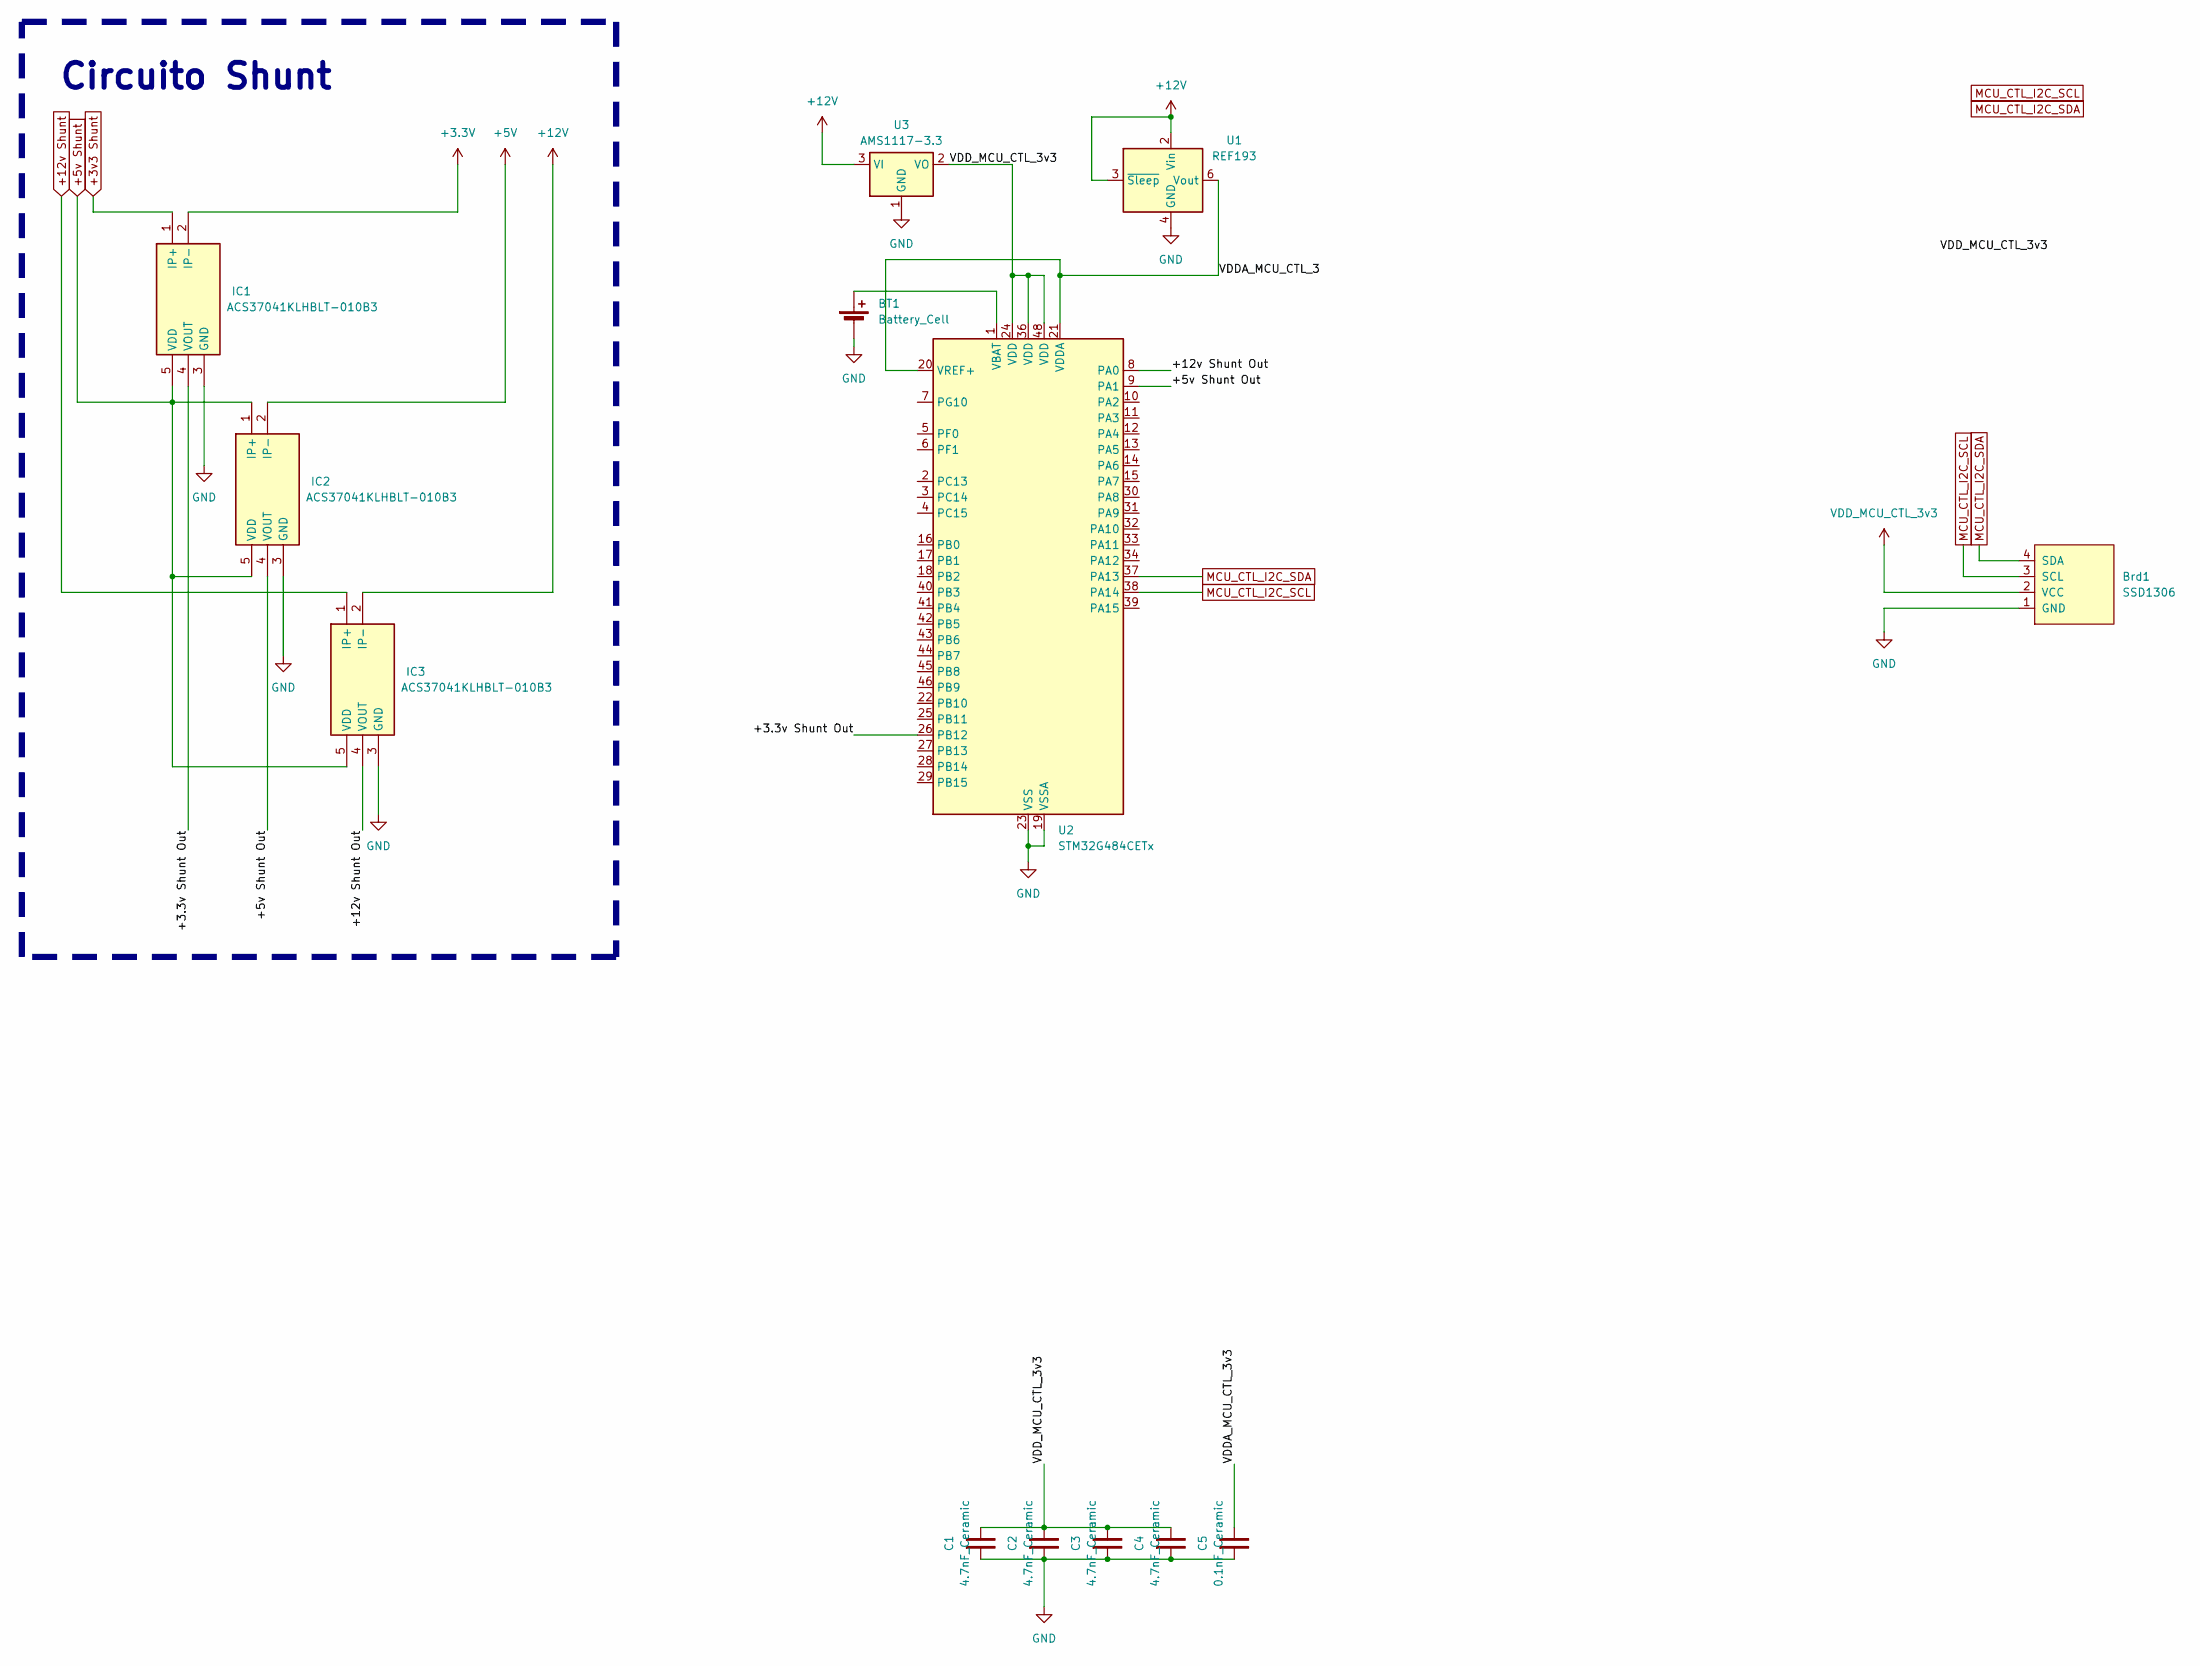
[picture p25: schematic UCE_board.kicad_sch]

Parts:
BT1: Battery_Cell; BatteryHolder_Multicomp_BC-2001_1x2032
Brd1: SSD1306; 128x64OLED
C1, C2, C3, C4: 4.7nF_Ceramic; C_0805_2012Metric
C5: 0.1nF_Ceramic; C_0805_2012Metric
IC1, IC2, IC3: ACS37041KLHBLT-010B3; APS12628LLHALTBAP; Manufacturer_Part_Number ACS37041KLHBLT-010B3
U1: REF193; SOIC127P600X175-8N
U2: STM32G484CETx; LQFP-48_7x7mm_P0.5mm
U3: AMS1117-3.3; SOT-223-3_TabPin2

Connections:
+3.3V: IC1.2 (IP-); also elsewhere on the board
+3v3 Shunt: IC1.1 (IP+); also elsewhere on the board
+5V: IC2.2 (IP-); also elsewhere on the board
+5v Shunt: IC1.5 (VDD), IC2.1 (IP+), IC2.5 (VDD), IC3.5 (VDD); also elsewhere on the board
+12V: IC3.2 (IP-), U1.2 (Vin), U1.3 (~Sleep), U3.3 (VI); also elsewhere on the board
+12v Shunt: IC3.1 (IP+); also elsewhere on the board
/UCE board/+3.3v Shunt Out: IC1.4 (VOUT), U2.26 (PB12)
/UCE board/+5v Shunt Out: IC2.4 (VOUT), U2.9 (PA1)
/UCE board/+12v Shunt Out: IC3.4 (VOUT), U2.8 (PA0)
/UCE board/VDDA_MCU_CTL_3: U1.6 (Vout), U2.20 (VREF+), U2.21 (VDDA)
/UCE board/VDDA_MCU_CTL_3v3: C5.2
GND: BT1.2 (-), Brd1.1 (GND), C1.1, C2.1, C3.1, C4.1, C5.1, IC1.3 (GND), IC2.3 (GND), IC3.3 (GND), U1.4 (GND), U2.19 (VSSA), U2.23 (VSS), U2.35 (VSS), U2.47 (VSS), U3.1 (GND); also elsewhere on the board
MCU_CTL_I2C_SCL: Brd1.3 (SCL), U2.38 (PA14); also elsewhere on the board
MCU_CTL_I2C_SDA: Brd1.4 (SDA), U2.37 (PA13); also elsewhere on the board
unnamed: BT1.1 (+), U2.1 (VBAT)
VDD_MCU_CTL_3v3: Brd1.2 (VCC), C1.2, C2.2, C3.2, C4.2, U2.24 (VDD), U2.36 (VDD), U2.48 (VDD), U3.2 (VO)

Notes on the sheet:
Circuito Shunt

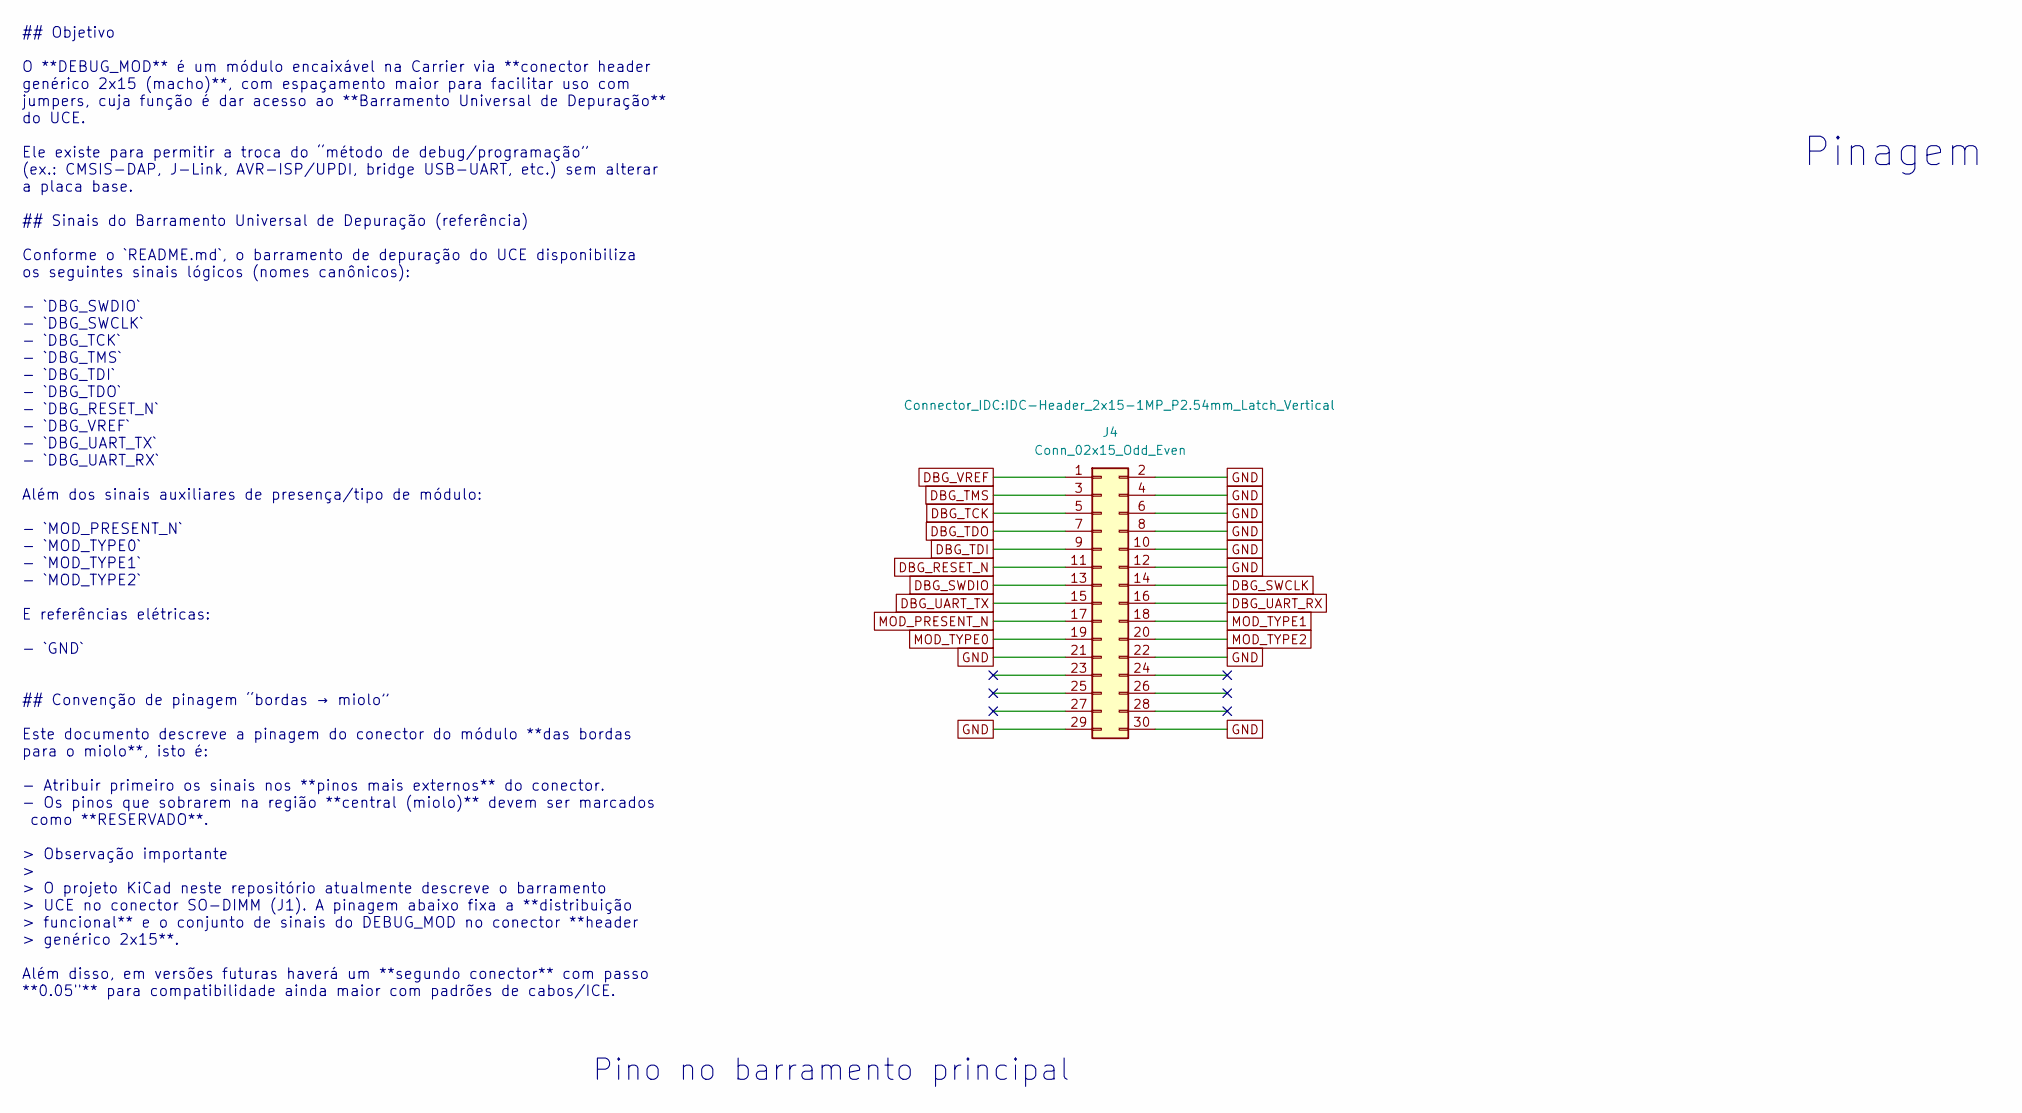
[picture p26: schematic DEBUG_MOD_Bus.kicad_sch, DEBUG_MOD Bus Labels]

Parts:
J4: Conn_02x15_Odd_Even; IDC-Header_2x15-1MP_P2.54mm_Latch_Vertical

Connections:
DBG_RESET_N: J4.11; also elsewhere on the board
DBG_SWCLK: J4.14; also elsewhere on the board
DBG_SWDIO: J4.13; also elsewhere on the board
DBG_TCK: J4.5; also elsewhere on the board
DBG_TDI: J4.9; also elsewhere on the board
DBG_TDO: J4.7; also elsewhere on the board
DBG_TMS: J4.3; also elsewhere on the board
DBG_UART_RX: J4.16; also elsewhere on the board
DBG_UART_TX: J4.15; also elsewhere on the board
DBG_VREF: J4.1; also elsewhere on the board
GND: J4.2, J4.4, J4.6, J4.8, J4.10, J4.12, J4.21, J4.22, J4.29, J4.30; also elsewhere on the board
MOD_PRESENT_N: J4.17; also elsewhere on the board
MOD_TYPE0: J4.19; also elsewhere on the board
MOD_TYPE1: J4.18; also elsewhere on the board
MOD_TYPE2: J4.20; also elsewhere on the board

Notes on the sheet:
Pinagem
Pino no barramento principal
## Objetivo O **DEBUG_MOD** é um módulo encaixável na Carrier via **conector header genérico 2x15 (macho)**, com espaçamento maior para facilitar uso com jumpers, cuja função é dar acesso ao **Barramento Universal de Depuração** do UCE. Ele existe para permitir a troca do “método de debug/programaç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

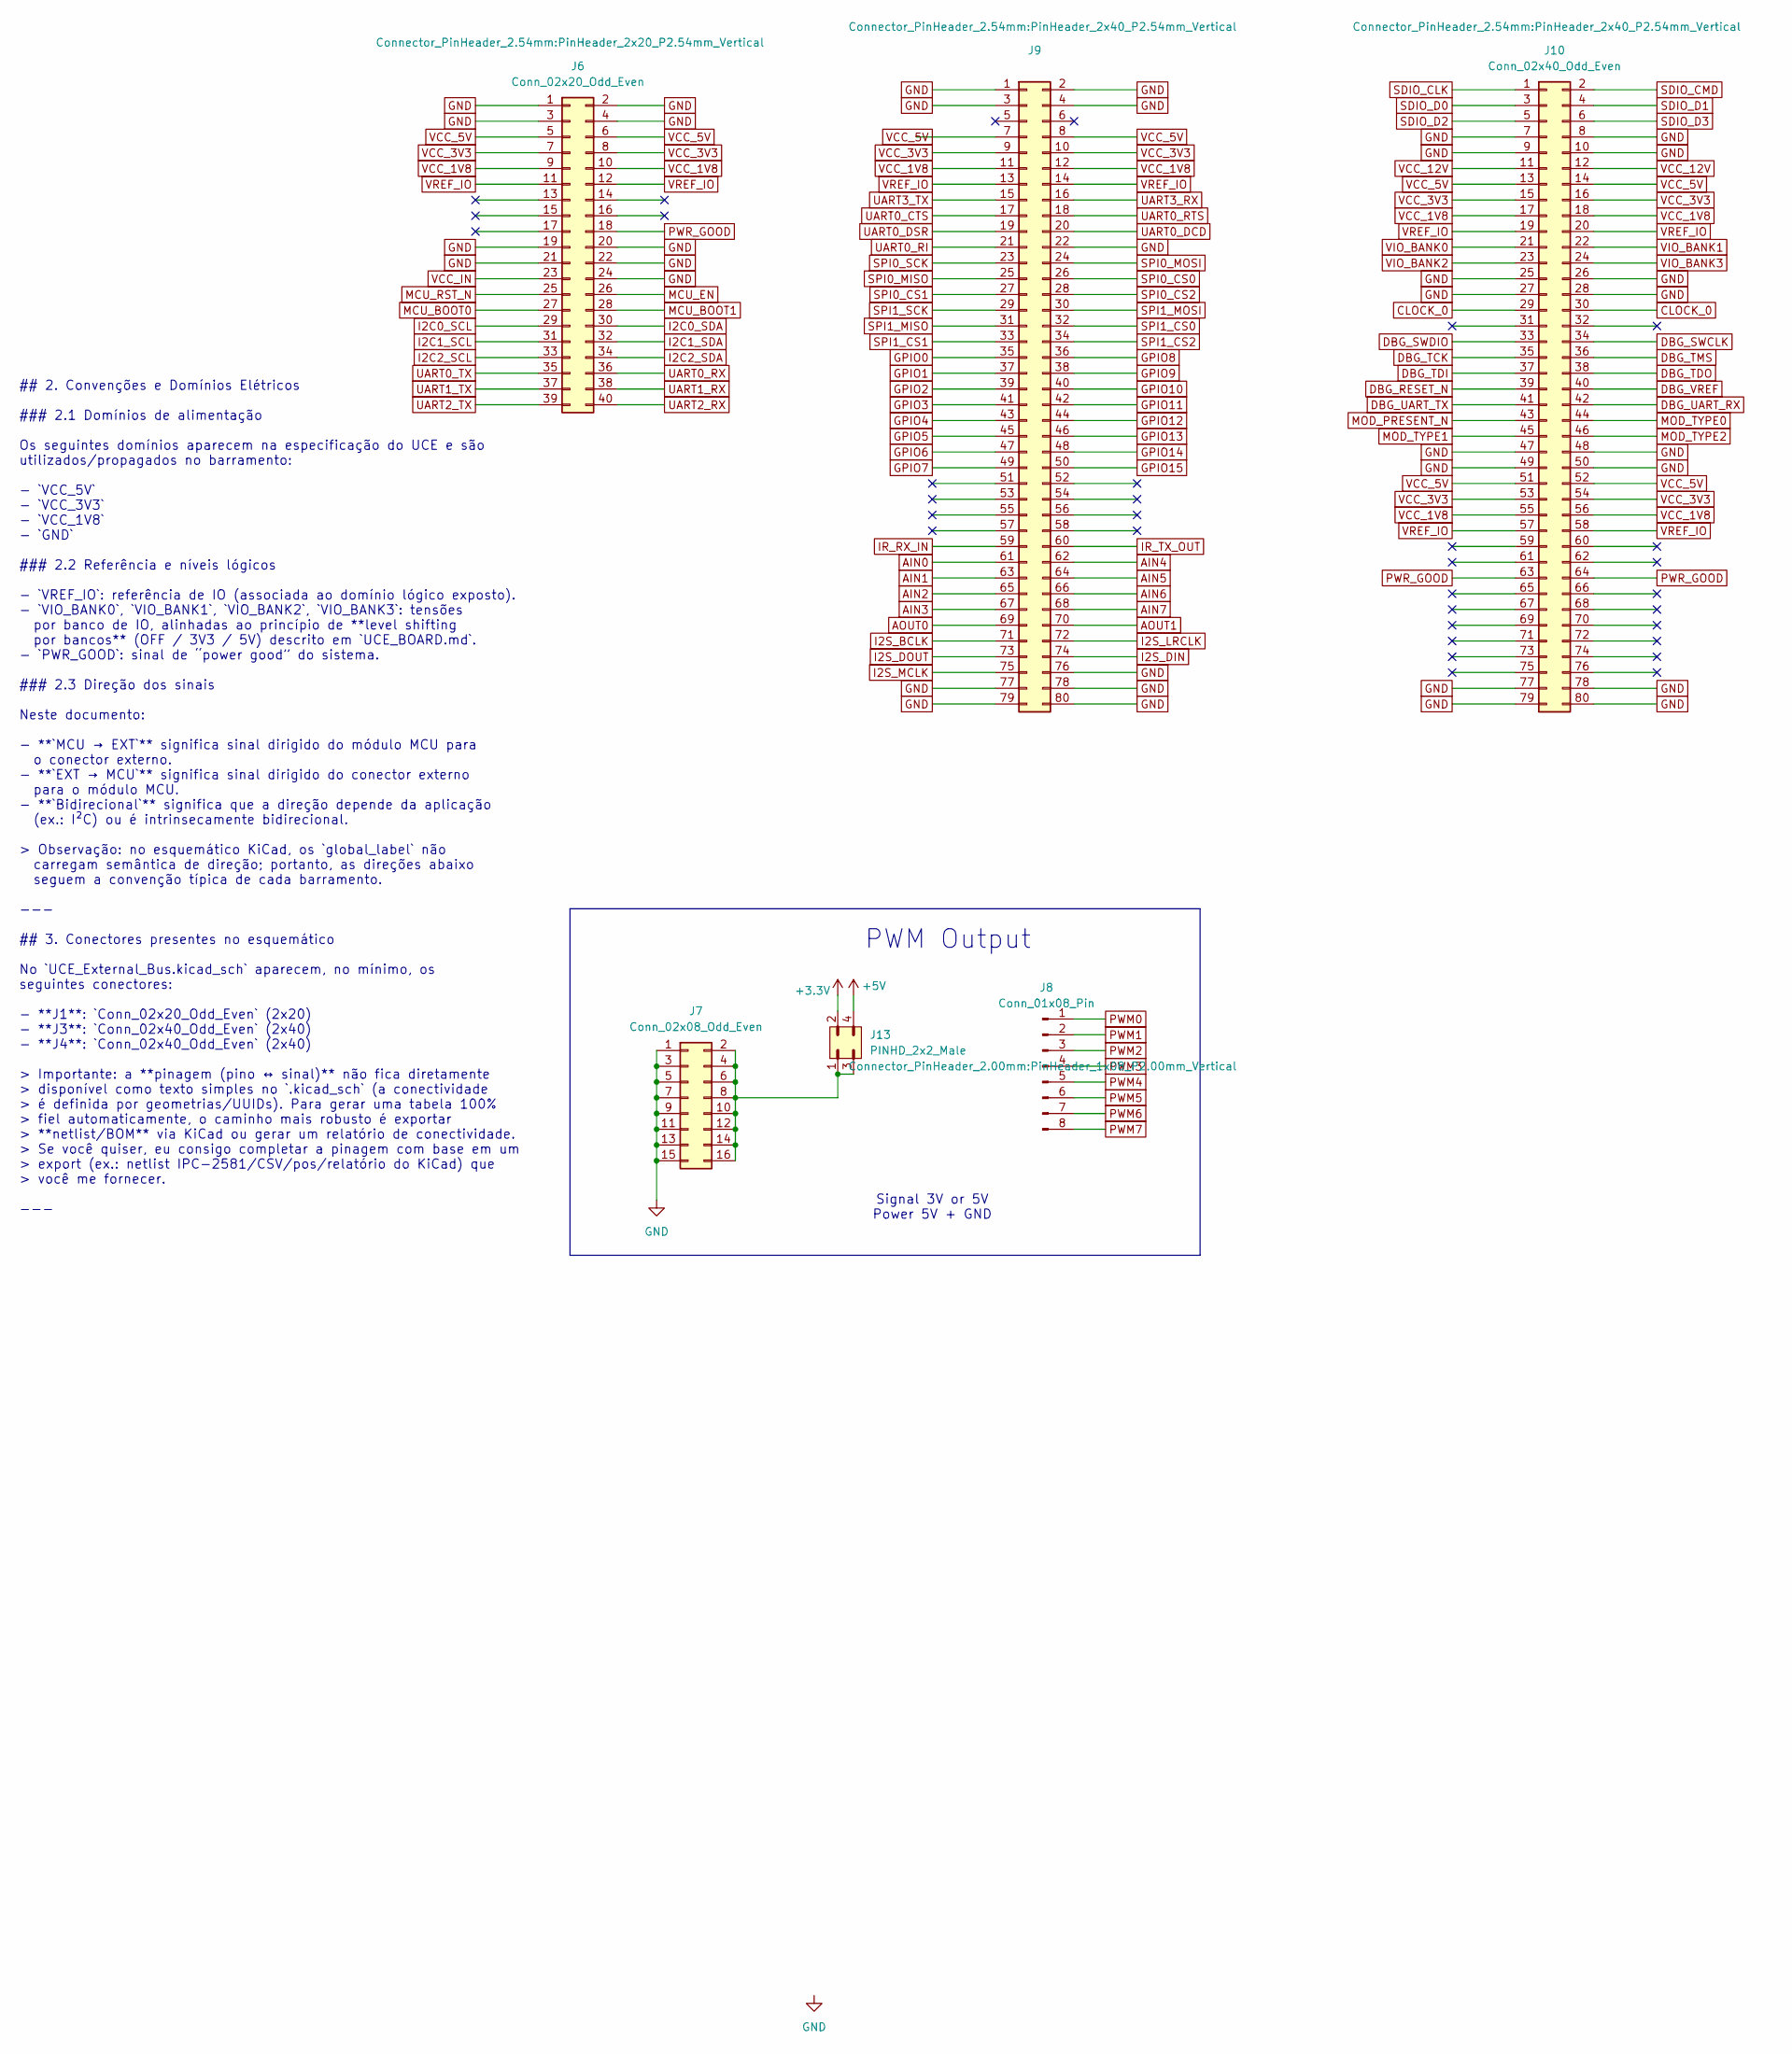
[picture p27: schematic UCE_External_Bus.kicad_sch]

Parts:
J6: Conn_02x20_Odd_Even; PinHeader_2x20_P2.54mm_Vertical
J7: Conn_02x08_Odd_Even; PinHeader_2x08_P2.00mm_Vertical
J8: Conn_01x08_Pin; PinHeader_1x08_P2.00mm_Vertical
J9, J10: Conn_02x40_Odd_Even; PinHeader_2x40_P2.54mm_Vertical
J13: PINHD_2x2_Male; PinHeader_2x02_P2.54mm_Vertical

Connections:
+1v8: J6.9, J6.10, J9.11, J9.12, J10.17, J10.18, J10.55, J10.56; also elsewhere on the board
+3.3V: J6.7, J6.8, J9.9, J9.10, J10.15, J10.16, J10.53, J10.54, J13.2; also elsewhere on the board
+5V: J6.5, J6.6, J9.7, J9.8, J10.13, J10.14, J10.51, J10.52, J13.4; also elsewhere on the board
+12V: J10.11, J10.12; also elsewhere on the board
AIN0: J9.61; also elsewhere on the board
AIN1: J9.63; also elsewhere on the board
AIN2: J9.65; also elsewhere on the board
AIN3: J9.67; also elsewhere on the board
AIN4: J9.62; also elsewhere on the board
AIN5: J9.64; also elsewhere on the board
AIN6: J9.66; also elsewhere on the board
AIN7: J9.68; also elsewhere on the board
AOUT0: J9.69; also elsewhere on the board
AOUT1: J9.70; also elsewhere on the board
CLOCK_0: J10.29, J10.30; also elsewhere on the board
DBG_RESET_N: J10.39; also elsewhere on the board
DBG_SWCLK: J10.34; also elsewhere on the board
DBG_SWDIO: J10.33; also elsewhere on the board
DBG_TCK: J10.35; also elsewhere on the board
DBG_TDI: J10.37; also elsewhere on the board
DBG_TDO: J10.38; also elsewhere on the board
DBG_TMS: J10.36; also elsewhere on the board
DBG_UART_RX: J10.42; also elsewhere on the board
DBG_UART_TX: J10.41; also elsewhere on the board
DBG_VREF: J10.40; also elsewhere on the board
GND: J6.1, J6.2, J6.3, J6.4, J6.19, J6.20, J6.21, J6.22, J6.24, J7.1, J7.3, J7.5, J7.7, J7.9, J7.11, J7.13, J7.15, J9.1, J9.2, J9.3, J9.4, J9.22, J9.76, J9.77, J9.78, J9.79, J9.80, J10.7, J10.8, J10.9, J10.10, J10.25, J10.26, J10.27, J10.28, J10.47, J10.48, J10.49, J10.50, J10.77, J10.78, J10.79, J10.80; also elsewhere on the board
GPIO0: J9.35; also elsewhere on the board
GPIO1: J9.37; also elsewhere on the board
GPIO2: J9.39; also elsewhere on the board
GPIO3: J9.41; also elsewhere on the board
GPIO4: J9.43; also elsewhere on the board
GPIO5: J9.45; also elsewhere on the board
GPIO6: J9.47; also elsewhere on the board
GPIO7: J9.49; also elsewhere on the board
GPIO8: J9.36; also elsewhere on the board
GPIO9: J9.38; also elsewhere on the board
GPIO10: J9.40; also elsewhere on the board
GPIO11: J9.42; also elsewhere on the board
GPIO12: J9.44; also elsewhere on the board
GPIO13: J9.46; also elsewhere on the board
GPIO14: J9.48; also elsewhere on the board
GPIO15: J9.50; also elsewhere on the board
I2C0_SCL: J6.29; also elsewhere on the board
I2C0_SDA: J6.30; also elsewhere on the board
I2C1_SCL: J6.31; also elsewhere on the board
I2C1_SDA: J6.32; also elsewhere on the board
I2C2_SCL: J6.33; also elsewhere on the board
I2C2_SDA: J6.34; also elsewhere on the board
I2S_BCLK: J9.71; also elsewhere on the board
I2S_DIN: J9.74; also elsewhere on the board
I2S_DOUT: J9.73; also elsewhere on the board
I2S_LRCLK: J9.72; also elsewhere on the board
I2S_MCLK: J9.75; also elsewhere on the board
IR_RX_IN: J9.59; also elsewhere on the board
IR_TX_OUT: J9.60; also elsewhere on the board
MCU_BOOT0: J6.27; also elsewhere on the board
MCU_BOOT1: J6.28; also elsewhere on the board
MCU_EN: J6.26; also elsewhere on the board
MCU_RST_N: J6.25; also elsewhere on the board
MOD_PRESENT_N: J10.43; also elsewhere on the board
MOD_TYPE0: J10.44; also elsewhere on the board
MOD_TYPE1: J10.45; also elsewhere on the board
MOD_TYPE2: J10.46; also elsewhere on the board
unnamed: J7.2, J7.4, J7.6, J7.8, J7.10, J7.12, J7.14, J7.16, J13.1, J13.3
PWM0: J8.1; also elsewhere on the board
PWM1: J8.2; also elsewhere on the board
PWM2: J8.3; also elsewhere on the board
PWM3: J8.4; also elsewhere on the board
PWM4: J8.5; also elsewhere on the board
PWM5: J8.6; also elsewhere on the board
PWM6: J8.7; also elsewhere on the board
PWM7: J8.8; also elsewhere on the board
PWR_GOOD: J6.18, J10.63, J10.64; also elsewhere on the board
SDIO_CLK: J10.1, J10.3; also elsewhere on the board
SDIO_CMD: J10.2; also elsewhere on the board
SDIO_D1: J10.4; also elsewhere on the board
SDIO_D2: J10.5; also elsewhere on the board
SDIO_D3: J10.6; also elsewhere on the board
SPI0_CS0: J9.26; also elsewhere on the board
SPI0_CS1: J9.27; also elsewhere on the board
SPI0_CS2: J9.28; also elsewhere on the board
SPI0_MISO: J9.25; also elsewhere on the board
SPI0_MOSI: J9.24; also elsewhere on the board
SPI0_SCK: J9.23; also elsewhere on the board
SPI1_CS0: J9.32; also elsewhere on the board
SPI1_CS1: J9.33; also elsewhere on the board
SPI1_CS2: J9.34; also elsewhere on the board
SPI1_MISO: J9.31; also elsewhere on the board
SPI1_MOSI: J9.30; also elsewhere on the board
SPI1_SCK: J9.29; also elsewhere on the board
UART0_CTS: J9.17; also elsewhere on the board
UART0_DCD: J9.20; also elsewhere on the board
UART0_DSR: J9.19; also elsewhere on the board
UART0_RI: J9.21; also elsewhere on the board
UART0_RTS: J9.18; also elsewhere on the board
UART0_RX: J6.36; also elsewhere on the board
UART0_TX: J6.35; also elsewhere on the board
UART1_RX: J6.38; also elsewhere on the board
UART1_TX: J6.37; also elsewhere on the board
UART2_RX: J6.40; also elsewhere on the board
UART2_TX: J6.39; also elsewhere on the board
UART3_RX: J9.16; also elsewhere on the board
UART3_TX: J9.15; also elsewhere on the board
VCC_IN: J6.23; also elsewhere on the board
VIO_BANK0: J10.21
VIO_BANK1: J10.22
VIO_BANK2: J10.23
VIO_BANK3: J10.24
VREF_IO: J6.11, J6.12, J9.13, J9.14, J10.19, J10.20, J10.57, J10.58; also elsewhere on the board

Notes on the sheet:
Signal 3V or 5V Power 5V + GND
## 2. Convenções e Domínios Elétricos ### 2.1 Domínios de alimentação Os seguintes domínios aparecem na especificação do UCE e são utilizados/propagados no barramento: - `VCC_5V` - `VCC_3V3` - `VCC_1V8` - `GND` ### 2.2 Referência e níveis lógicos - `VREF_IO`: referência de IO (associada ao domínio 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
PWM Output

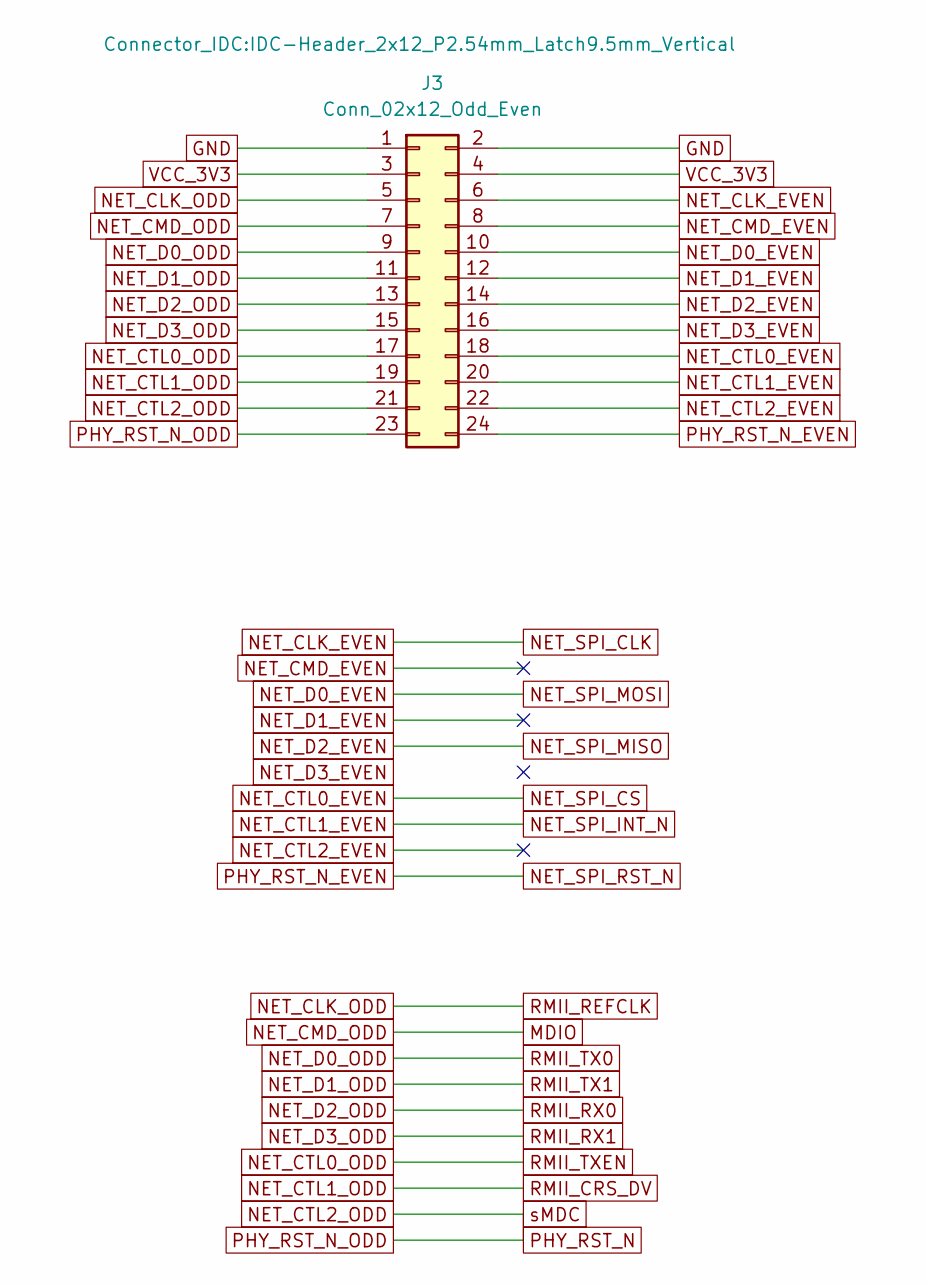
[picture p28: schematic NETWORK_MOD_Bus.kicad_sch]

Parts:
J3: Conn_02x12_Odd_Even; IDC-Header_2x12_P2.54mm_Latch9.5mm_Vertical

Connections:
+3.3V: J3.3, J3.4; also elsewhere on the board
GND: J3.1, J3.2; also elsewhere on the board
MDIO: J3.7; also elsewhere on the board
NET_CLK_EVEN: J3.6
NET_CLK_ODD: J3.5; also elsewhere on the board
NET_CMD_EVEN: J3.8
NET_CTL0_EVEN: J3.18; also elsewhere on the board
NET_CTL0_ODD: J3.17; also elsewhere on the board
NET_CTL1_EVEN: J3.20
NET_CTL1_ODD: J3.19; also elsewhere on the board
NET_CTL2_EVEN: J3.22
NET_CTL2_ODD: J3.21, J3.23; also elsewhere on the board
NET_D0_EVEN: J3.10; also elsewhere on the board
NET_D0_ODD: J3.9
NET_D1_EVEN: J3.12
NET_D1_ODD: J3.11
NET_D2_EVEN: J3.14; also elsewhere on the board
NET_D2_ODD: J3.13
NET_D3_EVEN: J3.16
NET_D3_ODD: J3.15
NET_SPI_RST_N: J3.24

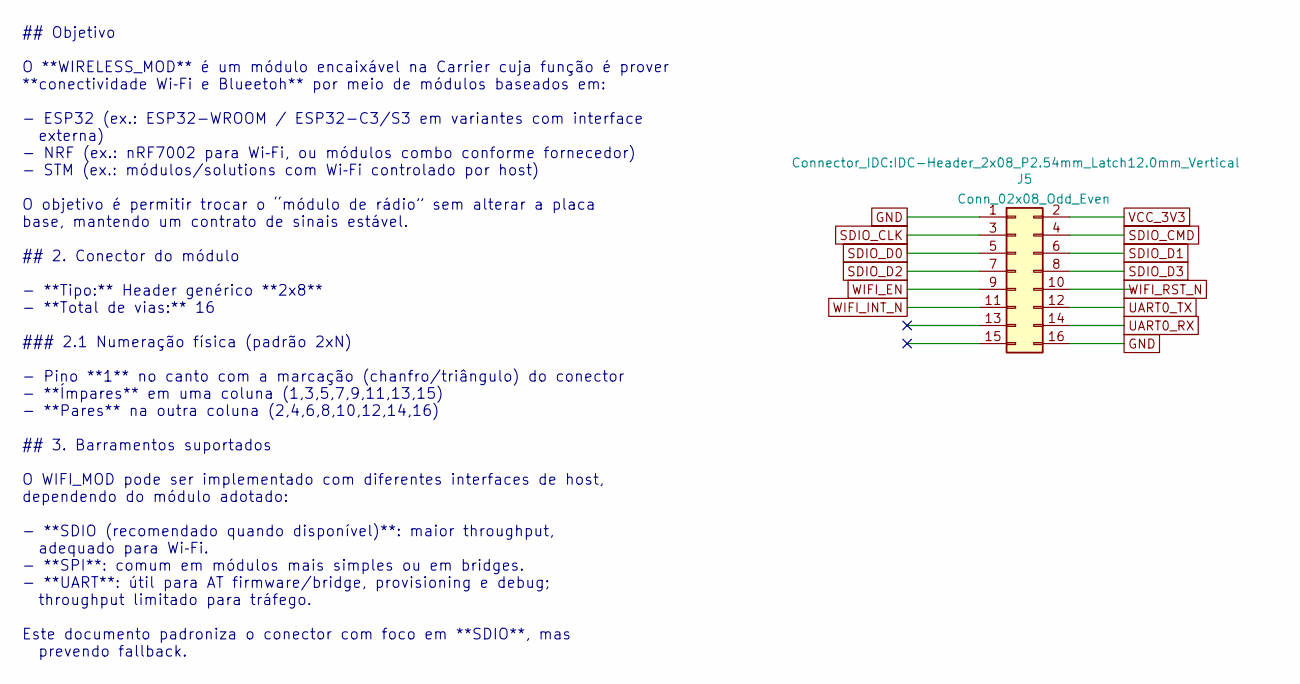
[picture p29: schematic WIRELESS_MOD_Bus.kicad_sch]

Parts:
J5: Conn_02x08_Odd_Even; IDC-Header_2x08_P2.54mm_Latch12.0mm_Vertical

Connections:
+3.3V: J5.2; also elsewhere on the board
GND: J5.1, J5.16; also elsewhere on the board
SDIO_CLK: J5.3, J5.5; also elsewhere on the board
SDIO_CMD: J5.4; also elsewhere on the board
SDIO_D1: J5.6; also elsewhere on the board
SDIO_D2: J5.7; also elsewhere on the board
SDIO_D3: J5.8; also elsewhere on the board
UART0_RX: J5.14; also elsewhere on the board
UART0_TX: J5.12; also elsewhere on the board
WIFI_EN: J5.9
WIFI_INT_N: J5.11
WIFI_RST_N: J5.10

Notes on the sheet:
## Objetivo O **WIRELESS_MOD** é um módulo encaixável na Carrier cuja função é prover **conectividade Wi‑Fi e Blueetoh** por meio de módulos baseados em: - ESP32 (ex.: ESP32-WROOM / ESP32-C3/S3 em variantes com interface externa) - NRF (ex.: nRF7002 para Wi‑Fi, ou módulos combo conforme fornecedor)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

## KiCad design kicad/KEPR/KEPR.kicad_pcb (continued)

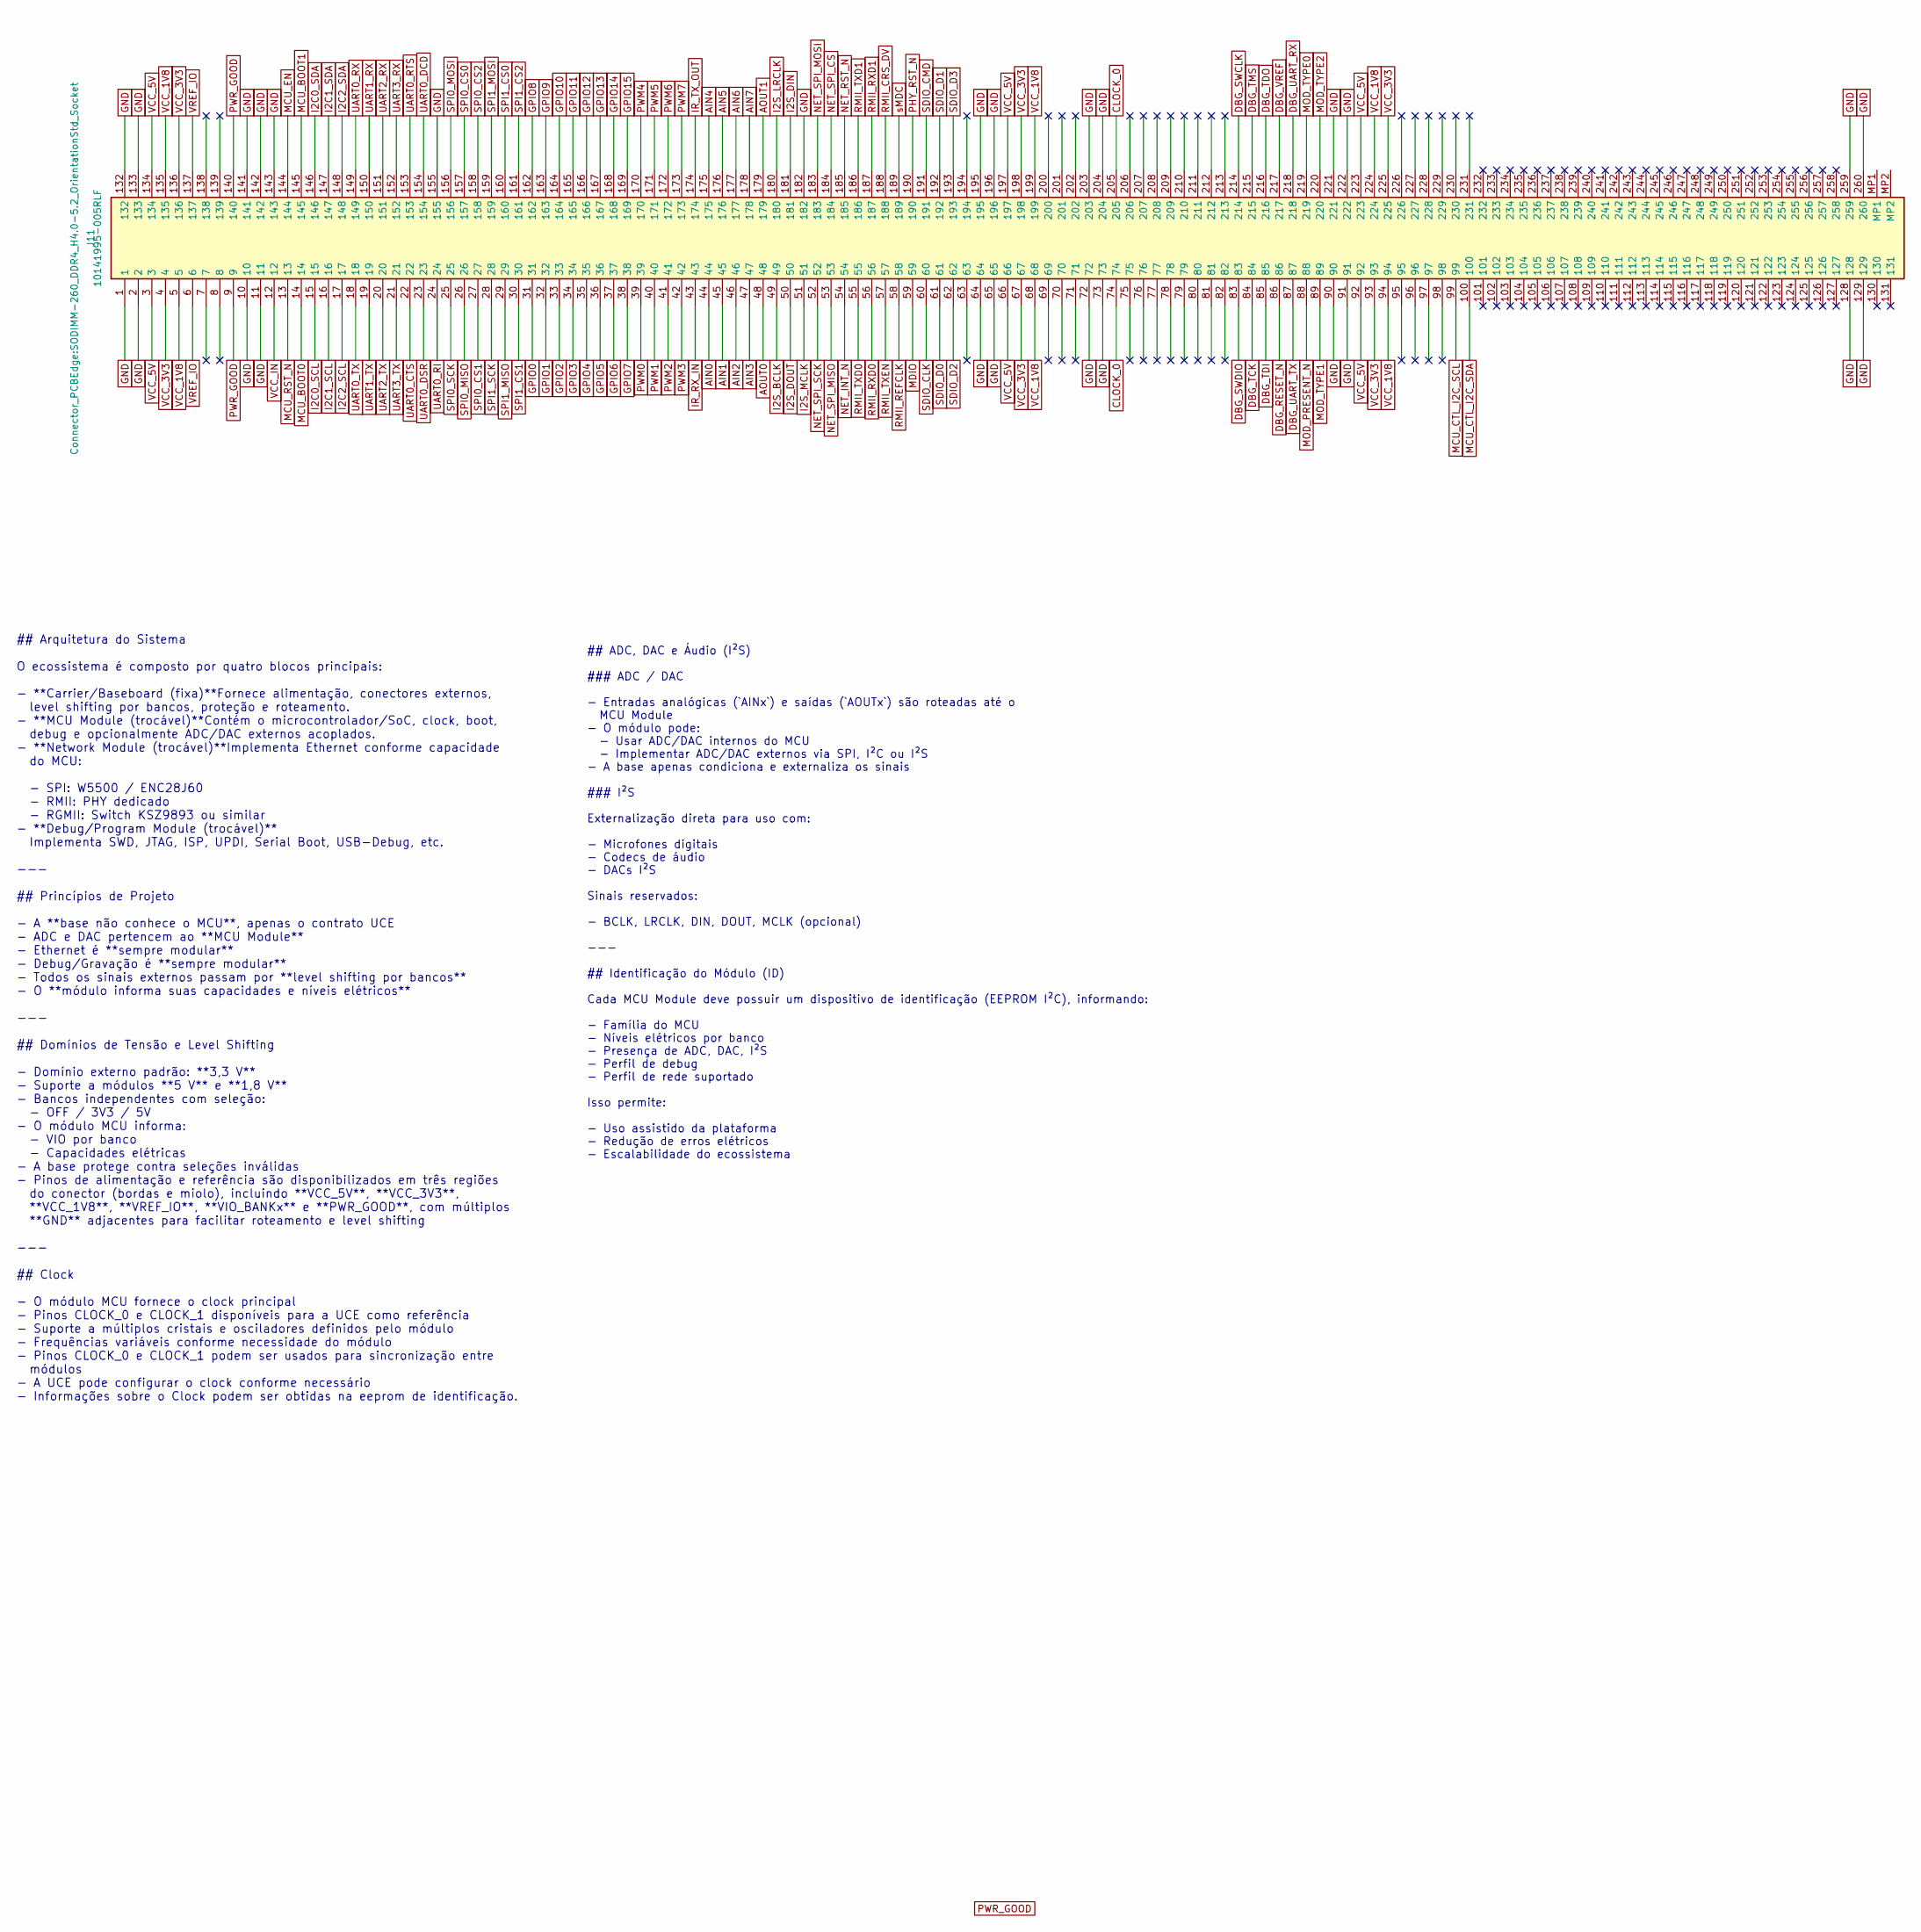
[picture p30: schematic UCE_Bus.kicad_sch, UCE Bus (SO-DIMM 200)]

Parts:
J11: 10141995-005RLF; SODIMM-260_DDR4_H4.0-5.2_OrientationStd_Socket; Manufacturer_Part_Number 10141995-005RLF

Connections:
+1v8: J11.5, J11.68, J11.94, J11.135, J11.199, J11.224; also elsewhere on the board
+3.3V: J11.4, J11.67, J11.93, J11.136, J11.198, J11.225; also elsewhere on the board
+5V: J11.3, J11.66, J11.92, J11.134, J11.197, J11.223; also elsewhere on the board
AIN0: J11.44; also elsewhere on the board
AIN1: J11.45; also elsewhere on the board
AIN2: J11.46; also elsewhere on the board
AIN3: J11.47; also elsewhere on the board
AIN4: J11.175; also elsewhere on the board
AIN5: J11.176; also elsewhere on the board
AIN6: J11.177; also elsewhere on the board
AIN7: J11.178; also elsewhere on the board
AOUT0: J11.48; also elsewhere on the board
AOUT1: J11.179; also elsewhere on the board
CLOCK_0: J11.74, J11.205; also elsewhere on the board
DBG_RESET_N: J11.86; also elsewhere on the board
DBG_SWCLK: J11.214; also elsewhere on the board
DBG_SWDIO: J11.83; also elsewhere on the board
DBG_TCK: J11.84; also elsewhere on the board
DBG_TDI: J11.85; also elsewhere on the board
DBG_TDO: J11.216; also elsewhere on the board
DBG_TMS: J11.215; also elsewhere on the board
DBG_UART_RX: J11.218; also elsewhere on the board
DBG_UART_TX: J11.87; also elsewhere on the board
DBG_VREF: J11.217; also elsewhere on the board
GND: J11.1, J11.2, J11.10, J11.11, J11.64, J11.65, J11.72, J11.73, J11.90, J11.91, J11.128, J11.129, J11.132, J11.133, J11.141, J11.142, J11.143, J11.155, J11.182, J11.195, J11.196, J11.203, J11.204, J11.221, J11.222, J11.259, J11.260; also elsewhere on the board
GPIO0: J11.31; also elsewhere on the board
GPIO1: J11.32; also elsewhere on the board
GPIO2: J11.33; also elsewhere on the board
GPIO3: J11.34; also elsewhere on the board
GPIO4: J11.35; also elsewhere on the board
GPIO5: J11.36; also elsewhere on the board
GPIO6: J11.37; also elsewhere on the board
GPIO7: J11.38; also elsewhere on the board
GPIO8: J11.162; also elsewhere on the board
GPIO9: J11.163; also elsewhere on the board
GPIO10: J11.164; also elsewhere on the board
GPIO11: J11.165; also elsewhere on the board
GPIO12: J11.166; also elsewhere on the board
GPIO13: J11.167; also elsewhere on the board
GPIO14: J11.168; also elsewhere on the board
GPIO15: J11.169; also elsewhere on the board
I2C0_SCL: J11.15; also elsewhere on the board
I2C0_SDA: J11.146; also elsewhere on the board
I2C1_SCL: J11.16; also elsewhere on the board
I2C1_SDA: J11.147; also elsewhere on the board
I2C2_SCL: J11.17; also elsewhere on the board
I2C2_SDA: J11.148; also elsewhere on the board
I2S_BCLK: J11.49; also elsewhere on the board
I2S_DIN: J11.181; also elsewhere on the board
I2S_DOUT: J11.50; also elsewhere on the board
I2S_LRCLK: J11.180; also elsewhere on the board
I2S_MCLK: J11.51; also elsewhere on the board
IR_RX_IN: J11.43; also elsewhere on the board
IR_TX_OUT: J11.174; also elsewhere on the board
MCU_BOOT0: J11.14; also elsewhere on the board
MCU_BOOT1: J11.145; also elsewhere on the board
MCU_CTL_I2C_SCL: J11.99; also elsewhere on the board
MCU_CTL_I2C_SDA: J11.100; also elsewhere on the board
MCU_EN: J11.144; also elsewhere on the board
MCU_RST_N: J11.13; also elsewhere on the board
MDIO: J11.59; also elsewhere on the board
MOD_PRESENT_N: J11.88; also elsewhere on the board
MOD_TYPE0: J11.219; also elsewhere on the board
MOD_TYPE1: J11.89; also elsewhere on the board
MOD_TYPE2: J11.220; also elsewhere on the board
NET_CLK_ODD: J11.58; also elsewhere on the board
NET_CTL0_EVEN: J11.184; also elsewhere on the board
NET_CTL0_ODD: J11.57; also elsewhere on the board
NET_CTL1_ODD: J11.188; also elsewhere on the board
NET_CTL2_ODD: J11.189, J11.190; also elsewhere on the board
NET_D0_EVEN: J11.183; also elsewhere on the board
NET_D2_EVEN: J11.53; also elsewhere on the board
NET_INT_N: J11.54
NET_RST_N: J11.185
NET_SPI_SCK: J11.52
PWM0: J11.39; also elsewhere on the board
PWM1: J11.40; also elsewhere on the board
PWM2: J11.41; also elsewhere on the board
PWM3: J11.42; also elsewhere on the board
PWM4: J11.170; also elsewhere on the board
PWM5: J11.171; also elsewhere on the board
PWM6: J11.172; also elsewhere on the board
PWM7: J11.173; also elsewhere on the board
PWR_GOOD: J11.9, J11.140; also elsewhere on the board
RMII_RXD0: J11.56
RMII_RXD1: J11.187
RMII_TXD0: J11.55
RMII_TXD1: J11.186
SDIO_CLK: J11.60, J11.61; also elsewhere on the board
SDIO_CMD: J11.191; also elsewhere on the board
SDIO_D1: J11.192; also elsewhere on the board
SDIO_D2: J11.62; also elsewhere on the board
SDIO_D3: J11.193; also elsewhere on the board
SPI0_CS0: J11.157; also elsewhere on the board
SPI0_CS1: J11.27; also elsewhere on the board
SPI0_CS2: J11.158; also elsewhere on the board
SPI0_MISO: J11.26; also elsewhere on the board
SPI0_MOSI: J11.156; also elsewhere on the board
SPI0_SCK: J11.25; also elsewhere on the board
SPI1_CS0: J11.160; also elsewhere on the board
SPI1_CS1: J11.30; also elsewhere on the board
SPI1_CS2: J11.161; also elsewhere on the board
SPI1_MISO: J11.29; also elsewhere on the board
SPI1_MOSI: J11.159; also elsewhere on the board
SPI1_SCK: J11.28; also elsewhere on the board
UART0_CTS: J11.22; also elsewhere on the board
UART0_DCD: J11.154; also elsewhere on the board
UART0_DSR: J11.23; also elsewhere on the board
UART0_RI: J11.24; also elsewhere on the board
UART0_RTS: J11.153; also elsewhere on the board
UART0_RX: J11.149; also elsewhere on the board
UART0_TX: J11.18; also elsewhere on the board
UART1_RX: J11.150; also elsewhere on the board
UART1_TX: J11.19; also elsewhere on the board
UART2_RX: J11.151; also elsewhere on the board
UART2_TX: J11.20; also elsewhere on the board
UART3_RX: J11.152; also elsewhere on the board
UART3_TX: J11.21; also elsewhere on the board
VCC_IN: J11.12; also elsewhere on the board
VREF_IO: J11.6, J11.137; also elsewhere on the board

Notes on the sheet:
## Arquitetura do Sistema O ecossistema é composto por quatro blocos principais: - **Carrier/Baseboard (fixa)**Fornece alimentação, conectores externos, level shifting por bancos, proteção e roteamento. - **MCU Module (trocável)**Contém o microcontrolador/SoC, clock, boot, debug e opcionalmente ADC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
## ADC, DAC e Áudio (I²S) ### ADC / DAC - Entradas analógicas (`AINx`) e saídas (`AOUTx`) são roteadas até o MCU Module - O módulo pode: - Usar ADC/DAC internos do MCU - Implementar ADC/DAC externos via SPI, I²C ou I²S - A base apenas condiciona e externaliza os sinais ### I²S Externalização direta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

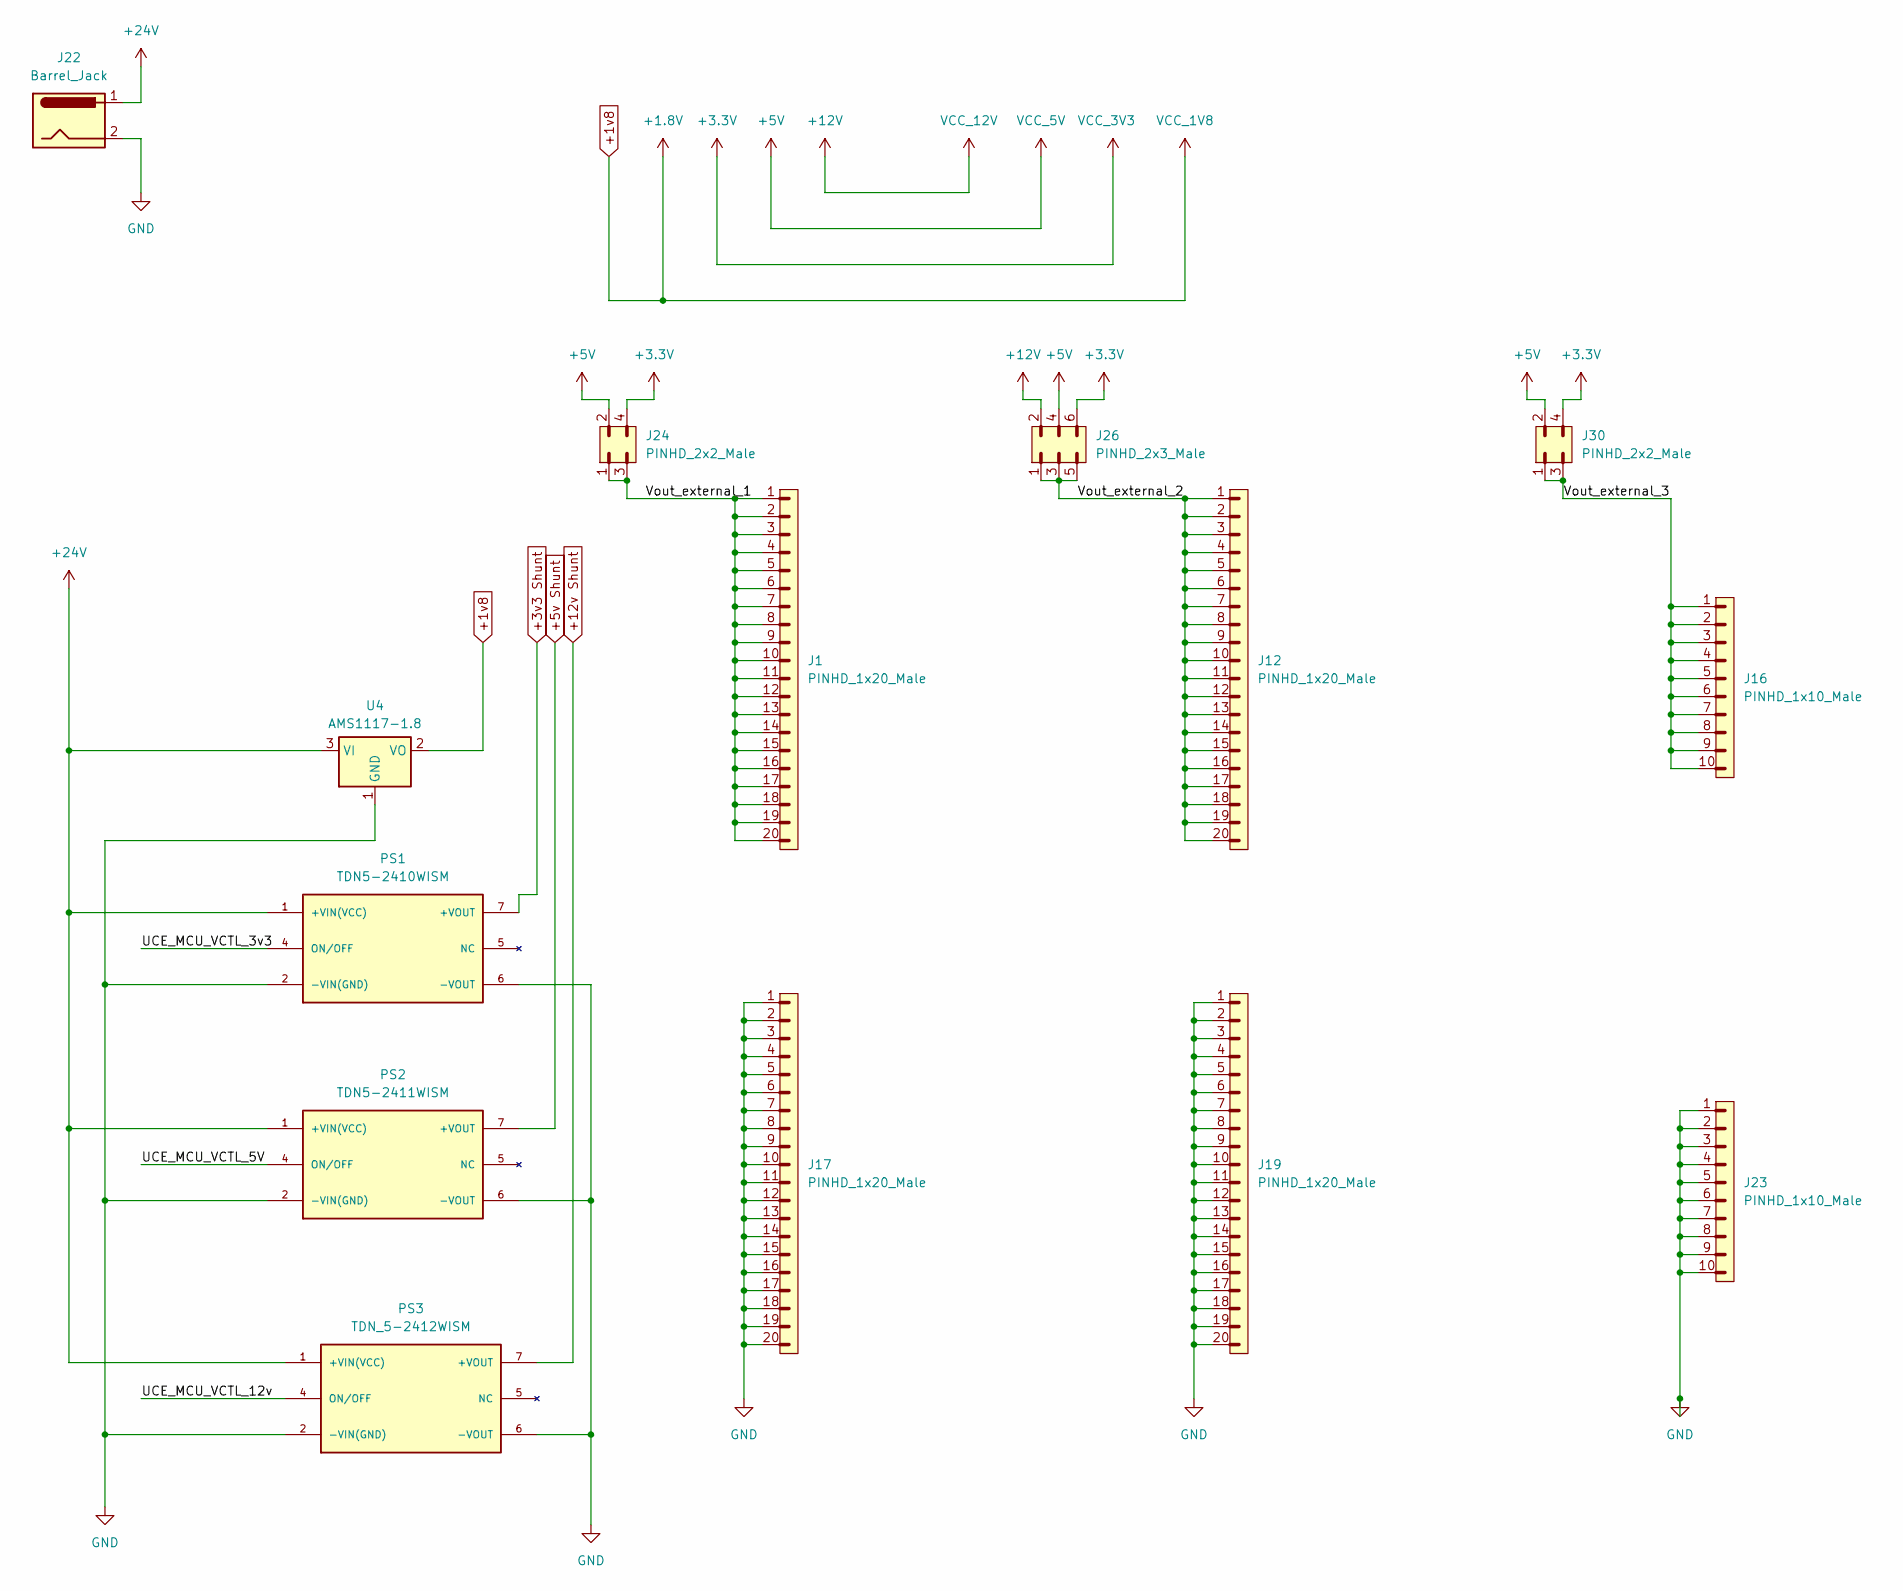
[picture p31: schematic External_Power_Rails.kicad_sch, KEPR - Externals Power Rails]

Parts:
J1, J12, J17, J19: PINHD_1x20_Male; PinHeader_1x20_P2.54mm_Vertical
J16, J23: PINHD_1x10_Male; PinHeader_1x10_P2.54mm_Vertical
J22: Barrel_Jack; BarrelJack_Horizontal
J24, J30: PINHD_2x2_Male; PinHeader_2x02_P2.54mm_Vertical
J26: PINHD_2x3_Male; PinHeader_2x03_P2.54mm_Vertical
PS1: TDN5-2410WISM; CONV_TDN5-2411WISM; PARTREV May 18, 2020
PS2: TDN5-2411WISM; CONV_TDN5-2411WISM; PARTREV August 17, 2020
PS3: TDN_5-2412WISM; CONV_TDN5-2411WISM; PARTREV August 17, 2020
U4: AMS1117-1.8; SOT-223-3_TabPin2

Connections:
+1v8: U4.2 (VO); also elsewhere on the board
+3.3V: J24.4, J26.6, J30.4; also elsewhere on the board
+3v3 Shunt: PS1.7 (+VOUT); also elsewhere on the board
+5V: J24.2, J26.4, J30.2; also elsewhere on the board
+5v Shunt: PS2.7 (+VOUT); also elsewhere on the board
+12V: J26.2; also elsewhere on the board
+12v Shunt: PS3.7 (+VOUT); also elsewhere on the board
+24V: J22.1, PS1.1 (+VIN(VCC)), PS2.1 (+VIN(VCC)), PS3.1 (+VIN(VCC)), U4.3 (VI)
/Power/Power Rails/UCE_MCU_VCTL_3v3: PS1.4 (ON/OFF)
/Power/Power Rails/UCE_MCU_VCTL_5V: PS2.4 (ON/OFF)
/Power/Power Rails/UCE_MCU_VCTL_12v: PS3.4 (ON/OFF)
/Power/Power Rails/Vout_external_1: J1.1, J1.2, J1.3, J1.4, J1.5, J1.6, J1.7, J1.8, J1.9, J1.10, J1.11, J1.12, J1.13, J1.14, J1.15, J1.16, J1.17, J1.18, J1.19, J1.20, J24.1, J24.3
/Power/Power Rails/Vout_external_2: J12.1, J12.2, J12.3, J12.4, J12.5, J12.6, J12.7, J12.8, J12.9, J12.10, J12.11, J12.12, J12.13, J12.14, J12.15, J12.16, J12.17, J12.18, J12.19, J12.20, J26.1, J26.3, J26.5
/Power/Power Rails/Vout_external_3: J16.1, J16.2, J16.3, J16.4, J16.5, J16.6, J16.7, J16.8, J16.9, J16.10, J30.1, J30.3
GND: J17.1, J17.2, J17.3, J17.4, J17.5, J17.6, J17.7, J17.8, J17.9, J17.10, J17.11, J17.12, J17.13, J17.14, J17.15, J17.16, J17.17, J17.18, J17.19, J17.20, J19.1, J19.2, J19.3, J19.4, J19.5, J19.6, J19.7, J19.8, J19.9, J19.10, J19.11, J19.12, J19.13, J19.14, J19.15, J19.16, J19.17, J19.18, J19.19, J19.20, J22.2, J23.1, J23.2, J23.3, J23.4, J23.5, J23.6, J23.7, J23.8, J23.9, J23.10, PS1.2 (-VIN(GND)), PS1.6 (-VOUT), PS2.2 (-VIN(GND)), PS2.6 (-VOUT), PS3.2 (-VIN(GND)), PS3.6 (-VOUT), U4.1 (GND); also elsewhere on the board

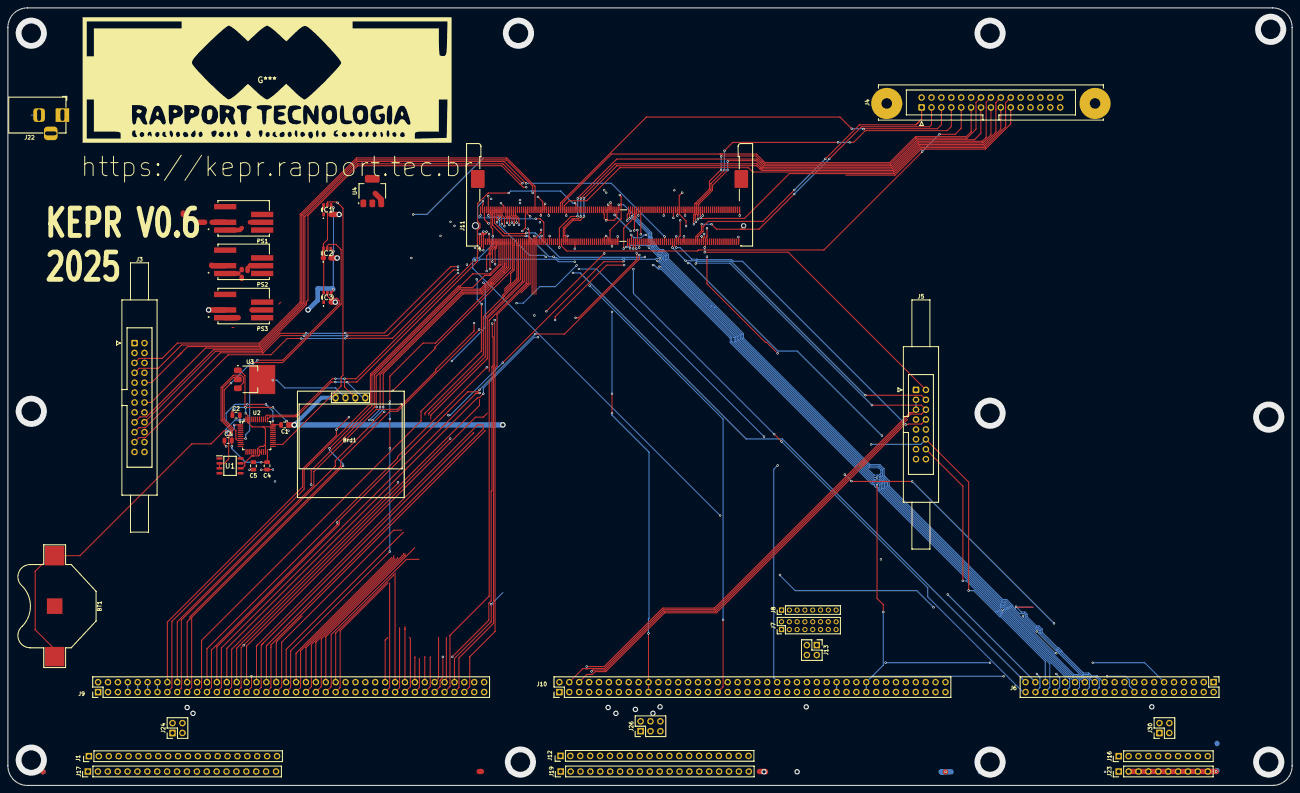
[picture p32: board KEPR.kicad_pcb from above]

Board: 4 copper layers, 329.5 x 199.5 mm, 37 parts (0 on the bottom side), 128 nets.

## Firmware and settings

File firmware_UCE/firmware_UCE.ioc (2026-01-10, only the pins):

Mcu.UserName=STM32G484CETx
PA0.Signal=ADC1_IN1
PA1.Signal=ADC2_IN2
PA13.Signal=I2C1_SCL
PA14.Signal=I2C1_SDA
PB12.Signal=ADC4_IN3

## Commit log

2025-12-31 Projeto KiCAD
    [UCE_Bus.kicad_pcb, UCE_Bus.kicad_sch]
2025-12-31 Finalizado versão 0.4 do conector do UCE para o módulo.
    [UCE_Bus.kicad_sch]
2025-12-31 Correção no pino reservado que é mais adequado como GND
2025-12-31 Ajustado a hierarquia de esquemáticos para melhorar o planejamento da placa.
    [BUSes.kicad_sch, DEBUG_MOD_Bus.kicad_sch, KEPR.kicad_sch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]
2026-01-01 Definido os demais buses, criado folha do carimbo, versão 0.5
    [BUSes.kicad_sch, DEBUG_MOD_Bus.kicad_sch, KEPR.kicad_sch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]
2026-01-01 Adicinado o barramento externo
    [DEBUG_MOD_Bus.kicad_sch, NETWORK_MOD_Bus.kicad_sch, UCE_External_Bus.kicad_sch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]
2026-01-01 Iniciado projeto da PCB, para uma referência de tamanho.
    [DEBUG_MOD_Bus.kicad_sch, KEPR.kicad_pcb, NETWORK_MOD_Bus.kicad_sch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]
2026-01-01 Adicionado Footprints, criado a visualização da PCB
    [KEPR.kicad_pcb, UCE_Bus.kicad_sch]
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2026-01-02 Remove cron schedule from kicad-ci workflow
    Removed scheduled cron job from workflow dispatch.
2026-01-07 ajustado as folhas de desenho para padronizar o nome.
2026-01-07 Vários ajuste, sendo o mais importante a adição do power rail e iniciado o Wireless module
    [BUSes.kicad_sch, DEBUG_MOD_Bus.kicad_sch, KEPR.kicad_pcb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]
2026-01-07 mais ajustes no power rail inclusive com imagem 3d
    [KEPR.kicad_pcb, POWER_Rails.kicad_sch]
2026-01-07 Mais ajustes nas folhas de esquemático no Power Rails
    [External_Power_Rails.kicad_sch, POWER_Rails.kicad_sch]
2026-01-08 Adicionado conversores DC-DC e Logo da Rapport
    [External_Power_Rails.kicad_sch, KEPR.kicad_pcb, KEPR.kicad_sch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]
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2026-01-08 Adcicionado lista de fornecedores, e menu para acesso
2026-01-08 Application note sobre implementação de sistemas de gerenciamento de energia
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2026-01-08 Mais um datasheet para estudo de um mcu para controle da UCE
    Estou pesquisando qual o melhor microcontrolador para fazer o controle
    da placa mãe UCE, tenho tido problemas quanto ao uso dos opamps,
    acredito que terei que usar externamente.
2026-01-08 Diversos ajustes no Power Rail
    [External_Power_Rails.kicad_sch, KEPR.kicad_pcb, KEPR.kicad_sch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]
2026-01-08 Mais ajustes no roteamento
    [KEPR.kicad_pcb, UCE_board.kicad_sch]
2026-01-09 Removido a inclinação da placa, pois não está aceitando a chave de comando
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2026-01-09 Como calcular a corrente no Power Rail e identificar a tensão efetiva
2026-01-09 Ajustes para uso do FreeRTOS e parametros dos ADCs
2026-01-09 Tutorial sobre calculo do Zener para regular tensão do STM32G484CETx
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2026-01-09 Melhorado o README, adicionado contador de visitas e licença
2026-01-09 Automátizado a geração de lista BOM e esquemáticos.
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2026-01-09 Diversos ajustes como páginas par acategorias, mais páginas de informação
2026-01-09 Tutorial sobre soluções de proteção de tensões reversas e sobretenção
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2026-01-09 Gera os esquemáticos para uso nas páginas do site
2026-01-09 Gera o relatório ERC e DRC para exibir no site
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2026-01-09 Script e CI para gerar a lista de livros
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2026-01-09 Mais datasheets e app notes, ignorado os que são irrelevantes atualmente
2026-01-09 Ajustes no Power Rail, entre outros ajustes.
    [External_Power_Rails.kicad_sch, KEPR.kicad_pcb, UCE_Bus.kicad_sch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]
2026-01-09 Adicionado holder para bateria.
    [KEPR.kicad_pcb, UCE_board.kicad_sch]
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2026-01-10 Troca dos sensores de corrente e conversores de tensão para o MCU controlador
    [KEPR.kicad_pcb, UCE_board.kicad_sch]
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2026-01-10 Atualizado informações para a versão 0.6
    [BUSes.kicad_sch, DEBUG_MOD_Bus.kicad_sch, External_Power_Rails.kicad_sch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]
2026-01-10 Ajustado links para que sejam clicáveis, ajustado o nome da página Fornecedores
2026-01-11 Iniciado a distribuição das vias.
    [DEBUG_MOD_Bus.kicad_sch, External_Power_Rails.kicad_sch, KEPR.kicad_pcb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]
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2026-01-11 Correção no nome do Autor para diferenciar do outro eBook
2026-01-11 Adicionado a primeira versão da MCU Board, inicado com STM32N6
    [MCU_Board_STM32N6.kicad_pcb, MCU_Board_STM32N6.kicad_sch, MCU_Board_STM32N6_Bus.kicad_sch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]
2026-01-12 Ajustes para o MCU Board STM32N6
    [KEPR.kicad_pcb]
2026-01-12 Verificando a compatibilidade do geber com o corte multiplaca
    [KEPR-B_Cu.gbr, KEPR-B_Mask.gbr, KEPR-B_Paste.gbr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]
2026-01-12 Layout da placa para encaixe no SODIMM 260pin
    [DDR4 SODIMM 260pin SMT, 8.0H, STANDARD VERSION, board.kicad_pcb]
2026-01-12 ainda fazendo testes com o Gerbers
    [KEPR-B_Cu.gbr, KEPR-B_Mask.gbr, KEPR-B_Paste.gbr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]
2026-01-12 ainda fazendo testes de composição das placas.
    [KEPR.kicad_pcb]
2026-01-12 Script para gerar multiplas placas(pcb) e multiplos BOM
    [KEPR-bom.csv]
2026-01-12 Diversos ajustes no barramento e ampliação das trilhas na PCB
    [External_Power_Rails.kicad_sch, KEPR.kicad_pcb, UCE_Bus.kicad_sch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]
2026-01-13 Adicionado o display oled e mais trilhas.
    [KEPR.kicad_pcb, UCE_Bus.kicad_sch, UCE_board.kicad_sch]
2026-01-13 Removido pcb do módulo sodimm de referência.
    [DDR4 SODIMM 260pin SMT, 8.0H, STANDARD VERSION, board.kicad_pcb]
2026-01-14 Ajustando trilhas
    [External_Power_Rails.kicad_sch, KEPR.kicad_pcb, UCE_External_Bus.kicad_sch]
2026-01-15 mais ajustes de trilha.
    [External_Power_Rails.kicad_sch, KEPR.kicad_pcb, NETWORK_MOD_Bus.kicad_sch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]
2026-01-16 Mais trilhas e vias lançadas
    [KEPR.kicad_pcb, UCE_Bus.kicad_sch, UCE_External_Bus.kicad_sch]

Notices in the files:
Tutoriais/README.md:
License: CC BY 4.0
